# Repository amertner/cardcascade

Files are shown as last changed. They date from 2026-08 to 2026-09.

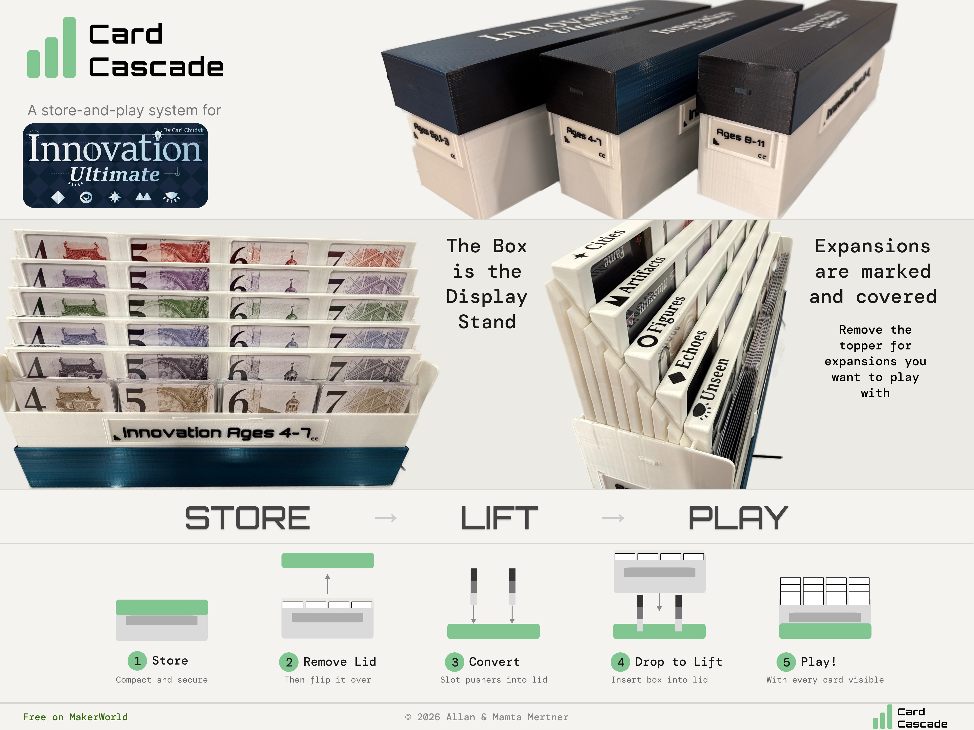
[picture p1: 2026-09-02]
cascades/Innovation/IU Poster Landscape.png

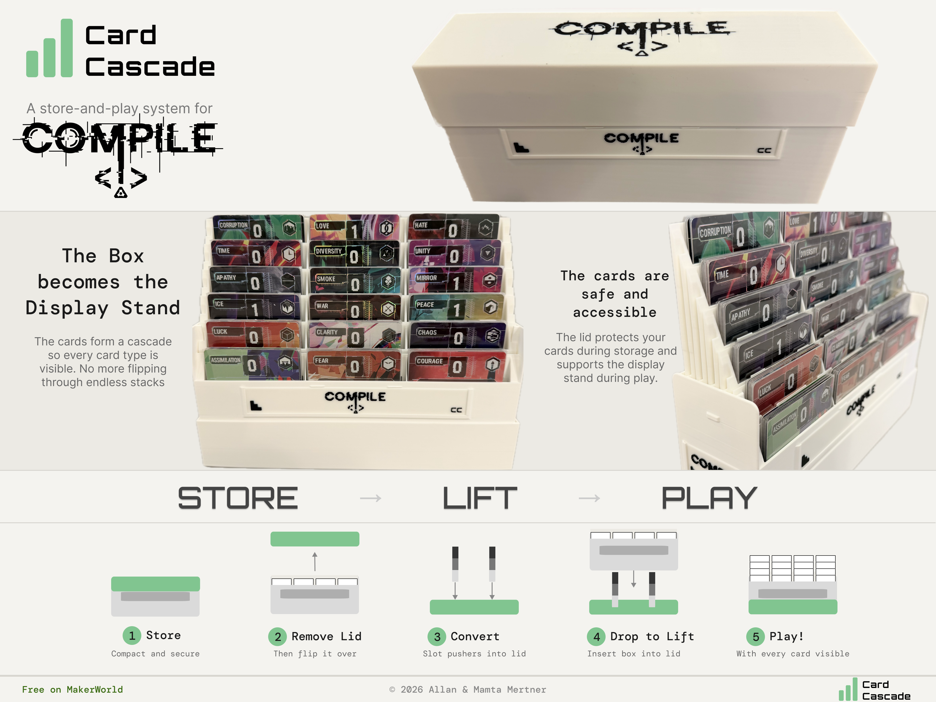
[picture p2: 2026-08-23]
cascades/Compile/Compile Poster.png

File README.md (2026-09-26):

# Card Cascade

3D-printed **store-and-play** boxes for card games: closed, a labelled box
on the shelf; open, the sliding holders rise in a staircase so every pile
shows its top card. Free Bambu Studio projects for Dominion, Innovation,
Compile and Food Chain Magnate on
[MakerWorld](https://makerworld.com/en/collections/33559137-card-cascades).

**Is there one for your game?** [`CATALOGUE.md`](CATALOGUE.md) lists every
cascade with the card size it is cut for, capacity, outside size and the
printer bed it needs; most card games use one of those card sizes. Questions,
prints and requests: [r/cardcascade](https://www.reddit.com/r/cardcascade/).

The rest of this file is about the **labels**; the boxes themselves are
generated from `cad/` (see `cad/README.md` and `CLAUDE.md`).

# Dominion Expansion Box Labels

Generates the expansion-name labels as **two-colour 3MF files** (white
chamfered base plate + black raised name/logo/"cc"), replicating the
original Onshape design. One command produces every name in every size.

## Setup (macOS)

```bash
cd cardcascade
python3 -m venv .venv
.venv/bin/pip install build123d
```

That's it — `Orbitron-Bold.ttf` is bundled (Google Fonts, OFL licence).

> Note: use this bundled *static* Bold TTF. The variable-weight
> `Orbitron[wght].ttf` that Google Fonts' "Download family" button gives
> you crashes the OpenCascade text engine that build123d uses.

## Usage

```bash
# individual label files for every cc.cfg entry of the default game (Dominion)
.venv/bin/python labelmaker.py

# multi-plate Bambu project 3MFs (whole sets + split-box labels)
.venv/bin/python labelmaker.py --plates

# one 3MF per set (default / split boxes / spares plates) — the DEFAULT mode
.venv/bin/python labelmaker.py

# another game (its own cc.cfg entries and width lists)
.venv/bin/python labelmaker.py --game FCM --plates

# specific sets / widths
.venv/bin/python labelmaker.py --names "Seaside,Renaissance" --widths 32,53

# also write STEP files (e.g. to re-import into Onshape)
.venv/bin/python labelmaker.py --step

# skip the blank label
.venv/bin/python labelmaker.py --no-blank

# vanilla 3MF without the Bambu Studio filament metadata
.venv/bin/python labelmaker.py --plain
```

Output lands in `labels_out/` as `<Name>_<width>mm.3mf`, or as
`<game>_plates.3mf` with `--plates`.

Each game in the `GAMES` dict at the top of the script defines the
label widths for a set (`widths`), for split-box `<name> 1/2` labels
(`split_widths`), and the standard text size per width (`caps`,
capital height in mm). Dominion: 156.4 (front), 62, 45, 32 at
6.5/5.0/4.5/3.5 mm caps; FCM: 156.4 (front), 45, 32, 20 at
6.5/4.5/3.5/2.8 mm; Innovation: 156.4 (front), 62, 45, 32, 20 at
6.5/5.0/4.5/3.5/2.8 mm — the 32 and 20 serve the Single Set box, whose
lids are 50.6 and 39.3 mm deep.

## The cc.cfg configuration file

When `--names` is not given, the script reads the configuration from a
`cc.cfg` file (looked up in the current directory, then next to the
script). One set per line as `<game>,<set name>[,<key>=V]...`, where
every value `V` is `<unsleeved>[/<sleeved>][@<box name>:<base model>]`
— side-label widths per sleeving (one value = both; 0 = no side label
for that sleeving) plus the optional recommended-box identity. Plate
titles show the full model composed from the base model and the
plate's width, e.g. `Base Set 560 Card-S (L6.40.12.62-Sl)` — `-U`/`-S`
marks the sleevedness and is omitted on plates covering both. Only
lines
matching `--game` are used:

| Field | Meaning |
|---|---|
| `box=V` | the whole set's box; presence means the set gets whole-box labels |
| `split=V` | both split half-boxes; presence means the set gets `<name> 1/2` labels |
| `split1=V`, `split2=V` | like `split=` but for half-boxes of different sizes (must appear together) |
| `side=<text>` | short text printed on side labels instead of the set name (fronts keep the full name), e.g. `side=FCM/O` |
| `plate=<title>:<w1>+<w2>+...` | an extra plate in the set's 3MF with exactly these label widths — free-form, not limited to the standard widths (used for the Blank set's legacy CC 5.1 sizes); repeatable |
| `parts=<w1>+...@<l1>\|<l2>\|...[#<tag>]` | the set spans several cascades, one per label: fronts read `<name> <label>`, sides just `<label>`. Repeatable, one grouping per way of splitting the set — every grouping becomes a 3MF of its own (see "Per-set project files"), named `<part count> Cascades`, or `<tag> Cascades` when a `#<tag>` is given. Tag a grouping when two would otherwise share a file name, or when the number worth showing is not the box count. A label may contain a comma; only a comma that begins another `key=` splits a field. ` / ` in a label breaks the line (`Innovation / Unseen, Echoes`, the first name over the other two); on a side-width plate a `, ` list is stacked one name a line as well. A stacked label, or one that already starts with the set name, prints as written on the front, without the set-name prefix |
| `names=<w1>+...@<n1>[:<short>]\|<n2>...` | the **transpose** of `parts=`: one plate per *name*, each holding every width, so a plate is exactly one box's labels. For a box design that ships once per expansion. The **narrowest** width takes the short form when one is given; every other width, front and side alike, takes the full name — a long name only shrinks past legibility at the bottom of the range ("Innovation" sets at 1.61 mm on a 20 mm label but 3.11 mm on a 32 mm one), so shortening every side label the way `side=` does for a whole set would waste the room the wider ones have. `(BLANK)` is the blank label |
| none | line is skipped |

Widths are validated against the game's standard width lists — a
non-standard width is an error. (Rule of thumb: the label must be at
least 14 mm narrower than the box lid's depth; pick the largest
standard width that fits.) The special name `(BLANK)` stands for the
blank label (logo + "cc", no text). Blank lines and lines starting
with `#` are ignored:

```
Dominion,Base Set,box=45/62@560 Card:L6.40.12,split=45/62@300 Card:S5.40.12
Dominion,Alchemy,box=32@168 Card:S4.16.10
FCM,Occupations,side=FCM/O,split1=32/45@264 Card:M4.18.12,split2=20@180 Card:L3.18.6
FCM,Milestones,side=FCM/M,box=20/32@144 Card:M5.6.6
```

If there is no `cc.cfg` either, the built-in `NAMES` list at the top
of `labelmaker.py` is used.

## Per-set project files (the default)

The default run writes one Bambu project per set into `cascades/<game>/labels/`, named
`<Set> Labels <version>.3mf` (`--version` overrides the default `6_0`),
using
the recommendations from `cc.cfg`. Labels are stacked one above
the other, centred on the plate. Each file has up to five plates:

1. **single cascade (unsleeved)** — box front (156.4 for Dominion)
   plus the unsleeved `box=` side label
2. **single cascade (sleeved)** — the same with the sleeved width
3. **split cascade (unsleeved)** — front + side for `<name> 1` and
   `<name> 2` (always two fronts and two sides)
4. **split cascade (sleeved)** — the same with the sleeved widths
5. **"... spares"** — every other label from the full width matrix

Sleeved/unsleeved plates that would be identical are collapsed into
one, so a set like Alchemy (`box=32`) has just two plates. Extra
`plate=` plates follow the split plates; labels always sit one per
row, and plates with more than 7 labels overflow onto continuation
plates.

A set with `parts=` groupings is a special case. The groupings are
*alternative* ways to build one set — Innovation goes into three
cascades or into four, never both — so each gets a **file** of its own,
`<Set> <n> Cascades Labels.3mf`, rather than more plates in a shared
one. Its plates (one per width, holding every part at that width) slot
in where the grouping sits in cc.cfg order, and the set's other plates
are repeated in each file so every one is a complete print on its own.
Two groupings that resolve to the same file name are rejected when
`cc.cfg` is read; give one a `#<tag>`, which names it
`<Set> <tag> Cascades Labels.3mf`. There is no plain `<Set> Labels.3mf`
for such a set.

**A tag also fixes a name that counts the wrong thing.** Innovation's
two builds put the same 12 columns into 3 boxes of 4 ages or 4 boxes of
3, so the part count and the ages per cascade are opposite halves of one
split and naming by parts put a "3" on the set whose labels all read four
ages wide. The tags are `#4-Age` and `#3-Age`. They are hyphenated on
purpose: `make_label_covers` lowercases the profile straight into prose,
so `4-Age Cascades` reads "for all 4-age cascades" beside captions saying
CASCADE 1, 2, 3, where `4 Ages Cascades` would put a bare "4" back next
to the word it must not modify. The number has to be stated rather than
derived — counting labels gives boxes, and an open range hides the
specials column, `Ages 9+` being four slots and `Ages 10+` three.

A grouping applies ONE width list to every part, so where the cascades
in a grouping are different box designs, list every width they need
between them and print each box's side off the plate that matches it.
Innovation does this: the first cascade is a 15-card box (45 mm
unsleeved / 62 sleeved) and the rest are 10-card ones (32 / 45), so all
four widths are listed and each plate carries every part at that width.
Because slot 1 always holds the specials and slot k age k-1 whatever
design fills it, the label text depends only on how WIDE a box is, so
those two groupings also cover an all-15-card build — which is why the
earlier specials-last groupings were retired rather than renamed.

**Label geometry is not reproducible run to run.** The same code and
config regenerated twice differ by a few dozen vertices out of tens of
thousands — tessellation noise, not a design change — so a label 3MF
always shows as modified once regenerated, and diffing the binaries
tells you nothing. Compare plate structure and label names instead.

## The multi-plate project files (`--plates`)

`--plates` writes the game's labels into two Bambu Studio projects
spread across 256x256 P1S plates: `<game>_sets_plates.3mf` with every
whole-set label, and `<game>_splits_plates.3mf` with the `<name> 1/2`
split-box labels. Every set gets an identical block of label rows
(widest row on top, e.g. front+80 over 53+32 for Dominion sets), with
a vertical gap between sets, flowing bottom-up through the plates in
cc.cfg order. Blocks avoid the P1's no-print corner and the top strip
of each plate is left free for the wipe tower. Plates are named after
the full list of sets they carry. The
files embed `bambu_project_settings.config` (printer/filament profile,
prime tower enabled, one wipe tower position per plate), so they open
ready to slice with black in slot 1 and white in slot 2. To refresh
that profile, save any project from your own Bambu Studio and copy its
`Metadata/project_settings.config` over `bambu_project_settings.config`.

## Slicing

Each 3MF contains one object with two parts: `base` (white) and
`raised` (black). The file embeds Bambu Studio / OrcaSlicer project
metadata assigning `raised` to filament 1 and `base` to filament 2, so
it opens two-coloured — just load black in slot 1 and white in slot 2.
(Bambu ignores standard 3MF colours; without this metadata everything
lands on filament 1, which is why the file used to open single-colour.)

For other slicers, `--plain` writes a vanilla 3MF instead: the two
parts import as one object and you assign a filament to each part by
hand. On a single-extruder printer, add a filament change at
z = 0.6 mm — all black geometry is above that height.

## Parameters (top of the script, all in mm)

| Parameter | Value | Meaning |
|---|---|---|
| `LABEL_HEIGHT` | 22.2 | overall label height |
| `WIDTHS` | 20, 32, 53, 80, 156.4 | the five label widths |
| `BASE_THICKNESS` | 0.6 | white plate thickness |
| `RAISE_TEXT` | 0.6 | height of the name text above the plate |
| `RAISE_LOGO` | 0.4 | height of the logo and "cc" above the plate |
| `TAPER` | 45° | chamfer around the base |
| `MARGIN` | 3.6 | logo / "cc" inset from the label edge |
| `LOGO_SIZE` | 4.5 | staircase bounding square (3 steps) |
| `TEXT_GAP_ABOVE_LOGO` | 2 | gap between the logo top and the text bottom |
| `TEXT_TOP_MARGIN` | 3 | min gap between the text top and the label top edge |
| `CC_XHEIGHT` | 2.5 | height of the "cc" mark |

Values were measured from the original Onshape STEP export (which is
22.1 mm tall; the script uses the specified 22.2).

The name text is set in Orbitron **Bold** (weight 700 matches the
original's stroke widths exactly) at the game's standard capital
height for the label's width (`caps`), so same-width labels look
uniform. Names too long for their box — flush with the logo's left
edge and the "cc"'s right edge, 2 mm above the logo, at least 3 mm
below the top edge — shrink to fit. Text is centred horizontally and
bottom-anchored.

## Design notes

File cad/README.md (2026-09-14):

# The parametric cascade model — THE design record

The cascade geometry as build123d source, so that a cascade is generated from
`parts.csv` with **zero API calls** and the design is in git.

**This is the authoritative pipeline as of 2026-09-06** (Allan). It began as a
rebuild of the Onshape model and is now the model: new work, changed geometry
and releases go through `cad.build` / `cad.cascade`, and this file and `spec/`
are where the design lives. `automation/PIPELINE.md` describes the Onshape
pipeline it replaced, which is LEGACY — kept runnable, not used. It built
every 7.0 project, now `spec/reference/shipped-7.0/` (it was `cascades/` until
the 7.1 release took that tree over), and `individual/` plus `spec/reference/`
are the corpus that keeps a 7.0 build honest. `cad.cascade` writes a project
without `make_cascade.py` or `refresh_cascades.py`; `verify.py`, `filaments.py`
and `towers.py` are not legacy, and check cad output as well.

**Every part is written: the Pusher, the Box, the Lid, the TokenHolder, the
Holder and the Topper** — the Lid including its logo pattern for all four
games, the TokenHolder in both its configurations, the Topper for all six
expansions. The first printed lids, Dominion's and Innovation's, settled a
question no render could (see "Assemblies" below). Since 2026-09-11 `cascades/` holds the
cad-built 7.1 release, copied from `build/cascades/` and tagged `v7.1`; what
the old pipeline shipped is `spec/reference/shipped-7.0/`, tagged `v7.0`.

The Lid's mark is the most visible place `cad/` deliberately differs from
Onshape (decision 6 lists the rest): it is FITTED to the lid — the biggest
mark that fits, sized to a proportion of the lid — where Onshape draws it at
one or two fixed sizes. `spec/LID.md`, "Sizing the mark", is the record, and
the three constants behind it — `LOGO_WIDTH_FRACTION`, `LOGO_DEPTH_FRACTION`
and `LOGO_CLEAR` — are in `cad/parts/lid.py`.

Fitting is why Innovation's plain mark is GENERATED rather than drawn
(`cad/marks.py`): scaling an outline scales its `0.600` strokes with it, and
Allan's sketch holds them absolute. It is built from Noto Serif and the
geometry hung off the letters — the annulus round the `I`, the five arms
through the `i`'s tittle — every number of it measured off the two drawings it
replaces, which stay in `logos/Innovation/` as its regression reference.

---

## Run it

```
.venv/bin/python -m cad.build                    # 34 pushers -> build/<Game>/
.venv/bin/python -m cad.build --list             # the catalogue, no writing

.venv/bin/python -m cad.build --part lid         # all 108: 52 own, 4 Ultimate, 52 Unmarked — 3 min pooled
.venv/bin/python -m cad.build --part box --model S2.40.12-30.45-Sl
.venv/bin/python -m cad.build --part box         # all 50 — 2 min pooled
.venv/bin/python -m cad.build --part tokenholder # 22, Dominion only, seconds
.venv/bin/python -m cad.build --part holder      # all 56 — 1 min pooled
.venv/bin/python -m cad.build --part all         # all 264 — 3 min; 0 s again
.venv/bin/python -m cad.build --part all --jobs 1 --force   # serial, everything

.venv/bin/python -m cad.assemble --model S4.16.10.32-Un --state all
.venv/bin/python -m cad.fit --model S4.16.10.32-Un --state play
.venv/bin/python -m cad.fit --model S4.16.10.32-Un --no-solids   # seconds
.venv/bin/python -m cad.render \
    "build/assemblies/Dominion/S4.16.10.32-Un play.3mf" --assembly
.venv/bin/python -m cad.assemble --game Innovation --state all      # then LOOK:
.venv/bin/python -m cad.render build/assemblies/Innovation/*play.3mf \
    --assembly --contact tmp/play.png --view hero --view bottom     # the lids' marks, as they print
.venv/bin/python -m cad.render "build/assemblies/Innovation/*closed-lid.3mf" \
    --assembly --contact tmp/closed.png                           # the closed product

.venv/bin/python -m cad.gltf "build/assemblies/<Game>/<model> play.3mf" \
    --filaments '#F4F4F2,#1B1B1B' --part 'Lid=#0E6BA8' -o tmp/cascade.glb
blender -b -P render/cascade.py -- tmp/cascade.glb --view hero --samples 256

.venv/bin/python -m cad.cascade --model S4.16.10.32-Un   # row -> build/cascades/<Game>/<title>.3mf
.venv/bin/python -m cad.cascade --game Dominion --sleeving un --slice   # ... and Studio slices each
.venv/bin/python -m cad.cascade --build                  # every cascade, parts built first if stale
.venv/bin/python -m cad.cascade --list                   # what would be made, and on which bed
.venv/bin/python -m cad.cascade --publish                # the set to UPLOAD: version in the file
                                                         # names, to build/dist/<version>/
.venv/bin/python -m cad.build --part all --version 7.0   # another release -> build/v7.0/,
                                                         # which cad.compare and test_parallel read

.venv/bin/python -m cad.promote --model S4.16.10.32-Un   # LEGACY route: build/ -> planner names ->
automation/refresh_cascades.py --game Dominion --name 168 --sleeving un \
    --components build/components --out build/cascades --auto   # make_cascade with a donor

.venv/bin/python tests/run_all.py                # every suite, concurrently; --quick, --only, --build, --jobs 1
.venv/bin/python tests/test_revisions.py         # any one suite runs alone; run_all.py's table lists them
.venv/bin/python -m cad.render build/*/*.3mf --contact tmp/contact.png
.venv/bin/python -m cad.render build/*/Box*.3mf --box --contact tmp/box.png
```

Builds run in a process pool, one part per job and every core by default
(`--jobs`), and every file gets a STAMP beside it — a digest of its Primary
and of every source file under `cad/`, `logos/` and `fonts/` — so a rerun
with nothing changed skips it in a fraction of a second and any edit
anywhere in `cad/` rebuilds everything that could depend on it. `--force`
ignores the stamps. `--model` matches on the filename and is how to build
one. `--box` on the renderer swaps the camera: its default is aimed at a
pusher lying flat and renders a 105 mm-tall box as a squashed ribbon.

`build/` is disposable and gitignored. Rebuilding unchanged source gives
byte-identical files — the pool included, proven by a pooled rebuild of the
serial catalogue changing nothing — so `cad.build` reports `changed` only
when something really moved. Six holders are two geometries under two names
each (the Mat twins); one is built and the other is its bytes.

## Layout

```
cad/
  params.py     Primary — the 10 inputs, frozen; loads a parts.csv row
  derive.py     Primary -> Derived. EVERY formula, once.
  tables.py     per-game lookups, transcribed from the variable studio
  lock.py       LOCK_STANDARD.md in code; shared by box, lid, pusher
  revisions.py  the release line and its named flags — the ONE place a release change lives
  text.py       fonts and the sizing rules
  marks.py      every lid mark, drawn or generated, behind one interface
  geom.py       slab, tray, text_solid — the three shapes every part drew itself
  art.py        imported 2D artwork: a DXF's loops -> filled regions
  mesh3mf.py    read/write a component 3MF in the shape Onshape's have
  build.py      the CLI: parts.csv -> build/<Game>/*.3mf
  render.py     shaded PNGs, for looking at a build without Studio
  assembly.py   WHERE each part goes — placements, and nothing else
  assemble.py   the CLI: parts.csv -> build/assemblies/<Game>/*.3mf
  fit.py        interference and margins — the reason the assemblies exist
  gltf.py       an assembly -> .glb, for a renderer that can light it
  lazy.py       a module imported on first use; keeps build123d out of --list
  refuse.py     Refused — the one exception every guard raises, caught once per CLI
  project.py    a Bambu Studio project written from parts and placements, no donor — spec/PROJECT.md
  layout.py     the plate scheme, bed, 45-degree packing and tower, lifted from make_cascade
  cascade.py    a parts.csv row -> its parts under build/ and its project title
  compare.py    the Onshape-shipped 7.0 projects vs their cad twins — a regression check
  promote.py    LEGACY: stages build/ under the planner's names for refresh_cascades
  parts/
    pusher.py   done
    box.py      done
    lid.py      done, logo pattern included — see spec/LID.md
    token_holder.py  done — FULL and HALF, Dominion only
    holder.py   done — see spec/HOLDER.md
    topper.py   done — the blank and all six expansions; see spec/TOPPER.md
render/
  cascade.py    Blender/Cycles. Runs in BLENDER's python, not the venv
spec/
  ASSEMBLY.md   where each part goes in a whole cascade, and what settled it
  RENDER.md     two renderers, and why they are two
  DERIVED.md    the Onshape variable studio, transcribed, and what it settled
  UNKNOWNS.md  every constant that holds but is not derived, and what would settle it
  PUSHER.md     the Pusher measured, and what the rebuild reproduces
  BOX.md        the same for the Box
  LID.md        the same for the Lid
  TOKENHOLDER.md the same for the TokenHolder, both configurations
  HOLDER.md     the same for the Holder, and where it diverges on purpose
  TOPPER.md     the same for the Topper, all six expansions
  PROJECT.md    the Bambu Studio project cad.cascade writes
  REVISIONS.md  the release line, and what changed at each release
  reference/    hand-exported STEPs — the ground truth, 0 API calls — and
                shipped-7.0/, the projects the Onshape pipeline shipped
tests/
  run_all.py    runs every suite; its table is the list of them
  reference.py  pins 7.0 for every test that compares against a reference
  probe.py      ray-casting a mesh: the corpus tests' instrument
  test_*.py     a suite per part (vs its STEPs), per corpus (vs individual/),
                and per rule (floors, meshes, releases, layout, project)
  holder_diff.py, box_diff.py   dev loops, band by band and lump by lump, not tests
```

## What this replaces, and what it does not

**Replaces** (~130 KB whose entire job is rationing and reconstructing API
calls): `plan_exports.py`, `export.py`, `onshape.py`, `onshape_config.py`,
`onshape_test.py`, `set_variables.py`, `provenance.py`, `mesh.py`,
`assembly_split.py`, `topper_split.py`.

**Leaves standing**: `individual/<Game>/`, as the regression corpus, and the
checks that read components — `verify.py`, `filaments.py`, `towers.py`. A
written component has the shape of a cached one, if not its bytes.

Two of the retired modules deserve a note, because they are good code solving a
problem that only exists upstream. `assembly_split.py` tells `Holder` from
`FirstHolder` **by height**, because an assembly export names both `Holder`.
`topper_split.py` identifies six same-named assembly instances by **glyph widths
as a fraction of word width**. Generated locally, both parts simply get named.

## Two typefaces, both identified rather than assumed

`fonts/Orbitron-Bold.ttf` — already used by `labelmaker.py` — sets the product
name and version. `fonts/OpenSans-Bold.ttf` sets the detail line, because
Orbitron is a wide geometric face and Open Sans fits more text in the same
space. Both are Google Fonts under the OFL.

The weight matters and was tested, not guessed: against the reference STEPs
Open Sans **Bold** lands within `0.0006 mm`, where SemiBold is out by `0.17`
and Regular by `0.34`. The thin `l` is what separates them.

## Text sizing is a rule, not a transcription, and it has a floor

Since 2026-09-04 every text placement is FLOORED (`cad/text.py`, "floors"):
text cut into a part is set no smaller than a `0.200` mm stroke and text that
stands proud — embossed, or a second-filament inlay — no smaller than `0.250`,
each face's thinnest stroke measured off a raster of the strings it sets. A
line under its floor is raised to it and gives up margin; one that would then
overrun the part raises `DoesNotFit` rather than write it. It raises
sixteen lines across the catalogue — four pusher version lines, one detail
line, nine box lines, and the 10-card unsleeved toppers' names, whose inlay
prints face down in a pocket and so takes the CUT floor (`spec/TOPPER.md`).
`tests/test_text_floors.py` asserts the set exactly.

Onshape can constrain sketch text in only one dimension, so a box that suits
one parameter set does not suit another — the same string comes out `3.85x`
bigger on one reference than the other. `cad/text.py` fits **both** dimensions
instead, and `tests/test_pusher.py` holds the result to its own bounds on all
34 pushers, not just the two references. `spec/PUSHER.md` has the numbers.

## Assemblies, and the one thing they found

`cad/assembly.py` places the parts into a whole cascade — **closed**, **closed
with the lid on**, and **cascaded** for play — and `cad/fit.py` measures the
result. This is the first thing in the repo that can check the MECHANISM rather
than a part: every clearance in the design is asserted one part at a time today,
against a reference that only ever shows that part.

It is a separate module for the reason `derive.py` is one: every formula once,
every placement once. `assembly.py` imports no build123d, so the mates are pure
arithmetic and testable on their own, and it introduces no constant of its own —
each placement is derived from `derive.py` and the part modules, and
`spec/ASSEMBLY.md` records what settled it.

On Dominion `S4.16.10.32-Un` every pair of source-built parts intersects in
**0.0000 mm3** in all three states, and every named margin lands on its nominal
to 0.001. Two findings came out of it:

* **A pusher's treads sit 0.150 forward of the box's slider ribs, on every
  cascade** — a constant, with every parameter cancelling — which leaves a
  holder on its tread with 0.350 at the front and 0.050 at the back. Nothing is
  broken by it, and nothing before now could see it.
* **Three of the four games' lid marks were 180 degrees from the fourth.** A
  closed lid can go on either way round — nothing geometric distinguishes the
  two, and both measure 0.0000 mm3 — so the only thing that can tell is the
  logo, and Dominion's disagreed with Compile's, FCM's and Innovation's. One
  game was upside down whichever way was chosen, on the shipped product as
  much as here: `cad/` rotates no artwork, and its inlays matched the cached
  Onshape lids to 0.001. Dominion's DXF was turned on 2026-09-04 from a
  photograph of the shipped Innovation boxes, and turned BACK on 2026-09-11
  when a printed Dominion lid came out upside down. A printed Innovation lid
  did too, and its generated mark now goes in turned
  (`tables.LID_LOGO_TURNED`); the photograph had been misread. Compile and
  FCM are predicted upside down as well and are open until printed
  (`spec/LID.md`).

`spec/ASSEMBLY.md` has both. The second is the case for treating renders as
part of the checking rather than its output: it is invisible to every number
`cad/fit.py` computes.

## Seven decisions

**1. Derived variables live in exactly one module, and a shared formula too.**
`derive.py` takes a `Primary` and returns a frozen `Derived`. Component modules
read from it and never recompute. The rule is narrower than "every formula":
the variable studio is transcribed in full, a sketch variable joins it when
more than one module reads it (`#BoxWidth`, `#calPusherSlots`), and a
part-studio formula two parts share is written once there (`cascade_slope`,
`back_slot_pitch`) — the Box's lip angle and the Holder's slant were the same
expression transcribed as reciprocals of each other until it was. A formula
one part uses stays in that part. This mirrors Onshape (variable studio → part
studios read the variables), makes the derived layer testable on its own, and is
the only way the same quantity — inner box width, say — stays identical across
Box, Lid and Holder. `Derived` is frozen so a part cannot write to it.

**2. `build()` returns B-rep, not mesh.**
Meshing is the last step, in `mesh3mf.py`. Tests assert on faces and edges at
exact coordinates. This is the upgrade over the Onshape pipeline, where a mesh is
all Onshape hands back: `verify.py` chains 2D section loops and probes a 900×300
grid to find a pusher tab, and `check_box`'s 1.2 mm depth tolerance is a
concession to that. From a B-rep you know where the tab is because you put it
there.

**3. Build to `build/`, never over `individual/`.**
`individual/` is 242 components and 68 raw assemblies — the only ground truth
there is, and unreproducible at any sane API cost. It is frozen and read-only
for good: every component type has passed regression against it, and it stays
the corpus a 7.0 build is held to.

**4. One lock: 7.0's.**
`lock.py` is the 7.0 catalogue and every release on the line keeps it
(`lock.SAME_LOCK`, 7.0 through 7.2f); `pusher.build` **refuses** a `Primary` at
any version outside it rather than stamp `CC 6.6` on 7.0 tabs. The Lid is the same
story on its own half of the lock: a 7.0 lid is told from a pre-7.0 one by a
`1.700` recess step against the pre-7.0 `1.800`, and `tests/test_lid_corpus.py`
asserts the first group and reports the second — all 48 cached lids are 7.0
since the September refreshes, as are all 48 boxes (`tests/test_box_corpus.py`). A pre-7.0 pusher put
its tabs at a fixed inset from the two depth edges instead (4.20 front, 4.00
back, notch always — measured identical on all 14 still-6.6 pushers in
`individual/`), and nothing here reproduces that. `build/` was the migration
TARGET, not a mirror — it reproduces the 18 pushers Onshape had re-cut and
moves the other 14 onto the catalogue — and the 7.1 release completed the
migration: every cascade in `cascades/` is cad-built. `derive.py` keeps the pre-7.0 variables because it is a
transcription of the studio and they are still in it — nothing reads them.

**5. The Pusher name carries the first-riser axis.**
A pusher's depth depends on `FirstSlidingSlotCards`, but `plan_exports` keys it
`(risers, cards, sleeved)` — so Dominion `324 Card` and `290 Card (Mat)` collide
on `Pusher 6x10-*.3mf` and differ by 1.20 mm sleeved. `build.py` writes
`Pusher 6x10-12-Sl.3mf` for the override, following parts.csv's own model-code
convention (`M6.21.10/12`, with `/` folded to `-`). Four files are consequently
named differently from `individual/` and two are new. `pusher_file(d,
legacy=True)` gives the old name, which is how `tests/test_pusher_regression.py`
finds a pusher's cached twin, and the legacy `cad.promote` refuses where two
built files would land on one planner name.

**6. Where the rebuild diverges from Onshape, it says so and tests both sides.**
The Box's hanging holes are cut through the rear storage dividers in Onshape —
on `Box Dominion 244S` all three, at full width, so each is severed at every
hole row. `cad/` stops them at the slot band and leaves the dividers solid
(Allan). The Box's version line is the second: Onshape's sketches still read
`Rev <version>` and Allan wants `calVersion`, as the Lid has, so the build
engraves `CC 7.0` where every reference engraves `Rev 7.0`. The third is the
XS box's front label holder, which in Onshape carries no fastener at all — the
build puts one in the middle, the only place a `10.000` ridge fits on a
`65.600` holder. The Holder's slot mouth is a fourth — flared 45 degrees for
its bottom 0.300 so an elephant's foot closes the chamfer and not the groove
(`spec/HOLDER.md`) — and the Lid's fitted mark a fifth. The rule these set
is the point: a divergence is recorded in `spec/`, and asserted from both ends
— the build has the new behaviour, the reference still has the old one — so
re-converging fails the tests rather than passing quietly. Anything else that
differs from a reference is a bug.

**7. A RELEASE change is not a divergence, and it lives in one place.**
A divergence is `cad/` against Onshape at the SAME version, forever. A release
change is `cad/` 7.0 against `cad/` 7.1 — the Lid's one socket per pusher is
the first — and it lives in `cad/revisions.py`, reaching a part as a NAMED
flag on the Derived (`d.rev.lid_socket_per_pusher`), never as a version
comparison. A build at the older release must keep reproducing `individual/`
exactly, which is why every test that compares against a reference pins its
release through `tests/reference.py` rather than taking the default: the
default is 7.2f and will move again. `spec/REVISIONS.md` is the record and
`tests/test_revisions.py` asserts every flag at both releases.
A flag does not have to reach a PART: `both_lid_editions` (7.1d) and
`unmarked_lid` (7.2b) are read by `build.lid_variants_built` and
`cascade.parts`, because what they change is how many lids a cascade has and
not what any one of them is — the unmarked lid is a `tables.LID_VARIANTS`
member the part builds at any release. The rule is the same
wherever it is read — a named question, never a version comparison.

## One record below `derive`

A `Primary` is the parts.csv row's inputs and nothing else — the studio's
nine, the `Version`, and the `cad/`-only ROW OPTIONS the studio has no
counterpart for (`LabelHolders`, `SleevedCardWidth`, `UnsleevedCardWidth`,
`DeepSlotAtBack`, and `BackPocket`, which is set per built variant rather
than read off a row); `derive`
turns it into a `Derived`, and the Derived carries them all by name
beside everything computed from them — `d.HorizontalSlots` next to
`d.calSlotwidth`, as every Onshape part studio reads them. So every
function below `derive` — a part's features and its `build`, a placement
in `assembly`, a margin in `fit`, a file name in `build` — takes `d` and
nothing else. That is also what lets a VARIANT of a part be built without a
variant build path: `build.plain_box_twin` and `build.back_pocket_twin`
rebuild the Primary off the Derived, replace one field and re-derive, and
`build_box` never learns there was a choice. A Primary is handled only where rows come in: `params`, the
catalogues, the stamps. Until 2026-09-06 every feature took `(p, d)`, a
carry-over from Onshape's split between the variable studio's inputs and
its outputs that has no counterpart in one Python record.

## What each part is checked against

The Pusher and the Box have hand-exported STEPs and nothing else; the Lid has
both — four structural STEPs **and** 48 cached meshes in `individual/`. Both
are used, because they answer different questions. A STEP is exact and gives
faces, so it settles a section; four of them cannot tell a rule from a
coincidence across a 50-lid catalogue, which is what the meshes are for.

Neither settles WHY, and on the Lid that mattered twice. Two placements
reproduced all 48 lids exactly and were still attached to the wrong datum — the
engraving hung off the pusher sockets where the sketch hangs it off the wall,
and the socket set read as centred with a mysterious `-0.300` where the sketch
anchors its first socket and lets the margin fall where it falls. Both are
recorded in `spec/LID.md` under "What the fit got wrong", because the lesson
generalises: a rule that reproduces the whole catalogue can still be the wrong
rule, and the tell is a term no derived variable produces.

## Order of work

The **Pusher** first, and it is done. It is the simplest part;
`LOCK_STANDARD.md` already specifies its post-7.0 geometry completely;
`verify.py --pushers` is an existing pass/fail oracle; there are 32 cached
pushers to regress against; and the C1–C5 re-cut it is owed costs a real slice
of the API budget the moment it is done in Onshape instead.

Then the **Box**, which went first in the end because Allan had its feature
tree and five STEPs to hand, and then the **Lid**: shell, sockets, closing
grooves, outer rounds, the floor's engraving and the logo pattern, the artwork
for all four games and the rule behind the logo's scale.

Then the **TokenHolder**, which is done: it is the simplest part in the
catalogue after the Pusher, it has a STEP for each of its two configurations,
and — alone so far — its 18 cached components are a REGRESSION target rather
than a shape reference, because it did not change in 7.0.

Then the **Holder**, which is done, including the two features no kernel will
compute for itself — `Fillet 1`, whose two rounds meet exactly, and the chamfer
on `Lip Rest` — both modelled into their cuts and both measured. It is also the
part that found the one meshing bug in the writer (`spec/HOLDER.md`, "The mesh").

Then the **Topper**, which is done: the blank and all six expansions, the five
marks derived from `calLogoSidelength` rather than traced (`spec/TOPPER.md`).

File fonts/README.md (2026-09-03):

# Bundled typefaces

All from [Google Fonts](https://fonts.google.com/), all under the SIL Open
Font License 1.1, which allows redistribution with the licence text. Kept in
the repository rather than fetched, so a build needs no network and cannot
silently pick up a different release of a face the geometry was fitted to.

| file | used by | for |
|---|---|---|
| `Orbitron-Bold.ttf` | `cad/text.py`, `labelmaker.py` | the product name and version engraved on the parts |
| `OpenSans-Bold.ttf` | `cad/text.py` | the detail line |
| `NotoSerif-Regular.ttf` | `cad/marks.py` | the Innovation wordmark |
| `NotoSerif-Bold.ttf` | `cad/parts/topper.py` | the Topper's expansion names |
| `NotoSerif-BoldItalic.ttf` | — | `Ultimate`, when that mark is rebuilt too |
| `Inter-Regular.ttf`, `DMMono-*.ttf` | `labelmaker.py` | the printed labels |

`NotoSerif-Regular.ttf` and `NotoSerif-BoldItalic.ttf` are static instances cut
from Google's variable fonts (`NotoSerif[wdth,wght]` at `wght 400 / wdth 100`,
and the Italic at `wght 700`) with `fontTools.varLib.instancer` — upstream
ships only the variable files, and build123d's `Text` wants a static face.
`OFL-NotoSerif.txt` is their licence; the others carry the same one.

**`NotoSerif-Bold.ttf` came a different way** and it is worth saying so: it was
served by the Google Fonts CSS API (`fonts.gstatic.com`) rather than cut here,
because the variable font lives on GitHub and this session's GitHub access is
scoped to one repository. It is the **same release, 2.015**, as the Regular
beside it, with the same `unitsPerEm` and `sCapHeight`, but it is SUBSET —
3178 glyphs against the Regular's 3830. That is ample for six English
expansion names and would not be for anything else. Re-cut it from the
variable font if this ever needs to set text outside basic Latin.

**Which face a mark is set in is a measurement, not a choice** — see
`cad/text.py` for Orbitron and Open Sans, and `spec/LID.md` for Noto Serif,
which was confirmed against Allan's own drawing to `0.019 mm` over 109 mm of
wordmark before anything was built with it.

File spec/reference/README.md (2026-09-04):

# Reference exports

Hand-exported from Onshape — the UI download, which costs **0 API calls**, not
the API translate path that `automation/onshape_api_log.csv` meters.

These are the ground truth `cad/` is checked against. `tests/test_pusher.py`
compares every X-normal face area, the whole mid-plate outline, the tab tops
and the volume against them, so they need to stay byte-stable: re-export only
to capture a deliberate CAD change, and say which change in the commit.

### Pusher

| file | cascade | primaries |
|---|---|---|
| `Pusher S4.7.7.32-Sl.step` | Compile 105 Card Sleeved | `H3 R4 fc7 cps7` no override, sleeved, 7.0 |
| `Pusher S2.40.12-30.45-Sl.step` | Dominion 246 Card Sleeved | `H3 R2 fc40 cps12` first riser 30, sleeved, 7.0 |

The pair is chosen to split the design: four equal risers against two with a
first-riser override, `C3` both times so the lock is held constant. The
Dominion one is what settles which step takes `calFirstSliderDistance` — see
`spec/PUSHER.md`.

Both are in **assembly position**: X `+3.000`, Y `0`, and Z at
`-calHeightIncrement` — `-18.000` on Compile (rise 18.000) and `-16.000` on
Dominion (rise 16.000). The rule is confirmed on all 32 component 3MFs in
`individual/`, and `pusher.assembly_offset` is it. Tests still align on the
bounding box, because that stays right if a future part places differently.

### Box

Five, because the Box has more independent axes than the Pusher did. What each
one splits, and what has been measured off them, is in `spec/BOX.md`.

| file | cascade |
|---|---|
| `Box Compile 105S.step` | Compile 105 Card Sl `S4.7.7.32-Sl` — S: 3 slots, 2 pusher slots, and the same cascade as the Pusher STEP above, so the box's rim cutouts can be checked against that pusher's tabs |
| `Box Dominion 244S.step` | Dominion 244 Card Sl `M4.21.10.45-Sl` — M: 4 slots, 3 pusher slots |
| `Box Dominion 202S Merged.step` | Dominion 202 Card (Mat) Sl — the SAME model code with `MatPocket = 1`, so the merge is isolated to `758.957 mm³` and 47 faces |
| `Box Dominion 650S.step` | Dominion 650 Card Sl `L8.50.10.62-Sl` — L: 5 slots, deepest box, the only C5 lock |
| `Box FCM 72S.step` | **not a parts.csv row** — scratch parameters (FCM Sl, `H3 R3 fc6 cps6`) Allan exported as an extra. Kept: it is the smallest box and the only C2 lock |
| `Box Dominion 246S.step` | Dominion 246 Card Sl `S2.40.12/30.45-Sl` — the only one with a first-riser override, so the only one that can tell `calFirstSliderDistance` from `calSliderDistance` |
| `Box Dominion 246S without final fillet.step` | the same box with `Smooth box edges` suppressed. The PAIR is the point: it makes the last feature measurable (`0.600`, `129.190 mm³`) instead of a query to be guessed at, and it is the solid `cad/parts/box.py` is built against |
| `Box Innovation S5.15.15.62-Sl without label holders.step` | Innovation `4 Later Ages` Sl `S5.15.15.62-Sl` exported with `isLabelHoldersOnBox = 0` (2026-09-04) — the branch no catalogue row reaches. `#BoxWidth + 2.000` by `#BoxDepth + 4.500`: a closing bump each end and the rear block, and nothing else |

### Lid

Eight. What each one splits, and what has been measured off them, is in
`spec/LID.md`.

| file | cascade |
|---|---|
| `Lid Dominion 246S.step` | Dominion 246 Card Sl `S2.40.12/30.45-Sl` — the only one with a first-riser override, and the cascade whose Box and Pusher are both referenced above, so the 7.0 lock can be followed across all three parts of one design. The only export taken **without** the logo meshes embedded |
| `Lid Dominion 246S with logo.step` | the same lid with them embedded. The PAIR is the point: it makes the pattern pocket measurable on its own (`0.810` deep, `975.420` of footprint) instead of a feature to be guessed at — the same trick as the Box's filleted/unfilleted pair |
| `Lid Dominion 244U.step` | Dominion 244 Card Un `M4.21.10.32-Un` — M: three sockets, unsleeved |
| `Lid Dominion 333S.step` | Dominion 333 Card Sl `S9.21.10.62-Sl` — `RisingSliders 9`, past the logo block's eight-riser branch, and the only C5 lock among them |
| `Lid Innovation 130U.step` | Innovation 130 Card Un `XS5.15.10.32-Un` — XS: the narrowest lid, two horizontal slots, 31 pattern inlays, and the only one whose logo carries no staircase |
| `Lid Compile 126S.step` | Compile 126 Card Sl `S5.7.7.45-Sl` — a **second game's card size**, which nothing else here reaches, and the only Lid reference whose lock is C4. It found two bugs in the test's own probes on the day it arrived |
| `Lid FCM 105S.step` | **not a parts.csv row** — `213.900 x 44.700`, which no FCM row produces. Its staircase and sockets pin it to `RisingSliders 4` and `calSlotwidth 65.000`, which still leaves four model codes that differ only in the text engraved on the floor. Kept for its artwork, not as a structural reference |
| `Lid Innovation 270S.step` | Innovation 270 Card Sl `S5.15.15.62-Sl` — the `#LogoScaleFactor 1` export. Its LETTERS are sound and pinned Noto Serif Bold Italic for `Ultimate`; its **flourishes are corrupted** (two pattern instances missing, the rest displaced), so its artwork is not used. `spec/LID.md` has the comparison |
| `Lid Innovation M5.15.15.45-Un with logo.step` | Innovation `4 Later Ages` Un `M5.15.15.45-Un` — the **corrected** `#LogoScaleFactor 1` Ultimate export (2026-09-04), the U's underline boxes placed as the sketch has them. `logos/Innovation/lid_logo_big.brep` is lifted from its 31 inlays as faces — exact, where a DXF re-fits the spline holes |

Each Lid file holds the lid body **plus** the logo pattern's inlays as separate
solids. The body is the biggest by volume, which is how the tests take it — and
the inlays are where `logos/<Game>/*.dxf` came from, lifted by
`make_lid_logo_dxf.py`. Four of the five marks now come from a STEP; only
Innovation's big one is still lifted from a cached mesh, for want of an export
whose flourishes are intact.

### TokenHolder

Two, and they are the SAME cascade — Dominion `324 Card` Sl,
`M6.21.10.62-Sl` — exported in both configurations. What has been measured off
them is in `spec/TOKENHOLDER.md`.

| file | configuration |
|---|---|
| `TokenHolder M6.21.10.62-Sl.step` | FULL — the tray takes the whole front pocket, `calFrontPocketDepth` deep |
| `HalfTokenHolder M6.21.10.62-Sl.step` | HALF — `2.600 + calFrontPocketDepth/2`. The PAIR is the point: one configuration exported twice, so the diff isolates what `half` changes, which turns out to be one number. Same 231 faces and 644 edges on both |
| `HalfTokenHolder M6.21.10.45-Un.step` | the same row UNSLEEVED, as the HALF (2026-09-04): `5.790` deep, and its string ends in `n` where the sleeved one ends in `l` — the export that showed `TRAIL` belongs to the text box and not to the last glyph |
| `HalfTokenHolder M4.21.10.45-M-Sl.step` | Dominion `202 Card (Mat)` Sl, the merged HALF (2026-09-04): `8.100` deep, `128.100` wide, and one of the three trays whose Onshape text is CLIPPED — the exact record of the text divergence `spec/TOKENHOLDER.md` describes |

Neither is unsleeved and neither is merged, so the unsleeved widths, the doubled
merged width and the single centred divider at 128 mm all rest on the 18 cached
meshes in `individual/Dominion/` instead — which, unusually, ARE a regression
target here: the token holder did not change in 7.0 (Allan), so only the
engraved version string differs. `tests/test_token_holder_corpus.py`.

### Holder

Ten — the most of any part, because the Holder has the most axes to split and
because its width constant had to be told from a near miss: `individual/` holds
holders `0.200` wider that are otherwise identical to the micron, and every one
of these ten says `+9.800`. What has been measured off them is in
`spec/HOLDER.md`; `tests/test_holder.py` asserts against all ten.

| file | cascade |
|---|---|
| `Holder S2.40.12-30.45-Sl.step` | Dominion `246 Card` Sl — the row with a first-riser override, and the cascade whose Box, Lid and Pusher are all referenced above |
| `FirstHolder S2.40.12-30.45-Sl.step` | the same configuration exported as its FIRST riser. The PAIR is the point, and this one is load-bearing: `calSliderDistance 9.600` against `calFirstSliderDistance 20.400`, so everything keyed to a slider distance — the depth, the slant, the lip's reach — is asserted against a case that fails outright if the wrong one is used. Everywhere else in the catalogue the two are equal |
| `Holder S9.21.10.62-Sl.step` | Dominion `333 Card` Sl — nine risers, the catalogue's shallowest rise, and the only reference whose back wall still reaches up behind the finger scallop. That is what caught a scallop cut through it, and what places `Lip Rest`'s oblique sweep |
| `Holder S9.21.10.62-Sl after Lip Rest.step` | `333` ROLLED BACK to after `Lip Rest` (2026-09-04): one lip and one unchamfered rest, the other five lips not yet patterned. Settled the rest's section — `LIP_LEN` wide, exactly |
| `Holder S9.21.10.62-Sl after Chamfer lip rest.step` | " to after `Chamfer lip rest`. The PAIR isolates the chamfer: `1.143 mm3` per rest, a `13.000 / 10.444` trapezoid mouth, reproduced to `0.000` |
| `Holder S9.21.10.62-Sl before Fillet 1.step` | " to before `Fillet 1` — early enough that the slant, the floor drop, the scallops, the end blocks, the side slots and the lips are all still to come. Filed; not yet asserted against |
| `Holder M5.10.10.45-Sl.step` | Innovation `4 Later Ages` Sl — a SPANNING game, four compartments, `calSlotwidth 69.000`. Everything measured on the Dominion three was `65.000` and three compartments until this arrived |
| `Holder M5.10.10.32-Un.step` | the same row unsleeved, `67.000` |
| `Holder XS5.15.10.45-Sl.step` | Innovation `Single Mini` Sl — TWO compartments, the narrowest holder, and one of the two whose Onshape text collides with itself |
| `Holder S4.7.7.32-Sl.step` | Compile `105 Card` Sl — `calSlotwidth 70.000`, and the export that killed a `COMPILE_DEPTH_CARDS` override by satisfying the plain rule exactly |
| `Holder S4.18.12.32-Un.step` | FCM `198 Card` Un — `63.000`, the narrowest slot, and the game's only reference |
| `Holder L5.7.7.45-Sl.step` | Compile `210 Card` Sl — five compartments, the widest holder in the catalogue. **Re-exported 2026-09-03**: the first export of this row was 12 cards deep where the row says 7, and was the one thing in the catalogue that did not satisfy the depth rule. Allan confirmed the row holds 7, and the re-export measures `7.600` — the plain rule, exactly. The old file is in git history |
| `Holder L5.7.7.20-Un.step` | the same row unsleeved — **re-exported 2026-09-03** alongside its twin, and the other half of the same mis-configuration: 12 cards again, under `calCardThickness 0.400` this time, which is what made it a card COUNT rather than an offset. The re-export measures `4.800`, the rule under that thickness. The only reference at `calSlotwidth 68.000` |

A reference that fails a rule every other reference satisfies is a question
about that reference first. Holding these two out — rather than fitting the rule
to them — is what made the re-exports worth asking for; both landed on the rule
to the thousandth. `tests/test_holder.py` keeps its `HELD_OUT` list, now empty,
for the next time.

### Topper

Eleven, and between them they made the Topper solvable without a single API
call. Innovation only — no other game's studio has one.

| file | what it isolates |
|---|---|
| `Topper Blank M5.10.10.32-Un without top and front edges.step` | the last feature SUPPRESSED, so every dimension can be read without a blend in the way. One solid, 133 faces |
| `Topper M5.15.15.62-Sl to Remove Inner Hole.step` | the feature tree ROLLED BACK to that feature |
| `Topper M5.15.15.62-Sl after More Dividers.step` | " |
| `Topper M5.15.15.62-Sl after Linear pattern 1.step` | " — the last before `Upside Down`. The three bracket every group of the blank, so each is a subtraction rather than an inference |
| `Topper Unseen M5.10.10.32-Un.step` | 10 cards unsleeved |
| `Topper Unseen M5.15.15.45-Un.step` | 15 cards unsleeved — the PAIR with the one above, so only the card count differs |
| `Topper Artifacts / Cities / Echoes / Figures / Unseen M5.15.15.62-Sl.step` | all five expansions at one parameter set, which is what solved the five marks |
| `Topper Artifacts / Cities / Figures S5.15.15.62-Sl.step` | three of the five at SIZE S (2026-09-04) — three horizontal slots, a different `calLogoSidelength` — which confirmed `Artifacts`' and `Cities`' vertex placement at a second size |
| `Topper Blank S5.15.15.45-Un.step` | the first FILLETED blank reference, and the third parameter set for `BAND_HALF` and `LIP_ROOM_RISE` (2026-09-04) |

A named export carries the topper body **plus** every engraved piece as its own
solid — 13 for `Unseen`. The body is the biggest by volume and **is the BLANK
topper**: the blank is not a different part, it is this one without its name
and logo, so no separate blank export is needed. Differencing the source's
blank against a named body gives the engraving exactly, which is how the marks
were derived rather than traced.

`spec/TOPPER.md` has the measurements. Two things worth knowing here: the
sleeved `Unseen` files in `individual/` are STALE and these STEPs are not, and
`Solid.volume` is not a safe metric on a named body — OCCT over-reports it by
about 1 mm3, on these exports as much as on the source.

At 2.1 MB gzipped for the Boxes and 3.4 MB for the Lids they cost the repo
almost nothing, and a re-export costs an hour of somebody's afternoon rather
than any API budget.

### Text

| file | what it is |
|---|---|
| `Text right-aligned sample.step` | a `145 x 75 x 3` plate with three lines of text standing `1.000` proud (2026-09-04): `Sample Open Sans` (Open Sans Regular, not on file here), `Open Sans Bold` and `Orbitron`, each in a text box `10.000` tall, the three boxes sharing one right edge `17.220` from the plate's edge — `x 110.135`. The Open Sans Bold line ends its ink `0.0646` em short of that edge: the holder's `CAP_TRAIL`, confirmed. The Orbitron line's run is 1.4 % short of Orbitron Bold's, so it is most likely the Regular weight and is not used. `Text right-aligned sample.dxf` is the same sketch as outlines (391 splines, 148 lines; the boxes are construction geometry and not exported) |
| `Text right-aligned sample 2.step` | the same plate with a fourth line, `Orbitron Bold`, right-aligned to the same edge (2026-09-04). Its ink ends `0.0761 ±0.0004` em short of the edge — the tray's `TRAIL` mechanism, on the parts' own weight — and with the Open Sans line's `0.0646` it is what settled both constants as a quarter of the font's space advance |

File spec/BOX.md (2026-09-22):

# The Box, measured

Allan supplied the part studio's feature tree and the two sketch variables on
2026-09-01, plus five hand-exported STEPs in `spec/reference/` (0 API calls). This
file records the transcription and what it has been checked against; it is the
Box's counterpart to `spec/PUSHER.md`, and is incomplete until `cad/parts/box.py`
exists.

---

## The envelope, exact on all 48 boxes

```
#BoxWidth = #WallThickness*2 + 11.1mm + #calSlotwidth*#HorizontalSlots
#BoxDepth = (6mm + (#RisingSliders-1)*#calSliderDistance
             + #calFirstSliderDistance) + #calFrontPocketDepth
```

Height is `BoxHeight`, `105.00` throughout.

The sketch box is **centred on the origin**: on `Box Compile 105S` the outer
walls are planar faces at `x = ±112.150`, which is `#BoxWidth / 2` for
`224.300`, and the inner walls at `±110.550` — `WallThickness 1.600`, confirmed
rather than assumed.

Both formulas reproduce every one of the 48 boxes in `individual/` exactly, once
two constants are added for the features that stand proud of the sketch box:

| | | over 48 boxes |
|---|---|---|
| measured width | `#BoxWidth + 2.600` | constant |
| measured depth | `#BoxDepth + 6.100` | constant |

Neither offset is symmetric. On `Box Compile 105S` the width runs
`-113.750 .. +113.150` about a box of `±112.150` — `1.600` proud on one side and
`1.000` on the other — and the depth `-23.400 .. +26.300` about `±21.800`, so
`1.600` and `4.500`. Those are the label holders, the closing bumps and the rear
storage; which feature owns which number is still to be measured.

**`#BoxDepth` and `calLidDepth` are the same expression.** `calLidDepth` adds
`8.5` where this adds `6.0`, and then `WallThickness + PusherThickness + 1.0`:

```
calLidDepth - #BoxDepth = 8.5 + 1.6 + 3.0 + 1.0 - 6.0 = 8.100   (exactly, all 48)
```

So the `2.00 mm` in CLAUDE.md's "the box is lid − 2.00 mm on both axes" is the
*measured envelope* — `8.100 - 6.100` — not the sketch, and the two are not
independent formulas that happen to agree.

## Shorter cards — a HEIGHT CLASS, and three things a height follows

`105.00` is the studio's box for a `CardHeight 92` card (an 88–89 mm card in
its envelope), with a 40 lid and a 22.2 label. cad/ adds games of SHORTER cards
(2026-09-21: `MiniCards`, 41 x 63 mm, placeholder name and thicknesses) as a
GAME property, not a release, and gives them a **height class**: one box for
every game in it, so a class is one look, as 105 is today.

- **The card is the game's** (`tables.CARD_HEIGHT`): its height plus `3.000`
  of envelope, as 92 is for an 88–89 card. `MiniCards` is `66`. Everything
  the studio derives from `CardHeight` follows unaided — holders, pocket,
  `calPocketHeight` — and the holder's `OUTLINE_TOP_TERM` 76.500 is
  `CardHeight - 15.500` (`holder.OUTLINE_TOP_TRIM`).
- **The box and label are the class's** (`tables.HEIGHT_CLASS`,
  `CLASS_BOX_HEIGHT`, `CLASS_LABEL_HEIGHT`). `"mini"` is **86 / 12**, for
  63–68 mm cards (mini American to mini Euro, sleeved): 13.000 over the
  tallest's CardHeight (73), as 105 is over 92. A shorter card in it is just
  more air under the closed lid (`cad.fit`: "socket underside over the card
  top" 11.200 for a 63 card, against the studio's 4.200).
- **A class box leads its codes with its height** (Allan, 2026-09-22):
  `86-L6.10.10.32.Un`, holder `86-L.10.Un`, and the files follow
  (`Box 86-L6.10.10.32-Un.3mf`). The size letter still says how many ACROSS;
  the prefix says how TALL, and a studio box's codes are unchanged. Chosen
  over a lower-case width letter, which Orbitron engraves as a shorter
  capital (`s`/`S`, `x`/`X`) and which a case-insensitive file system cannot
  tell from the studio's. Pushers keep `Pusher 6x10-Un`: a game is in one
  class, so the name cannot collide in its folder.
- **The rise is the box's, not the label's**: `(BoxHeight - 18) / risers`.
  86 gives 11.333 on 6 risers (79 gave 10.167).

### The label sits between two lid rims

The 105 box's own margins, held on every box:

| | 105 box | holds because |
|---|---|---|
| play: holder bottom over the rim of the lid the box STANDS IN | `2.100` | `LABEL_Z0 = LidHeight + 0.5` |
| closed: lid rim over the holder's fasteners | `1.100` | `LABEL_Z1 + 1.0 = BoxHeight − LidHeight + 0.5` |
| closed: lowered front over the lid rim | `2.000` | `FRONT_TOP = BoxHeight − LidHeight + 3.6` |

A holder is its label plus `2.800` (22.2 → 24.0 of pad and 1.0 of fastener),
so **`LidHeight = (BoxHeight − label − 2.8) / 2`** and **`FRONT_TOP =
(BoxHeight + label + 2.8) / 2 + 3.6`**: 105 / 22.2 gives 40 and 68.600
exactly. A shorter label buys a taller lid and a lower front, half a mm per mm,
and NO rise. The mini class: lid **35.6**, front **54.000**, holders
`36.100..49.900`.

Tried and found wrong on the way (2026-09-21): taking the whole box drop off
the labels put the holders 750 mm³ into the lid in play (`cad.fit --state
play` found it); keeping the front wall with the rim opened an 11 mm slot
under the closed lid (a render found it).

### Three drops, 0.000 for every studio game (`derive`)

The Box's MEASURED Z datums stay the 105 box's constants, so the tests that
read them are unchanged, and each follows one thing:

- `rim_drop` = `BoxHeight − 105`, the RIM: the bump (and the lid's
  `BUMP_TOP`, so the groove stays `16.600` up the lid), `RIM_CUTOUT_Z`,
  `REAR_TOP` and the back's lattice (`hole_rows`).
- `card_drop` = `CardHeight − 92`, the CARDS: `POCKET_CUT_TOP` and the front
  thumb, the pre-7.2f `LIP_Z`, and the front panel's slits
  (`hole_rows(d, card_drop)`), which on a class box would otherwise run into
  the thumb.
- `lid_drop` / `closed_rim_drop`, the two LID RIMS: the label band
  (`box.label_band`) and `box.front_top`.

`PUSHER_REST_CAP` and `HOLE_ROW_BOTTOM` are measured off the FLOOR and stay
put. Every new height is written as the studio's constant plus a difference, so
floating point cannot move a studio byte.

### The front pocket's floor comes up

A short card in a class box stands low behind a front wall the LID sets:
86 / 12 puts the wall at 54.000, over a 63 card standing on the floor at
2.000. So the pocket's floor comes up (`box.pocket_floor`) until
`POCKET_SHOW` (0.25) of the card clears the wall. That's about what an 88–91
card shows over the studio's 68.600 (21–24). **A class box only**: at 7.0's
1.600 floor the rule raised a studio unsleeved box 0.250, and the 7.0
rebuild caught it. `MiniCards`: floor 6.750 unsleeved, 4.500 sleeved. `cad.fit`: "front
pocket: card over the front wall", 25%. The pocket's floor is solid
(`bottom_slot` starts behind the panel), so the raise is a slab on it.

- Nothing here reaches an existing part: `cad.build --part all --force` and
  `--version 7.0 --force` reported every studio game's part byte-identical.

## The reference STEPs

Hand-exported from the Onshape UI, 0 API calls, in `spec/reference/`.

| file | cascade | envelope | faces | what it splits |
|---|---|---|---|---|
| `Box Compile 105S.step` | Compile 105 Card Sl `S4.7.7.32-Sl` | `226.900 × 49.700` | 1672 | S: 3 slots, 2 pusher slots. Same cascade as the Pusher STEP, so the rim cutouts can be checked against that pusher's tabs |
| `Box Dominion 244S.step` | Dominion 244 Card Sl `M4.21.10.45-Sl` | `276.900 × 58.300` | 1832 | M: 4 slots, 3 pusher slots |
| `Box Dominion 202S Merged.step` | Dominion 202 Card (Mat) Sl, same model code | `276.900 × 58.300` | 1879 | the SAME box with `MatPocket = 1`. Volume `147581.786` against `148340.743` — the merge removes `758.957 mm³` and adds 47 faces |
| `Box Dominion 650S.step` | Dominion 650 Card Sl `L8.50.10.62-Sl` | `341.900 × 109.300` | 2146 | L: 5 slots, deepest box in the catalogue |
| `Box FCM 72S.step` | **not in parts.csv** — see below | `211.900 × 33.700` | 1586 | the smallest box |
| `Box Dominion 246S.step` | Dominion 246 Card Sl `S2.40.12/30.45-Sl` | `211.900 × 66.100` | 1818 | the ONLY reference with a first-riser override — `calFirstSliderDistance 20.400` against `calSliderDistance 9.600` |
| `Box Dominion 246S without final fillet.step` | the same box, `Smooth box edges` suppressed | identical | 1774 | **the build target** — see below |
| `Box Dominion 244U.step` | Dominion 244 Card Un `M4.21.10.32-Un` | `268.900 × 44.880` | 1828 | UNSLEEVED, and 244S's pair-mate, so the diff between them isolates sleeving alone. Every earlier reference was sleeved and half the catalogue had nothing behind it |
| `Box Dominion 244U without final fillet.step` | the same box, fillet suppressed | identical | 1763 | one of the two twins that settled `Lower the front` — see below |
| `Box Innovation 130U.step` | Innovation 130 Card Un `XS5.15.10.32-Un` | `150.900 × 50.100` | 1625 | Innovation, XS and unsleeved at once: the only game with no reference, the only size, and the exception that takes 2 pusher slots where its size would otherwise take 3. It caught the front label holder |
| `Box Innovation 130U without final fillet.step` | the same box, fillet suppressed | identical | 1555 | the second twin |
| `Box Dominion 333S.step` | Dominion 333 Card Sl `S9.21.10.62-Sl` | `211.900 × 100.300` | 1944 | nine risers: the `RisingSliders > 8` logo margin, the lowest rise in the catalogue, and the pusher rest at its floor |

**`Box FCM 72S` is a row parts.csv does not have.** Its envelope solves uniquely
to FCM, sleeved, `HorizontalSlots 3, RisingSliders 3, FrontPocketCardCapacity 6,
CardsPerSlidingSlot 6` — `calModelName` `S3.6.6.20.Sl`, `calCapacityLabel`
`72 Cards/S`, which is where the filename's "72S" comes from. The formulas hit
`211.900 × 33.700` on the nose. Treated as a reference, not as a catalogue row,
until parts.csv says otherwise.

~~No unsleeved and no Innovation box among the five, and neither is needed:
sleeving moves `calCardwidth` and `calCardThickness` only, which reach the box
through `calSlotwidth` and `calSliderDistance` and add no topology; and
Innovation's `isOnlyTwoPusherSlots` M box is topologically the Compile/FCM S
case, which two of the five cover.~~ **Half right, and the wrong half was
expensive.** Unsleeved really does add no topology — `Box Dominion 244U` and
`Box Dominion 333S` both passed every check unchanged the moment they landed.
But the reasoning did not cover XS, and `Box Innovation 130U` found a real
defect on its first run: a box `150.900` wide carrying a `160.000` front label
holder. See "The label holders" below.

## The feature tree, transcribed

In studio order. Sketches are italic in Onshape's tree and marked *(sk)* here;
`(n)` is the feature count Onshape shows for a folder.

```
Create box shape (6)
    #BoxWidth, #BoxDepth
    Top of box (sk) / Extrude solid box / Hollow out box
    Center of box                       (mate connector)
Model name (2)
    Model name (sk) / Model Name        (extrude — text)
Hole in bottom of box (2)
    Bottom slots for pushers (sk) / Remove material for bottom slots
Pusher holder & Rear Storage (19)
    #dBackSlotWidth, #calPusherSlots
    Add depth to back
    Top hole for pusher storage (sk) / Remove material, don't let pushers dr...
    Cut out top of back (sk) / Top of back
    Cover slot (sk) / Divider / Repeat Divider
    Hanging holes (sk) / Extrude 3 / Repeat Hanging Holes
    Make rightmost pocket deeper
    #calFingerHoleOffset
    Thumb Cutout in back (sk) / Remove thumb hole in back / Fillet rear thumb hole
    Pusher Storage                      (mate connector)
Lower the front (2)
    Sketch 1 / Extrude 2
Round top box corners
Sliders (10)
    Slider (sk) / Slider tilt (sk) / Extrude slider / Round top of. slider
    Mirror slider / Replicate sliders
    First Slider (sk) / First Slider / Fillet 1 / Mirror First Slider
Front pocket (13)
    Front divider (sk) / Extrude front divider
    Divider for front pocket (sk) / Divider for front pocket / Additional dividers
    Pad outermost slots (2): Padding on the side of outer slots (sk) / Outermost padding
    #HoleAreaHeight
    Slits in front pocket (sk) / Make holes / Holes in remaining slots
    Angled cutout of front holder (2)
Thumb and Lip (8)
    Import Holder patterns              (derived)
    Thumb (sk) / Remove thumb hole / Fillet thumb hole
    Lip (sk) / Lip (extrude) / Lip (fillet) / Repeat thumb and lips
TokenHolder (0)                         (empty folder)
Logo (5)
    Logo (sk) / #LogoHeight / Capacity (sk) / Rev (sk) / Logo text (extrude)
Closing mechanism (4)
    Side bump (sk) / Extrude 1 / Chamfer 1 / Mirror 1
Tittles (4)                             SUPPRESSED
Front Label Holder (10)
    Name tag left (sk) / Fastener (sk) / Tag holder left / Chamfer 2
    Fastener / Round Fastener / Mirror 2 / Cutout (sk) / Sweep 1
    CentreBottom of Label               (mate connector)
Side Label Holder (6)
    Side Label Holder (sk) / Extrude 7 / Chamfer 3 / Mirror 3
    Side Cutout (sk) / Sweep 2
#SharpEdges                             (query)
Smooth box edges                        (fillet)
```

Every feature in `Front Label Holder` and `Side Label Holder` carries Onshape's
`fx` marker, which the other groups do not — almost certainly conditional
suppression on `isLabelHoldersOnBox`. **Untestable from the catalogue**: that
variable is `0` only for Colours or `HorizontalSlots <= 1`, and no parts.csv row
is either, so every box on disk has both holders. Built always-on unless Allan
says otherwise.

## Variables the tree names that the studio transcription does not

| variable | seen as | reading |
|---|---|---|
| `#dBackSlotWidth` | `37.6 mm` on `M4.21.10.45-Sl` | **`= calPusherTotalDepth + 4.000`, confirmed** — the stored pusher's own depth plus 2.00 of clearance a side. It is the PITCH between rear storage slots; see below |
| `#calPusherSlots` | `3` on the same box | Onshape's rule is 2 for S and for all Innovation, 3 for M and L — counted independently off all 48 boxes' rim cutouts (`2 × slots + 1` section loops) and it agrees everywhere. **From 7.1 it is 2 at every size**; see "Two pusher slots, at every size" below |
| `#calFingerHoleOffset` | `162.5 mm` on the same box | **`= (calPusherSlots - 1 + (HorizontalSlots - calPusherSlots)/2) * calSlotwidth`** (Allan). Step right one slot width per pusher slot after the first, then centre the remainder. `cad/parts/box.py` |
| `#HoleAreaHeight` | `68.5 mm` | front-pocket slit height |
| `#LogoHeight` | `2.74 mm` | the Logo text's cap height, as `#LogoTextHeight` is the Pusher's |
| `#SharpEdges` | query | the edge set `Smooth box edges` fillets |

## Two pusher slots, at every size — a 7.1 RELEASE CHANGE

**Every cascade takes TWO pushers from 7.1** (Allan, 2026-09-06), where
Onshape's rule gave 3 to every M and L box that is not Innovation. It is a
release change and not a divergence: a 7.0 build still cuts three and still
reproduces all 48 cached boxes (`cad/revisions.py`, flag `two_pushers`;
`spec/REVISIONS.md`).

It restates **24 of the 50** boxes — 16 Dominion, 6 FCM, 2 Compile; Innovation
and every S box were on two already — and on each of them:

* one fewer rear storage slot, its `Divider`, and its pair of rim cutouts;
* the empty run right of the last divider grows by one pitch, which the
  geometry already handles: `rear_storage` cuts that run empty from the floor
  up, so nothing is left standing as a slab;
* the `Thumb Cutout in back` MOVES, because `#calFingerHoleOffset` is written
  in terms of `#calPusherSlots`. At two slots the expression centres the
  remainder, and where it lands is worth stating exactly, because it is not
  obvious from the formula: **`4.750` left of the pocket's own centre, on all
  50 boxes at both releases**. That falls out of an invariant of the
  catalogue — `#BoxWidth = #HorizontalSlots * #calSlotwidth + 14.300` on every
  row — and it is what 7.1b's spread replaces;
* the project ships one Pusher fewer, and the Lid one socket fewer — the Lid
  follows on its own, since `lid.socket_count` is `box.pusher_slot_count`
  from 7.1 (`spec/LID.md`).

### The thumb still lands where it should, and that had to be checked

`#calFingerHoleOffset` shrinks by half a slot width when the count drops to 2,
so the thumb moves left on all 24. Three things had to stay true and all three
do, at BOTH releases and on all 50 boxes:

* it is clear of every `Divider` — the wall a pusher hangs on, and the only
  thing the cut can damage, since it runs from the slot band BACKWARDS through
  the outer wall and an empty slot cavity is void already;
* it is inside the empty run right of the last divider, which is what
  `rear_storage` cuts away from the floor up;
* it is inside the end walls.

`tests/test_revisions.py` asserts all three at 7.0 and 7.1, through the part's
own `rear_thumb_x` and `storage_dividers`.

**Read `rear_thumb_x`, do not re-derive it.** The offset is measured from the
left edge of the SECOND storage cavity — `+ #dBackSlotWidth + 1.600` — not
from the left inner wall, and a hand-derivation that misses that puts the
thumb a whole pitch to the left and invents collisions that are not there.
That is exactly what happened while this change was being planned, twice.

## `components.pushers_for` disagreed with the CAD on Innovation XS — fixed

Counting rim cutouts on all 48 boxes matched `components.pushers_for` everywhere
except `XS5.15.10-Un/Sl`: Innovation's map was `{"S": 2, "M": 2, "L": 3}`, `XS`
was not a key, so it fell through to the default `3` — but the box has **2**
slots, and both built Single Mini projects carry 2 pushers.

**It was latent, not live.** `ctx["pushers"]` reaches only a planner total and
`count` in `manifest.json`, which `make_cascade --count` consumes on a FIRST
build. `refresh_cascades` never sees it: `build_swap` pairs template objects to
files by NAME, and `assemble_one` emits `--part` args only, under
`--keep-layout`. On a first build from an Innovation donor (2 pushers) it would
have failed loudly — `make_cascade` refuses `--count` above the instances it
has; from a 3-pusher donor it would have quietly printed a spare.

Fixed by giving Innovation a flat `"pushers": 2`, which is the shape
`isOnlyTwoPusherSlots` actually has — closing the `XS` hole and the unreachable
`L` entry together. `plan_exports` also learned that `XS` is a two-letter size
(`size = base[0]` made it `"X"`); that renames nothing today, because Innovation's
holders span and `Single Mini` carries no toppers, but `"X"` was a trap for any
future XS file.

**`verify.py --boxes` is the guard.** It counts each box's rim cutouts and
compares with the table — 48 boxes checked, 0 disagree now, and exactly the two
XS boxes flagged when the old map is restored. The table and the CAD are two
copies of one fact; this is what keeps them together.

## The rear pusher storage, and the lock it carries

Read off the rim cutouts of all five STEPs, which span 2 and 3 slots and the
C2, C3 and C5 lock classes. `tests/test_box.py` holds the rule to them.

```
#dBackSlotWidth = calPusherTotalDepth + 4.000          the pitch
slot k centreline = -#BoxWidth/2 + WallThickness + (k + 0.5) * #dBackSlotWidth
```

The slots pack from the **left inner wall**, each centred in its own cell, so
the first sits half a pitch in. Every one of the 14 slot centrelines across the
five references lands on it exactly.

Each slot's two rim cutouts sit at that centreline `± s`, `4.500` wide — the
7.0 catalogue, already in `cad/lock.py` as `BOX_CUTOUT_W`. Measured `4.500` on
all 28 cutouts, and the pairs `2s` apart to `0.00`: `17.00` on the two C3 boxes,
`48.00` on the C5, `10.20` on the C2.

**Probe the back wall, not a plain section.** The end walls and the label
holders run the full depth, so at the cutouts' height a plain `z` section reads
their edges as rim pieces: that is what made the leftmost FCM cutout measure
`4.15` instead of `4.500`. `tests/test_box.py` intersects a thin bar through the
back wall instead.

## The back, in section

Constant on all five references, as offsets from `#BoxDepth/2`:

| from | to | | |
|---|---|---|---|
| `-1.600` | `-0.300` | `1.300` | the back wall — a `1.600` wall with `0.300` eaten by the slot |
| `-0.300` | `+2.900` | **`3.200`** | the pusher slot — `LOCK_STANDARD.md`'s box slot depth, exactly |
| `+2.900` | `+4.500` | `1.600` | the outer back wall |

So **`Add depth to back` adds exactly `4.500` behind the sketch box**, and that
is one half of the `6.100` depth offset. The other `1.600` is at the front, and
the `Front Label Holder` sweep is what stands there — on `Box Compile 105S` it
is a face at `y = -23.400`, `160.000` wide, `z 40.500..64.500`.

The back wall is a **lattice**, not a panel: openings `10.000` wide at a
`13.600` pitch horizontally and `20.833` tall at a `22.833` pitch vertically,
with `2.000` bands between the rows and `3.600` piers between the columns. Three
rows on `Box Compile 105S` (`z 3.000..23.833`, `25.833..46.667`,
`48.667..69.500`), then solid from `69.500` to the rim. The front pocket's back
wall carries the same pattern in a `1.000` panel at `y = -14.600..-13.600`.

## The text is engraved in the FLOOR

Not on a wall. `Model Name` and the `Logo` group cut `0.400` deep into the top
of the floor — the same `ENGRAVE` depth the Pusher uses — and they sit at the
two ends, outboard of the card slots. The glyph faces are `ENGRAVE` below the
floor's top face wherever that is: `z = 1.200` against `1.600` at 7.0,
`1.600` against `2.000` from 7.1. The whole block is carried up by the change
below, not re-fitted to it — same lines, same sizes, same ink.

## The floor is 2.000, and it grows UPWARD — a 7.1 RELEASE CHANGE

**The floor is `2.000` from 7.1** (Allan, 2026-09-08), where every wall stays
`WallThickness`'s `1.600`. It is a release change and not a divergence: a 7.0
build still lays a `1.600` floor and still reproduces all 48 cached boxes and
its nine reference STEPs (`cad/revisions.py`, flag `thick_floor`;
`spec/REVISIONS.md`).

**What actually thickens is the two side floors.** `Hole in bottom of box` cuts
the card area clean through, so the box has no floor across most of its
footprint; what it has is the pair of strips the holders rest on when the
cascade is shut, plus the front pocket's floor and the rear storage's. Those
strips are also what carries the engraving. That is the reason for the change,
and it is why the number to state is the floor's and not the wall's.

**UPWARD is the whole of why it is cheap.** `box.shell` fuses the extra
`0.400` on top of the hollowed tray, so the box's outside is untouched — same
bounding box to the last decimal, same rim at `BoxHeight`, same rim cutouts at
`z 100.000..105.000`, same `Top of back` at `85.000`, same hanging holes from
`3.000`, same `pusher_rest`. Every one of those is measured from the BED, and
none of them moves. The `0.400` comes out of the CAVITY instead, and the cavity
can afford it: the closed lid's inner face lands flat on the rim, so the budget
is the holder's headroom, and that is `12.900 mm` on all 50 rows before the
change and `12.500` after.

Three things follow the floor, and each is a place where reading `WALL` instead
of `box.floor_top` would be a bug:

* **`bottom_slot`** is a THROUGH cut. Stopping it at `1.600` would leave a
  `0.400` membrane across the card area — which no test of volume alone would
  notice, so `tests/test_revisions.py` probes the card area for it directly.
* **`rear_storage`**'s empty run right of the last divider is cut "from the
  floor up", and its floor is the box's.
* **the engraving**, above.

And two things stand ON it, so they rise by exactly `0.400`: every holder
(`assembly.holder_closed`) and the token holder (`assembly.token_holder`). Both
take their Z from `box.floor_top` and not from `WallThickness` — the two are
the same number until 7.1 and different after it, and the `WallThickness` still
in `assembly.lid_closed` and `assembly.lid_under` is the LID's own floor, which
stays `1.600`.

The Lid keeps its `1.600` floor. It is the other part built on `geom.tray`, and
`shell` adds the box's extra slab rather than passing a floor down to the
helper precisely so that the Lid is not touched by this.

## A thumb cutout every 70 mm of back pocket — a 7.1 RELEASE CHANGE

**From 7.1b the back pocket gets as many `Thumb Cutout in back`s as it takes to
put one every `70.000` along it** (Allan, 2026-09-08), where every release
before it gets exactly one however wide the pocket is. A release change and not
a divergence: a 7.0 build still cuts the single Onshape cutout at the Onshape
position and still rebuilds all 50 boxes to the byte (`cad/revisions.py`, flag
`rear_thumbs_spread`; `spec/REVISIONS.md`).

### Why

The pocket is the empty run right of the divider that closes the pusher slots,
cut away from the floor up. It is **45.3 to 290.5 mm wide** across the
catalogue, 45 of the 50 over 100 mm and four over 280 — and 7.1's
`two_pushers` widened 24 of them by a whole `#dBackSlotWidth`. One cutout in
the middle of 290 mm is not reachable from either end of what it serves.

### The rule

```
pocket            box.rear_pocket(d)      the empty run, divider face to end wall
usable            [x0 + r + CLEAR, x1 - r - CLEAR]     r = ThumbCutoutRadius
n gaps            ceil(usable / REAR_THUMB_PITCH)      PITCH = 70.000
cutouts           n + 1, evenly spread over `usable`   CLEAR = 10.000
```

`ceil` is what makes `REAR_THUMB_PITCH` a **ceiling and not a target**: the gap
actually cut is the largest one no wider than `70.000`, which puts it in
`(35, 70]` by construction and, on the catalogue, at `34.90 .. 69.15`. Counts
come out `{1: 3, 2: 3, 3: 24, 4: 16, 5: 4}`.

A **second cutout has to earn its place**: below `2 * r + CLEAR` of usable span
the two would leave less wall between them than either leaves at its own end,
so such a pocket keeps one, centred. Three cascades are in that case, and the
narrowest of them (`S9.21.10.62-Sl`, `45.30`) is narrower than one cutout plus
its clearances — it eats its margin rather than going without the cutout the
box has always had.

**`#calFingerHoleOffset` stops being consulted** from 7.1b: the pocket places
the row, so it is centred on the pocket rather than `4.750` left of its centre.
`box.rear_thumb_x` stays exactly as it is — it is what 7.0 and 7.1a cut, and
the reference STEPs are held to it.

Nothing else on the back is in the way, which is why the change is cheap. The
cutout is `r = 12.000` centred on `REAR_TOP`, so it opens the band
`z 73.000..85.000` of the **outer back wall only**; the hanging-hole lattice
tops out at `69.500`, the rim cutouts are in the `1.300` INNER wall above
`100.000`, the engraving is in the floor and the closing bumps are on the end
walls at the front. `tests/test_revisions.py` asserts that every cutout at
every release is clear of the dividers, inside the pocket and inside the end
walls, and prices the flag on the widest box: `4` more cutouts, `1456.7 mm³`
net, `4.025` half-cylinders of `1.600` wall.

### It cost the outer ledge its fillet listing, and no geometry

`sharp_edges` listed the `z = 85.000` ledge on BOTH faces of the outer back
wall. Several cutouts break the OUTER face's ledge into three segments or more,
one of them bounded by a cutout at each end, and **OCCT refuses that chain** —
each segment alone is accepted, any two ACROSS a cutout are not, and the box
dies in `smooth_edges` rather than losing a round. The INNER face's ledge takes
five segments without complaint.

Listing the outer face was always redundant: given the inner one, OCCT rounds
the outer edge too. So it is listed only while the pocket has ONE cutout, and
the ledge still comes out rounded `0.600` into both faces — probed between two
cutouts in `tests/test_revisions.py`, identical to the 7.0 wall to the micron.

**Why the switch is on the cutout count and not simply dropped.** On all 50
boxes at 7.0 the two edge sets fillet to volumes within `3e-5 mm³` of each
other, 44 of them within `1e-10`. That is noise in a volume — a hundred-
thousandth of the fillet it would be missing — but on six boxes it moves enough
bytes in the written mesh to break the byte-for-byte 7.0 rebuild, and a
release that has shipped must keep rebuilding to the byte.

## A stouter lattice — a 7.1 RELEASE CHANGE

**From 7.1c a lattice window is `9.000` wide and there are FOUR rows of them**
(Allan, 2026-09-09), where every release before it has `10.000` and three. A
release change and not a divergence: a 7.0 build still cuts Onshape's five
`10.000` windows in three rows and still rebuilds all 50 boxes to the byte
(`cad/revisions.py`, flag `stout_lattice`; `spec/REVISIONS.md`). The Holder
takes the same change at the same release — `spec/HOLDER.md`, "A stouter
lattice" — and so do the front pocket's slits, which are the same openings.

### What moves, and what deliberately does not

The PITCH does not move and neither does the row band. So:

    window   10.000 -> 9.000        only a window's +X edge moves
    pier     pitch - 10.000         -> pitch - 9.000, a flat +1.000 everywhere
    rows     3 -> 4, dividing HOLE_ROW_BOTTOM..HOLE_ROW_TOP as before
    pier run 20.833 -> 15.125       between one bridge and the next

`(calSlotwidth - 2.000)/5` is untouched, `HOLE_INSET` is untouched, and
`HOLE_ROW_BOTTOM`, `HOLE_ROW_TOP` and `HOLE_ROW_GAP` are untouched. Read
`box.hole_w(d)` and `box.hole_rows(d)` rather than the constants: both are
release-dependent from 7.1c and neither takes its old value for granted.

| `calSlotwidth` | pier at 7.1b | pier at 7.1c |
|---|---|---|
| 63.0 (FCM) | `2.200` | `3.200` |
| 65.0 (Dominion) | `2.600` | `3.600` |
| 67.0 (Innovation Un) | `3.000` | `4.000` |
| 68.0 (Compile Un) | `3.200` | `4.200` |
| 69.0 (Innovation Sl) | `3.400` | `4.400` |
| 70.0 (Compile Sl) | `3.600` | `4.600` |

### Why

The piers break, in print and in the hand. The box's are `1.300` thick — the
back wall is `WallThickness` less `SLOT_BITE`, not `1.600` — and `2.200` wide
at the narrowest slot width, standing `20.833` between bridges. In the back
pocket, where `rear_storage` empties the whole slot band, the pier is not even
one column: it is a `1.300` and a `1.600` with `3.200` of air between them.

The change is a width and a row count and **not a shape**, and that is the
whole of the design constraint. Filleting the window corners is the obvious
move and it was tried first, on test prints: it is WORSE. A fillet at a
window's TOP corner turns a clean short bridge into a progressively worsening
overhang, and the window's sides stop running vertical, so every layer steps.
Coupons with pointed BOTTOMS — the self-supporting direction — printed clean;
every rounded or pointed TOP printed rough. **Sides vertical, top horizontal**
is the rule that survived, and a narrower window with more rows obeys it.

Narrowing also shortens every bridge by 10%, which is a small bonus rather
than a risk; adding a row adds a third more bridges, which is the counterweight
and is much the smaller term, a pier's stiffness going as the cube of its free
run.

### What has to be re-run

`hole_openings` nudges a hole edge by `HOLE_CLEAR` wherever it lands EXACTLY on
a storage divider's face, which is what clears the line contact on the three
sleeved Innovation boxes. This change moves every window's `+X` edge, so which
edges coincide is not the same question it was: `tests/test_build_meshes.py` is
the check and it has to pass at 7.1c as well as at 7.0.

## `Smooth box edges` is a `0.600` fillet, and there is a ground truth for it

Allan exported `Box Dominion 246S` twice, once with the final fillet suppressed.
Diffing the pair settles the one step that could not be reverse-engineered from
a finished solid, because an Onshape edge QUERY has no counterpart in build123d:

| | |
|---|---|
| volume removed | `129.190 mm³` — **0.094 %** of the box |
| faces added | 44 (1774 → 1818) |
| radius | **`0.600`**, from three independent offsets: `105.000-104.400`, `33.500-32.900`, `103.650-103.050` |
| where | 13 sliver chains: the top rim, the `z = 85.000` ledge, and vertical edges on the end walls |

So the build target is the **unfilleted** STEP, and the filleted one validates the
last step on its own. That removes what was the plan's biggest fidelity risk: the
diff against the target is no longer polluted by a fillet, and the fillet is
checked as a `0.600` radius over a named edge set rather than chased as a query.

## `MatPocket` is confined to the front pocket

Allan: it changes the front pocket and the TokenHolder entity, and nothing else.
Consistent with the measurement — `Box Dominion 202S Merged` differs from
`Box Dominion 244S` by `758.957 mm³` and 47 faces, all inside the front pocket.
So the Box's Mat branch is one feature group deep, and `plan_exports`' note that
the merge "resizes the box" is about the pocket, not the envelope: the two share
an envelope to `0.000`.

## `Hole in bottom of box` — one rectangle, and two SIDE FLOORS

Despite the plural in the feature name, the floor carries a single rectangular
through-cut. Measured by subtracting each STEP from the floor slab: on all six
references the removed lump's volume equals its own bounding box **to the last
decimal**, so there is no chamfer, draft or second pocket inside it.

**State it by what is LEFT, not by what goes.** A strip of floor
`calSlotwidth / 2` wide survives at each end — the **side floor** — and it is
there for a reason: the holders rest on it when the box is not in use (Allan).
The cut is everything between the two.

```
side floor = calSlotwidth / 2                             at each end
width      = #BoxWidth - 2*WallThickness - 2*side_floor
           = 11.1 + calSlotwidth * (HorizontalSlots - 1)   centred on X = 0
depth      = from -#BoxDepth/2 + WallThickness + calFrontPocketDepth + 1.000
             to   +#BoxDepth/2 - WallThickness
```

In depth it runs from the back of the front pocket's divider to the inner face
of the back wall, i.e. exactly the sliding card area. It is NOT aligned with the
rear pusher slots, which sit at their own pitch.

| box | width | depth | volume |
|---|---|---|---|
| Compile 105 Sl | `151.100` | `33.800` | `8171.488` |
| Dominion 244 / 202 Sl | `206.100` | `35.400` | `11673.504` |
| Dominion 650 Sl | `271.100` | `69.000` | `29929.440` |
| Dominion 246 Sl | `141.100` | `31.800` | `7179.168` |
| FCM 72 Sl | `141.100` | `19.800` | `4470.048` |

The `1.000` is the front pocket's back wall, measured as a panel at
`y = -#BoxDepth/2 + WallThickness + calFrontPocketDepth` and `1.000` thick. It
lives in `box.FRONT_DIVIDER` until the Front pocket group is written and can own
it.

## `Pusher holder & Rear Storage`, measured

Constant on every reference unless stated. Offsets from `#BoxDepth/2`:

| feature | value | |
|---|---|---|
| `Add depth to back` | `+4.500` | one half of the 6.100 depth offset |
| back wall | `-1.600 .. -0.300`, so `1.300` | a `1.600` wall with `0.300` eaten by the slot |
| pusher slot | `-0.300 .. +2.900`, so **`3.200`** | `LOCK_STANDARD.md`'s box slot depth exactly |
| outer back wall | `+2.900 .. +4.500`, `1.600` | |
| `Top of back` | the storage is capped at `z = 85.000` | only the END WALLS carry on to `BoxHeight` |
| `Remove material, don't let pushers drop through` | the cavity floor — see below | a stored pusher rests there, not on the box floor |
| `Divider` / `Repeat Divider` | `1.600` wide, `z` up to `85.000` | **`n` dividers for `n` slots** — at every boundary except the left inner wall, the last one CLOSING the run on the right |

### The hanging holes do NOT cut the dividers — a deliberate divergence

**And a second, smaller one that follows from it (Allan, 2026-09-04): a hole
whose edge lands EXACTLY on a divider's face stops `HOLE_CLEAR = 0.200`
short of it.** With the holes cut through the dividers, as Onshape does, the
coincidence is invisible; with the dividers left solid, wall material below
the slot band and divider material above it touched along that one line,
corner to corner — six edges with four triangles each in the written mesh,
on the three boxes where the pitch lands there: `M5.10.10.45-Sl`,
`S5.10.10.45-Sl`, `XS5.15.10.45-Sl`, all sleeved Innovation. They sliced
regardless, but it was the last non-manifold thing in the catalogue.
`box.hanging_holes` remains the sketch; `box.hole_openings` is what is cut,
and `tests/test_box.py` asserts that the two differ on exactly those three
boxes and on no reference.

Onshape cuts each hanging hole as one prism from the card side through to the
outer wall, so it takes the storage dividers with it. Measured, that is not a
near miss:

| | dividers pierced | width lost |
|---|---|---|
| `Box Dominion 244S` | 3 of 3, all **full width** | `4.800` |
| `Box Compile 105S` | 2 of 2 | `2.300` |
| `Box Dominion 246S` | 2 of 2 | `2.300` |
| `Box FCM 72S` | 1 of 2 | `1.600` |
| `Box Dominion 650S` | 1 of 3 | `1.600` |

A fully-pierced divider is severed at every hole row — three cuts through the
`1.600` wall that holds a stored pusher. The holes themselves are wanted; that
is not.

**So `cad/` stops them at the slot band.** The back wall keeps the complete
lattice, and so does the fill below the pusher rest; the dividers stay solid
from the floor to `Top of back`. `box.storage_dividers` names the ranges and
`box._interval_minus` takes them out of each hole. On `Box Dominion 244S` it adds
`960 mm³` — `0.6 %`.

This is the **first place `cad/` is knowingly not the reference**, so it is
asserted in both directions: `tests/test_box.py` checks every divider is whole
on the build AND that the STEP pierces at least one, which is what would catch
a future change quietly re-converging on Onshape. `tests/box_diff.py` will show
it as EXTRA, and it is expected there.

### The pusher rest is a formula, and it is NOT `3.000`

```
rest = min(25.000, BoxHeight - calPusherTotalHeight - 0.500)
```

A pusher is stored **on edge and upright**. `#dBackSlotWidth` is its own
`calPusherTotalDepth` plus clearance measured along the box's WIDTH — that is
what makes the slot pitch what it is — so the pusher's *staircase height* stands
vertically. The rest is then placed to bring the top of that staircase to
`0.500` below the rim, where its tabs meet the box rim cutouts, until the
`25.000` cap takes over for a short pusher.

Read off **all 48 cached Boxes in `individual/`** by ray-probing the meshes
(0 API calls, `verify._meshes` does the loading). Three distinct values, two of
them below the cap, so the formula is pinned and not just fitted:

| `calPusherTotalHeight` | rest | boxes |
|---|---|---|
| `60.000 .. 72.000` | `25.000` | every `R <= 4` box, and `L3.18.6` |
| `80.000` | `24.500` | `S5.40.12`, `M4.18.12`, `S4.18.12` |
| `87.000` | `17.500` | every box where `calHeightIncrement` is clamped |

`87.000` is the ceiling `calHeightIncrement = min(desired, (BoxHeight-18)/R)`
imposes, so `17.500` is the lowest rest any cascade can have.

**This file recorded `3.000` for two stages, and it was a misread.** The probe
went down a hanging hole and found solid from `0.000` to `3.000` — which is real,
but it is the material below the first hole ROW, not the rest. Below the rest
the slot band is a **lattice, not a plug**: the hanging holes cut through it
exactly as they cut the back wall, which is why a hole reads `3.000` and a pier
reads the rest. Probe the strip before the first hole (`HOLE_INSET/2` from the
left inner wall) — always inside the first cavity and never pierced. The
"shelf at `z 23.833..25.000`" this file listed as an open residual was the top
of that lattice all along.

### `Hanging holes` — the lattice through the back

Five per horizontal slot, `10.000` wide, at a pitch of `(calSlotwidth - 2.000)/5`
within a slot; the groups repeat at `calSlotwidth`, so the pier between two slots
is `2.000` wider than the piers inside one. The first hole is `8.300` from the
left inner wall — a constant. They cut through the back wall AND the dividers,
reaching from the card side to the outer wall.

Three rows, also constant (**not** a function of riser count): `z 3.000..23.833`,
`25.833..46.667`, `48.667..69.500` — `20.833` tall with `2.000` between, and the
back solid from `69.500` to the rim.

From 7.1c the window is `9.000` and there are FOUR rows in the same band —
"A stouter lattice", below. Everything else in this section holds at every
release: the pitch, the inset, the groups' repeat and the band's ends.

`tests/test_box.py` reproduces every hole position exactly on all six
references — 15 holes at `HorizontalSlots 3`, 20 at 4, 25 at 5.

**Probe the lattice through a HOLE, not the slot centreline.** On an M box the
pusher slot's centreline lands on a pier, where material runs past the rest and
a vertical profile says nothing about it. That cost a false failure.

### `Thumb Cutout in back` — and what `#calFingerHoleOffset` is measured from

Everything here is the ONE cutout every release up to 7.1a cuts. From 7.1b the
pocket places a row of them instead and `#calFingerHoleOffset` is not consulted
— "A thumb cutout every 70 mm of back pocket", above — but the hole itself, its
radius, its fillet and its over-run are unchanged, so this is still what is cut,
several times over.

A `ThumbCutoutRadius = 12.000` hole through the **outer back wall only**,
centred on `REAR_TOP` so `Top of back` takes its upper half away, filleted
`0.600` into both faces — not the front thumb's `0.400`, and the wall it cuts
is `1.600` rather than `1.000`.

```
centre X = -#BoxWidth/2 + WallThickness + #calFingerHoleOffset
           + #dBackSlotWidth + 1.600
centre Z = 85.000
```

So **`calFingerHoleOffset` is not measured from the left inner wall** but from
the left edge of the SECOND storage cavity — one slot pitch and one divider in.
Exact on all five references, whose pitches run `22.000` to `71.200`, which is
what separates that reading from a plain offset: a constant would not track the
pitch.

It lands in the empty run to the right of the last divider on every reference,
so it never meets a pusher slot, and it does not touch the `1.300` inner back
wall — that reads as one unbroken piece at this height on all five, in the STEP
and in the build.

**Watch the cutting tool's over-run.** `box.round_hole` runs past each face at
the flared radius so the cut is not coincident with it. The default `5.000`
reached back through the empty slot band and bored a `12.600` hole in the inner
back wall — about `630 mm³` the STEP does not remove. The rear thumb passes
`over=2.000`, which clears the `1.600` wall and stops inside the `3.200` band.

## `Closing mechanism` — a chamfered pad, at a CONSTANT position

```
proud    ClosingBumpDepth = 1.000
Y        -1.750 .. 6.250      8.000 long
Z        87.000 .. 90.000     3.000 tall
chamfer  0.500 on the OUTER face's four edges
```

One on each end wall (`Mirror 1`), identical on every reference.

**Its position is a constant in the box frame**, not measured from either face:
the same `Y` and `Z` on references whose `#BoxDepth` runs `27.600` to
`103.200`.

The chamfer is on the outer face only, so the pad's sides rise square for the
first `0.500` and are cut back over the last `0.500`. That is what makes the
volume `21.4167 mm³` rather than the `24.000` of a plain pad — and the diff had
already measured `21.417` before the feature was written, which is how the
chamfer was identified without a section.

`Make rightmost pocket deeper` needs nothing further: it is the cut this file
already records as "right of the pusher slots the slot band is empty from the
floor up", found empirically at stage 2 before the feature had a name.

## `Lower the front`, and the rim cutouts

The front wall stops at **`z = 68.600`** instead of `BoxHeight`, over the whole
inner width — above it only the two end walls remain, `WallThickness` each.
Measured at exactly `68.600` on all six references.

It is treated as a **constant**, and cannot be shown to be anything else: every
catalogue box has `calPocketHeight 88.5` and `calPocketDrop 8.0`
(`calMaxPocketHeight` is `CardHeight - 3.5 = 88.5` for every game but Colours),
so nothing in the derived set varies here and a formula could not be
distinguished from a number.

**The rim cutouts are `5.000` tall, not the `5.25` `LOCK_STANDARD.md` records.**
That file says "box rim cutout `4.50` wide, `5.25` deep (`z 99.75 -> 105.00`)".
On the unfilleted reference they run `z 100.000..105.000`, and a cutout's volume
is exactly `4.500 x 1.300 x 5.000 = 29.250` — the `1.300` being the back wall,
which is all they cut. The width `4.50` is right; the depth is `5.00`. Worth
reconciling with the standard.

They also close the loop on the lock: `tests/test_box.py` now measures the rim
cutouts on the BUILD as well as on the STEP, and they agree exactly on all six —
position, `4.500` width, and the back wall stopping at `100.000` inside a cutout
while reaching the rim beside it.

**Probe the cutout's z-profile at its TOP only.** Whether the profile below is
one interval or several depends on whether that cutout's centre happens to land
on a hanging hole or on a pier, which varies by box. That cost a second false
failure, after the same trap in the rear storage.

## build123d cannot subtract two boxes that share an outer envelope

Worth knowing before the next part. Once the rear storage landed, `cad`'s box and
the STEP shared their **entire** outer envelope — same walls, same `105.000`
height, same `4.500` of added depth — and OCCT's boolean then returns an EMPTY
intersection for two solids that plainly overlap:

* both shapes pass `BRepCheck_Analyzer`;
* each intersects a large box correctly;
* a fuzzy tolerance from `1e-7` to `1e-3` changes nothing;
* `ref - mine` comes back as `ref`, and `ref & mine` as zero volume.

`tests/box_diff.py` slices both shapes into slabs along X and diffs slab by slab,
which works and reconciles with the plain volume difference. A feature straddling
a slab boundary is then reported as two lumps — the cost of the workaround.

**Lump sizes there are indicative; positions are what the tool is for.** A slab
whose boolean half-fails reports the same lump in BOTH directions, inflating both
totals while leaving their difference nearly right, and the totals move by over a
thousand mm³ between `--slabs 8` and `--slabs 11`. The tool now checks
`missing - extra` against the plain volume gap, which needs no boolean at all,
and says so when they disagree. Anything that matters is confirmed by a direct
probe in `tests/test_box.py`, not by a lump size.

A related trap inside `box.py` itself: composing the negative first (empty the
slot band, then subtract the rest and the dividers back out of it) produces a
tool that cannot be subtracted with. Every cut here is a plain rectangular box,
and they are disjoint because the cavities are already separated by their
dividers.

## `Round top box corners` — a `4.600` round, front and back

Above `Lower the front` only the two **end walls** reach the rim: the front is
down at `68.600` and the rear storage is capped at `85.000`. So the "top box
corners" are the four corners of those two walls seen from the side, and each
carries a big round.

| | |
|---|---|
| radius | **`4.600`**, identical front and back on all six references |
| starts at | `z = 105.000 - 4.600 = 100.400` |
| the edges | the top-front edge at `y = -#BoxDepth/2` and the top-back edge at `y = #BoxDepth/2 + 4.500` — the outer face of the added depth, not the sketch box |

Fitted from the end wall's `y` extent at three heights, which pins the radius
three times over: an arc of radius `r` has eaten `r - sqrt(2ru - u²)` at depth
`u`, and `u = 3.01 / 2.01 / 1.01` give `4.602 / 4.599 / 4.600`.

`cad/parts/box.py` cuts it with a tool (a block minus a cylinder) rather than
`fillet()` on picked edges. Both edges are trivially described but awkward to
select stably, and a cut also keeps the tree order honest: whatever the later
groups ADD near the rim is untouched by a round that has already happened.

## `Sliders` — one rib per riser, and where they sit

**From 2026-09-12 a row may put the deep slot at the BACK** (parts.csv `Deep
slot` = `back`, `derive.isDeepSlotAtBack`, cad/ only): the first rib then sits
on the back slot's centre and the plain ones follow at `calSliderDistance`,
the pusher's `calFirstSliderDistance` drop is its LAST, and the lip's angle is
the plain holder's, since that is what it meets. `assembly.holder_rib` puts
the FirstHolder on rib 0, and there it differs from the front-mounted one
(`holder.deep_at_back`, Allan 2026-09-13 off the first print): no rear lips,
and the plain holders' slant anchored at its front edge, so its rear rises
by about 5 (`spec/HOLDER.md`, "The deep holder at the back"). `Three
Expansions` is the row: its deep slot holds an expansion's achievements and
aids, wanted once at setup, so the least stable riser is the one used least.

Vertical ribs on both end walls, which the holders ride on. The section is
constant on every reference: **`1.500` wide in Y, standing `4.000` proud of the
inner end wall**, running the full height from the floor to the rim.

**A rib's BACK FACE sits on the centre of its card slot**, and the slots are
measured from the inner back wall — `calSliderDistance` each, except the last
(frontmost), which is `calFirstSliderDistance`:

```
rib j back face = #BoxDepth/2 - WallThickness - (j*calSliderDistance
                                                + calSliderDistance/2)
first slider    = #BoxDepth/2 - WallThickness - ((R-1)*calSliderDistance
                                                 + calFirstSliderDistance/2)
```

which is the feature tree's own split: `Replicate sliders` lays down the `R-1`
plain ones at a `calSliderDistance` pitch, and `First Slider` places the odd one
out. Exact on all six references — 25 ribs in all, from FCM 72's three to
Dominion 650's eight.

**`Box Dominion 246S` is what settles it.** Everywhere else
`calFirstSliderDistance == calSliderDistance`, so the frontmost rib is where a
plain pitch would put it anyway and the two readings cannot be told apart. On
`246S` they are `20.400` against `9.600`, and the measured rib pitch is
`15.000` — neither distance, but exactly their average, which is what
"back face on the slot centre" predicts and a constant pitch does not.

### `Round top of slider` rounds ACROSS the rib, not along it

**Radius `0.700`** on the two top edges parallel to X, leaving a `0.100` flat
between the two arcs. The rib's front face stays square to the rim — the third
top edge is NOT rounded, which is what says this is a two-edge fillet rather
than a domed end.

Same fit as the corners, at four depths: `u = 0.11 / 0.21 / 0.31 / 0.51` all
give `0.700` to four decimals.

### Watch which reference you fit a rim radius on

`Box Compile 105S` narrows by `0.254` at `0.11` below the rim where
`Box Dominion 246S without final fillet` does not narrow at all. That is not a
difference between the boxes: it is `Smooth box edges`, present in one export
and suppressed in the other, and `0.6 - sqrt(2·0.6·0.11 - 0.11²) = 0.254`
exactly. A useful independent confirmation of the `0.600` final fillet — and a
trap for anything else measured near `z = 105`.

## `Front pocket` — five features, and one plane over the top of them

Everything here is exact on all six references.

```
divider panel   y = -#BoxDepth/2 + WallThickness + calFrontPocketDepth,
                1.000 thick, the full inner width
dividers        right edge at -#BoxWidth/2 + WallThickness
                              + #calFirstLeftFrontDividerDist + k*calSlotwidth
                0.800 wide, k = 0 .. HorizontalSlots-2
padding         FrontPocketSidePaddingWidth = 5.800 against each end wall,
                filling the pocket front to back
slits           the SAME openings as the back's hanging holes — same X, same
                three rows
angled cutout   the plane through (y = front wall inner face, z = 68.600) and
                (y = panel BACK face, z = 87.500)
```

`#calFirstLeftFrontDividerDist` is the studio's own
`calSlotwidth + calFrontDividerLeftSpacing`, so the leftmost compartment is one
slot wide plus the side spacing and the rest are a slot each.

**The angled cutout is one plane and it shapes the whole group.** The padding's
top, each divider's top and the panel's top are not three separate numbers —
they are wherever that plane crosses each solid, which is why they all differ
per box and per X. Both endpoints hold to `0.001` on all six references while
the slope ranges from `0.349` to `1.323`, purely because `calFrontPocketDepth`
does. It starts exactly at the top of the lowered front wall, so `Lower the
front` and this are one continuous surface.

**`MatPocket` drops the RIGHTMOST divider**, merging the last two compartments
into the wide slot the mat needs — which is what
`calFrontSlotsForCards = HorizontalSlots - 2` counts.
`Box Dominion 244S` and `Box Dominion 202S Merged` are the same box with the
same envelope, and across a mid-pocket section the only difference is that one
divider: `3` against `2`.

### Shape the group before fusing it

Every piece reaches `WallThickness/2` into the wall it stands on, to keep the
fuse off a coincident face. The angled cut therefore has to reach those
overlaps too — clipped to the inner width it leaves a sliver of padding
standing to the rim inside each end wall, `1.816 mm³` a side. So the pocket is
built as one composite, cut, and only then fused, which also lets the cut run
the full width without touching the end walls (the STEP leaves those square to
the rim).

The corner-round probe is what caught it: `4.600` measured `4.800` of eaten
material on the build and `4.795` on the STEP, because the probe column sits in
the end wall and the sliver was in it.

## `Thumb and Lip`

### `Thumb`

A finger hole through the divider panel, **one per horizontal slot**:

```
centre X = -#BoxWidth/2 + WallThickness + calSliderSpaceLeftRight - 0.800
           + calSlotwidth/2 + k*calSlotwidth
centre Z = 87.500          the same height the angled cutout reaches
radius   = ThumbCutoutRadius = 12.000
fillet   = 0.400 into BOTH panel faces (`Fillet thumb hole`)
```

Exact on all six references, at `HorizontalSlots` 3, 4 and 5, and `MatPocket`
does not move them even though it drops a divider. The radius never reaches a
pad (`5.800` in) or a divider, so the thumb only ever meets the panel.

The fillet was read off the hole's profile through the panel — the radius at
eight depths, fitting `r - sqrt(2rt - t²)` to four decimals at every one. Note
the trap: a thin probe slab reports the section at the depth where the hole is
NARROWEST, which is the far side of the slab, so the whole profile reads one
slab-thickness shallow. Correct for that and `0.400` falls out; do not, and it
looks like a `0.275` fillet that fits nothing.

`box.thumb_tool` revolves the profile rather than cutting a cylinder and
calling `fillet()`, because the angled cutout takes the top off the hole — its
edge is an arc, not a circle. Use `ThreePointArc`, not `RadiusArc`: two points
and a radius admit four arcs and the one chosen left the hole a plain `12.400`
cylinder, which the STEP's own profile caught immediately.
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

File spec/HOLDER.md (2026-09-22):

# The Holder, measured

The card tray that rides the box's slider ribs. One per riser; a cascade's
holders form a staircase, and their sloped tops make one continuous diagonal
when the cascade is open. `automation/plan_exports.holder` is the design record
for WHY it is keyed the way it is; this file is the geometry.

## The ten references

Hand-exported from the Onshape UI, so 0 API calls, in `spec/reference/`, and
all ten are asserted against. Nothing is held out any more — see "`210 Card`
disagreed with its own sibling" below for the one that was.

| file | row | n | risers | sleeved | `calSlotwidth` | `calSliderDistance` | `calHeightIncrement` |
|---|---|---|---|---|---|---|---|
| `Holder S2.40.12-30.45-Sl.step` | Dominion `246 Card` | 3 | 2 | yes | 65.000 | 9.600 | 16.000 |
| `FirstHolder S2.40.12-30.45-Sl.step` | the same row's first riser | 3 | 2 | yes | 65.000 | **20.400** | 16.000 |
| `Holder S9.21.10.62-Sl.step` | Dominion `333 Card` | 3 | 9 | yes | 65.000 | 8.400 | 9.667 |
| `Holder M5.10.10.45-Sl.step` | Innovation `4 Later Ages` | 4 | 5 | yes | 69.000 | 8.900 | 17.400 |
| `Holder M5.10.10.32-Un.step` | the same row, unsleeved | 4 | 5 | no | 67.000 | 6.400 | 17.400 |
| `Holder XS5.15.10.45-Sl.step` | Innovation `Single Mini` | **2** | 5 | yes | 69.000 | 8.900 | 17.400 |
| `Holder S4.7.7.32-Sl.step` | Compile `105 Card` | 3 | 4 | yes | 70.000 | 8.000 | 18.000 |
| `Holder S4.18.12.32-Un.step` | FCM `198 Card` | 3 | 4 | no | 63.000 | 6.960 | 20.000 |
| `Holder L5.7.7.45-Sl.step` | Compile `210 Card` — RE-EXPORTED | **5** | 5 | yes | 70.000 | 8.000 | 17.400 |
| `Holder L5.7.7.20-Un.step` | the same row, unsleeved — RE-EXPORTED | **5** | 5 | no | 68.000 | 5.200 | 17.400 |

The 246 pair is the useful one for `first`: it is ONE configuration exported
twice, so the two differ only in what `first` changes, and its
`calSliderDistance` and `calFirstSliderDistance` differ by more than a factor of
two. The 333 holder is the same cascade whose Box and Pusher are already
references, and its rise is the catalogue's shallowest.

The **Innovation pair is what makes the rest general**. Everything measured on
the Dominion three was confirmed at `calSlotwidth 65.000` and three compartments
only; these are a SPANNING game at `69.000` and `67.000` with FOUR, and the
whole suite reproduces them with no change to any rule. So the width formula,
the slant, the pocket, the lattice at two more slot widths, the scallop with its
modelled fillet, and the side slot are all confirmed across two games, four slot
widths and both compartment counts. Whatever distinguishes a spanning game, it
is not any of these.

The **last five close the parameter space**. Between them they add every
remaining slot width (`63`, `68`, `70`), both remaining compartment counts (`2`
and `5`), and the two games that had no reference at all — and the one thing
that looked like a broken rule turned out to be a pair of mis-configured
exports. Every rule in this file is now checked at 2, 3, 4 AND 5 compartments,
at all five slot widths, in all four games, both sleevings, and against both
slider distances.

## The frame

    X   0 at the centre of the FIRST compartment, +k * calSlotwidth for the rest
    Y   0 at the REAR face, NEGATIVE going forward
    Z   0 is a datum inside the card pocket; the base sits at -45.250 on every
        reference, whatever the parameters

The sense of `Y` is fixed by `Rear lip`, below: Onshape calls that group the
REAR lip and its tabs stand at `Y > 0`, so `Y = 0` is the rear face and the
slant descends toward the front. (An earlier revision of this file had it the
other way round in this block and the right way round everywhere else.)

## What is settled
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

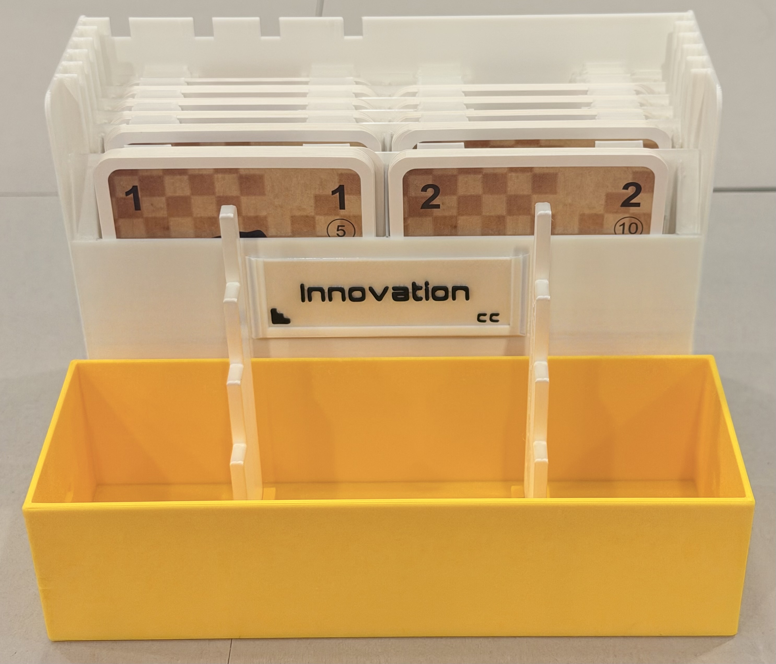
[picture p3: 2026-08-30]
cascades/Innovation/Photos/Single/Front lid in front.jpeg

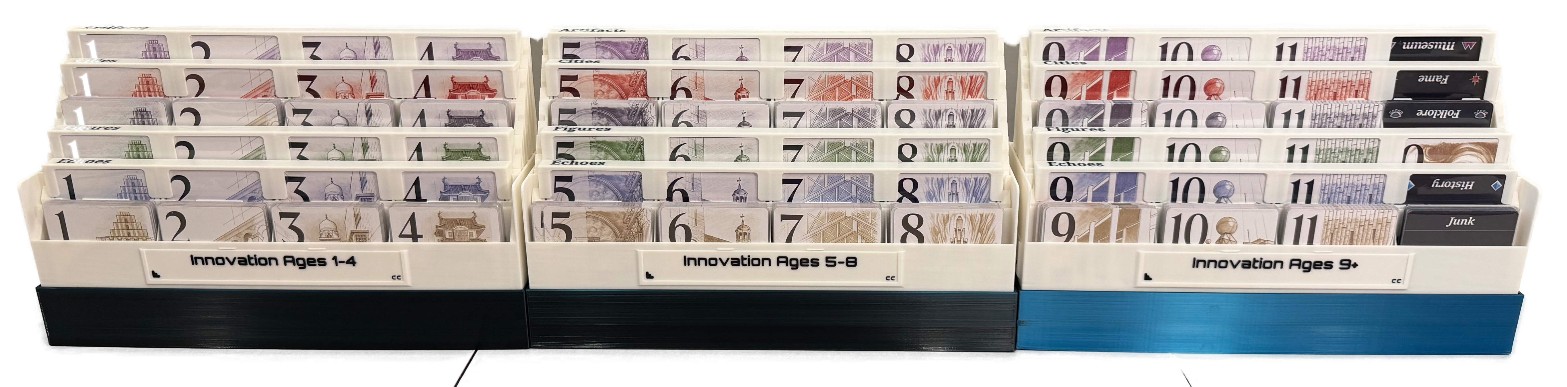
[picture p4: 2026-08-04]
cascades/Innovation/Photos/IU All Boxes Cascaded.png

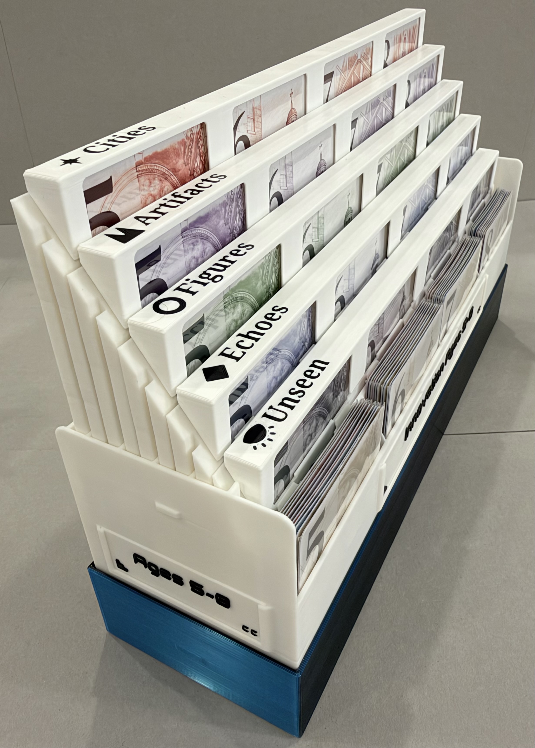
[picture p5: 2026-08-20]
cascades/Innovation/Photos/Inno 5-8 from a side angle.jpeg

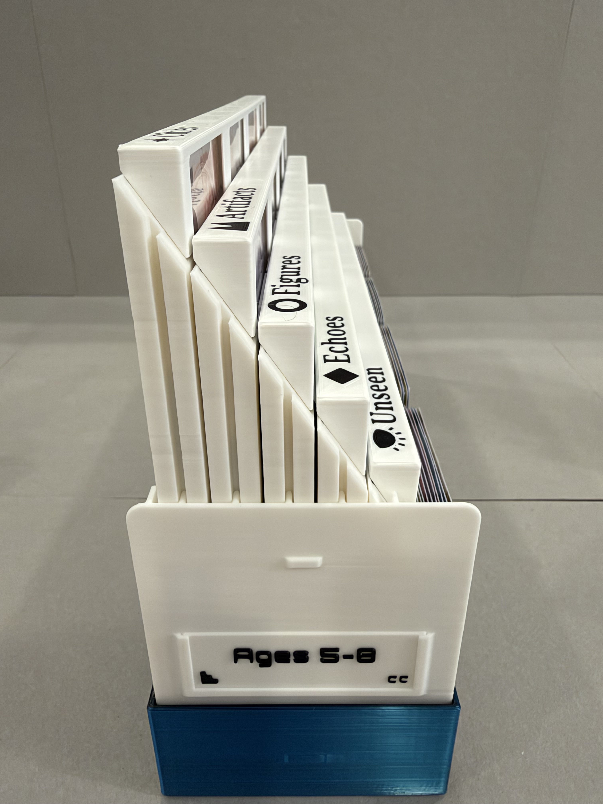
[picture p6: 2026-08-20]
cascades/Innovation/Photos/Inno 5-8 from the side cascaded.jpeg

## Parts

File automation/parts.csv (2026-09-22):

Short name | Base model | Unsl Model | Sleeved model | Game | Set/Extension | Status | Build | Horizontal | Risers | Cards/Riser slot | Cards/First Riser | Front capacity | Box Height / mm | Merged-slot | TokenHolder | 3D printer | Notes | Unsleeved W/mm | Unsleeved D/mm | Sleeved W/mm | Sleeved D/mm | Label holders | Project label | Toppers | Sleeved card width | Deep slot | Plain box | Unsleeved card width | Back pocket
105 Card | S4.7.7 | S4.7.7.20-Un | S4.7.7.32-Sl | Compile | Main and 1 extension | Pub 6.5 |  | 3 | 4 | 7 |  | 7 | 105 | FALSE |  | Standard |  | 222.9 | 36.3 | 228.9 | 50.3 |  |  |  |  |  | TRUE
126 Card | S5.7.7 | S5.7.7.20-Un | S5.7.7.45-Sl | Compile | Main 2, Aux 1 and 2 | Pub 6.5 |  | 3 | 5 | 7 |  | 7 | 105 | FALSE |  | Standard |  | 222.9 | 41.5 | 228.9 | 58.3 |  |  |  |  |  | TRUE
210 Card | L5.7.7 | L5.7.7.20-Un | L5.7.7.45-Sl | Compile | 10 sets, all sets | Pub 6.5 |  | 5 | 5 | 7 |  | 7 | 105 | FALSE |  | Large |  | 359 | 41.5 | 369 | 58.3 |  |  |  |  |  | TRUE
168 Card | S4.16.10 | S4.16.10.32-Un | S4.16.10.32-Sl | Dominion | Alchemy, Cornucopia, Guilds | Published |  | 3 | 4 | 10 |  | 16 | 105 | FALSE | full | Standard |  | 208 | 43.6 | 214 | 55.9
202 Card (Mat) | M4.21.10 | M4.21.10.32-Un | M4.21.10.45-Sl | Dominion | For split 400-decks with mats | Published |  | 4 | 4 | 10 |  | 21 | 105 | TRUE | full | Standard |  | 271 | 45.5 | 279 | 58.9
244 Card | M4.21.10 | M4.21.10.32-Un | M4.21.10.45-Sl | Dominion | Split Adventures, Nocturne, Plunder | Published |  | 4 | 4 | 10 |  | 21 | 105 | FALSE | full | Standard |  | 271 | 45.5 | 279 | 58.9
246 Card | S2.40.12/30 | S2.40.12/30.32-Un | S2.40.12/30.45-Sl | Dominion | Bulky Base Cards | Published |  | 3 | 2 | 12 | 30 | 40 | 105 | FALSE | none | Standard |  | 208 | 48.6 | 214 | 66.7
290 Card (Mat) | M6.21.10/12 | M6.21.10/12.0-Un | M6.21.10/12.0-Sl | Dominion | Speculation | Published | 6.6 | 4 | 6 | 10 | 12 | 21 |  | TRUE | full
300 Card | S5.40.12 | S5.40.12.45-Un | S5.40.12.62-Sl | Dominion | Base, split in 2 | Published |  | 3 | 5 | 12 |  | 40 | 105 | FALSE | full | Standard |  | 208 | 62.7 | 214 | 84.7
324 Card | M6.21.10 | M6.21.10.45-Un | M6.21.10.62-Sl | Dominion | Intrigue, Seaside, Prosperity, Hinterlands, Empires, Rising Sun | Published |  | 4 | 6 | 10 |  | 21 | 105 | FALSE | full | Standard | Standard size | 271 | 57.9 | 279 | 75.7
333 Card | S9.21.10 | S9.21.10.62-Un | S9.21.10.62-Sl | Dominion | Who knows? Small printers | Published |  | 3 | 9 | 10 |  | 21 | 105 | FALSE | full | Standard |  | 208 | 76.5 | 214 | 100.9
400 Card (Mat) | M8.40.10 | M8.40.10.62-Un | M8.40.10.62-Sl | Dominion | Adventures, Renaissance, Menagerie, Allies | Published |  | 4 | 8 | 10 |  | 40 | 105 | TRUE | full | Mixed | Unsleeved fits small printers | 271 | 77.5 | 279 | 103.9
472 Card | M2.60.18/40 | M2.60.18/40.45-Un | M2.60.18/40.62-Sl | Dominion | 6-player Base Cards Box | Published |  | 4 | 2 | 18 | 40 | 60 | 105 | FALSE | full | Mixed |  | 271 | 62.3 | 279 | 88.3
560 Card | L6.40.12 | L6.40.12.45-Un | L6.40.12.62-Sl | Dominion | Base game | Published |  | 5 | 6 | 12 |  | 40 | 105 | FALSE | full | Large |  | 334 | 69.6 | 344 | 94.3
650 Card | L8.50.10 | L8.50.10.62-Un | L8.50.10.62-Sl | Dominion | Dark Ages, Nocturne, Plunder | Published |  | 5 | 8 | 10 |  | 50 | 105 | FALSE | full | Large |  | 334 | 81.3 | 344 | 109.9
144 Card | M5.6.6 | M5.6.6.20-Un | M5.6.6.32-Sl | Food Chain Magnate | Milestones | Pub 7.0 |  | 4 | 5 | 6 |  | 6 | 105 | FALSE |  | Standard | Base/Ketchup | 271 | 38.4 | 279 | 46.3 |  | Milestones 1
180 Card | L3.18.6 | L3.18.6.20-Un | L3.18.6.20-Sl | Food Chain Magnate | Occupations 2/2 | Pub 7.0 |  | 5 | 3 | 6 |  | 18 | 105 | FALSE |  | Large | Base game | 334 | 33.6 | 344 | 41.5 |  | Occ 2
264 Card | M4.18.12 | M4.18.12.32-Un | M4.18.12.45-Sl | Food Chain Magnate | Occupations 1/2 | Pub 7.0 |  | 4 | 4 | 12 |  | 18 | 105 | FALSE |  | Standard | Base game | 271 | 47.4 | 279 | 61.9 |  | Occ 1
198 Card | S4.18.12 | S4.18.12.32-Un | S4.18.12.45-Sl | Food Chain Magnate | Occupations 3 | Pub 7.0 |  | 3 | 4 | 12 |  | 18 | 105 | FALSE |  | Standard | Occupations re-split; unsleeved W/D confirmed against the built lid | 208 | 47.4 | 214 | 61.9 |  | Alt
3 Ages 5 Expansions | S5.15.15 | S5.15.15.45-Un | S5.15.15.62-Sl | Innovation | Ultimate, 1/4 | Drafting |  | 3 | 5 | 15 |  | 15 | 105 | FALSE |  | Standard | 4 boxes | 220 | 60.7 | 226 | 83.2
4 Ages 5 Expansions | M5.15.15 | M5.15.15.45-Un | M5.15.15.62-Sl | Innovation | Ultimate, 1/3rd | Drafting |  | 4 | 5 | 15 |  | 15 | 105 | FALSE |  | Mixed | 3 boxes | 287 | 60.7 | 295 | 83.2
Single Set | S3.15.10 | S3.15.10.20-Un | S3.15.10.32-Sl | Innovation | Base set or one expansion | Drafting |  | 3 | 3 | 10 |  | 15 | 105 | FALSE |  | Standard | 10-card sliding slots (every other Innovation box is 15); W/D measured off the lid | 220 | 37.9 | 226 | 49.2
Single Mini | XS5.15.10 | XS5.15.10.32-Un | XS5.15.10.45-Sl | Innovation | Base set or one expansion | Drafting |  | 2 | 5 | 10 |  | 15 | 105 | FALSE |  | Mini | XS: 2 cards wide, where every other box is 3 or 4. Front label is the 62 (the 150.9 mm box front cannot take the 156.4); W/D measured off the lid. Used in PAIRS, and from 7.2g the pair divides the work (Allan, 2026-09-14): `Back pocket` ships TWO boxes and no ordinary one — `open` has no dividers or notches at all, so its back pocket is the full 149.1 inner width and takes the 128 mm player aids, and `notches` hangs the pair's pushers, 4 unsleeved and 3 sleeved (four sleeved pushers need 178 of bare width and fit no XS box; the 4th travels elsewhere). `Unsleeved card width` 66 is the SLEEVED width, which makes the unsleeved twin as wide as the sleeved one: that is what gets the 4th unsleeved pusher in (145.6 of 149.1, against 145.1 before) and it makes the pair's two lids interchangeable. Width only — the depth, the capacity and the rise do not move, and the model code still reads .32-Un. | 156.9 | 50.7 | 156.9 | 66.9 |  |  |  |  |  |  | 66 | open+notches
3 Later Ages 5 Expansions | S5.10.10 | S5.10.10.32-Un | S5.10.10.45-Sl | Innovation | Ultimate, 1/4 | Drafting |  | 3 | 5 | 10 |  | 10 | 105 | FALSE |  | Standard | 10 cards in EVERY sliding slot — no room for the bulkier Age 1 cards, hence 'Later Ages'. W/D CONFIRMED against the built lid: measured 219.90/225.90 (S) and 286.90/294.90 (M) wide by 50.10/65.10 deep, i.e. the depth model was exact and the width carries this column's usual +0.1 rounding. Sleeved M is 254.6 mm on the P1 diagonal (0.7 mm/edge) and its short edge passes 1.04 mm from the P1's excluded corner at +45°, which make_cascade shifts the plate in x to clear. Sliced clean. Needs --bed p1 (auto picks H2C); 5 plates, the holders and toppers fitting one plate each via the two-arm strip packing. | 220 | 48.7 | 226 | 63.7
4 Later Ages 5 Expansions | M5.10.10 | M5.10.10.32-Un | M5.10.10.45-Sl | Innovation | Ultimate, 1/3rd | Drafting |  | 4 | 5 | 10 |  | 10 | 105 | FALSE |  | Standard | 10 cards in EVERY sliding slot — no room for the bulkier Age 1 cards, hence 'Later Ages'. W/D CONFIRMED against the built lid: measured 219.90/225.90 (S) and 286.90/294.90 (M) wide by 50.10/65.10 deep, i.e. the depth model was exact and the width carries this column's usual +0.1 rounding. Sleeved M is 254.6 mm on the P1 diagonal (0.7 mm/edge) and its short edge passes 1.04 mm from the P1's excluded corner at +45°, which make_cascade shifts the plate in x to clear. Sliced clean. Needs --bed p1 (auto picks H2C); 5 plates, the holders and toppers fitting one plate each via the two-arm strip packing. | 287 | 48.7 | 295 | 63.7
Three Expansions | M8.16.10-16 | M8.16.10-16.45-Un | M8.16.10-16.62-Sl | Innovation | Ultimate, 1/2 | Drafting |  | 4 | 8 | 10 | 16 | 16 | 105 | FALSE |  | Mixed | Three expansions per cascade, and TWO of them lying on their backs hold all six in the Innovation box (288 x 263 x 76 inside) with no lid lift: 286.9 wide along the 288, two closed heights (213.2) along the 263, 74.1 deep as the height. Sized to the sets rather than to a capacity: an expansion is 12 groups, two of 16 and ten of 10, so the 16-card front pocket and first riser take the 16s and the 10-card risers the rest -- 36 slots for 36 groups, 408 capacity for 396 cards. Sleeved: `Sleeved card width` 64 (Allan, 2026-09-12: his sleeved cards fit 65 x 90) makes the slot 67 and the lid 286.9 like the unsleeved, so the pair still lies flat in the game box; at 99.6 deep it lifts the lid 23.6, which he prefers to any cut deeper than that. The deep riser is at the BACK (`Deep slot` = back, Allan 2026-09-12): it holds the expansion's achievements and player aids, wanted once at setup, so the least stable riser is the one used least. Rise 10.875 (Dominion's 8-riser rise); no cached toppers, so cad.assemble --no-toppers. W/D are the derived lid sizes, not measured. | 286.9 | 72.7 | 286.9 | 98.2 |  |  | none | 64 | back
350 Card | 86-L6.10.10 | 86-L6.10.10.32-Un | 86-L6.10.10.45-Sl | Mini Cards | 41 x 63 mm cards | Drafting |  | 5 | 6 | 10 |  | 10 | 86 | FALSE |  | Standard | GENERIC: for any game with 41 x 63 mm cards, to show what the 86 mm mini height class can do (spec/BOX.md, "Shorter cards"). Blank lid only, (C) Mertner where a game name would be; blank 12 mm labels (cc.cfg MiniCards). Card thicknesses 0.35 unsleeved / 0.60 sleeved are typical, not measured. | 238.9 | 51.6 | 248.9 | 69.1
288 Card | 86-M5.12.12 | 86-M5.12.12.32-Un | 86-M5.12.12.45-Sl | Mini Cards | 41 x 63 mm cards | Drafting |  | 4 | 5 | 12 |  | 12 | 86 | FALSE |  | Standard | GENERIC: for any game with 41 x 63 mm cards, to show what the 86 mm mini height class can do (spec/BOX.md, "Shorter cards"). Blank lid only, (C) Mertner where a game name would be; blank 12 mm labels (cc.cfg MiniCards). Card thicknesses 0.35 unsleeved / 0.60 sleeved are typical, not measured. | 194.9 | 49.9 | 202.9 | 67.9
216 Card | 86-S5.12.12 | 86-S5.12.12.32-Un | 86-S5.12.12.45-Sl | Mini Cards | 41 x 63 mm cards | Drafting |  | 3 | 5 | 12 |  | 12 | 86 | FALSE |  | Standard | GENERIC: for any game with 41 x 63 mm cards, to show what the 86 mm mini height class can do (spec/BOX.md, "Shorter cards"). Blank lid only, (C) Mertner where a game name would be; blank 12 mm labels (cc.cfg MiniCards). Card thicknesses 0.35 unsleeved / 0.60 sleeved are typical, not measured. | 150.9 | 49.9 | 156.9 | 67.9
120 Card | 86-XS5.10.10 | 86-XS5.10.10.32-Un | 86-XS5.10.10.45-Sl | Mini Cards | 41 x 63 mm cards | Drafting |  | 2 | 5 | 10 |  | 10 | 86 | FALSE |  | Standard | GENERIC: for any game with 41 x 63 mm cards, to show what the 86 mm mini height class can do (spec/BOX.md, "Shorter cards"). Blank lid only, (C) Mertner where a game name would be; blank 12 mm labels (cc.cfg MiniCards). Card thicknesses 0.35 unsleeved / 0.60 sleeved are typical, not measured. Five risers, not six: two SLEEVED six-riser pushers need 110.4 of back storage and the XS box has 103.1 (Allan, 2026-09-22). | 106.9 | 45.7 | 110.9 | 60.7

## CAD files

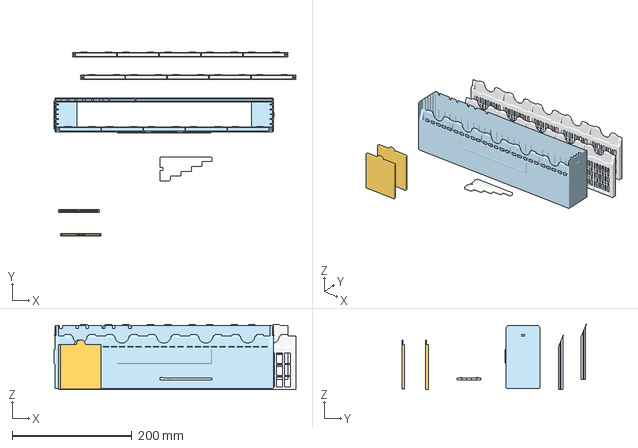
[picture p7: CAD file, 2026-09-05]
individual/Compile/_raw/Assembly L5.7.7.45-Sl.3mf
403.8 x 307.4 x 108.6 mm

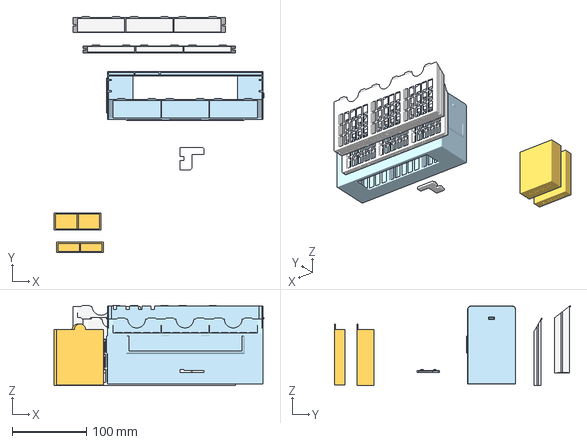
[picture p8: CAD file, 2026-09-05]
individual/Dominion/_raw/Assembly S2.40.12-30.45-Sl.3mf
281.9 x 317.5 x 107.9 mm

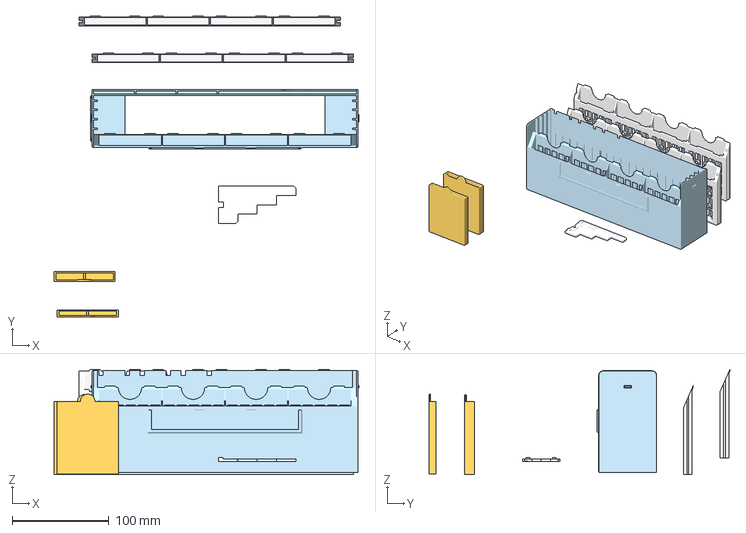
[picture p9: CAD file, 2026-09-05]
individual/FCM/_raw/Assembly M4.18.12.45-Sl.3mf
314.4 x 310.0 x 108.6 mm

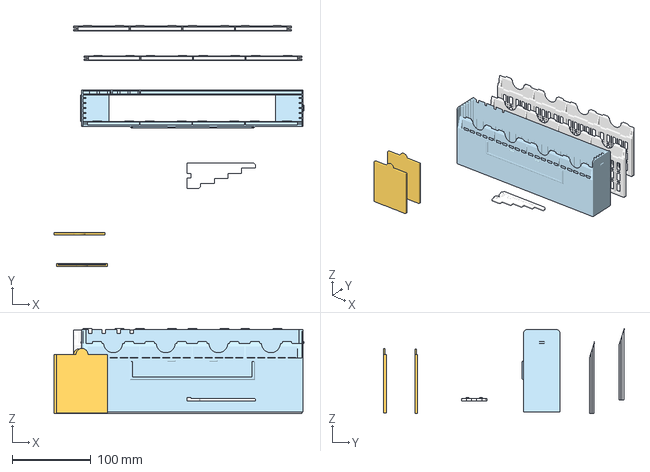
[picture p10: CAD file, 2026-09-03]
individual/Innovation/_raw/Assembly M5.10.10.32-Un.3mf
318.4 x 306.4 x 108.6 mm

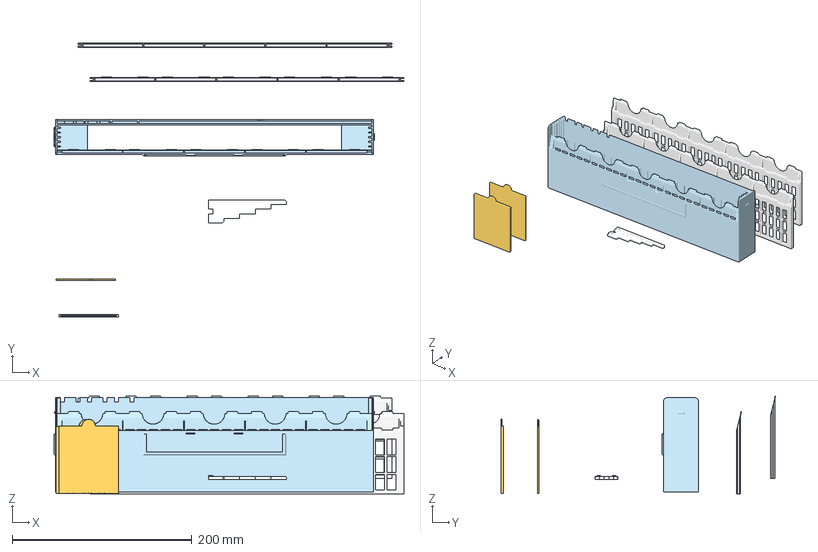
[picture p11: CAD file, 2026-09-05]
individual/Compile/_raw/Assembly L5.7.7.20-Un.3mf
389.8 x 305.7 x 108.7 mm

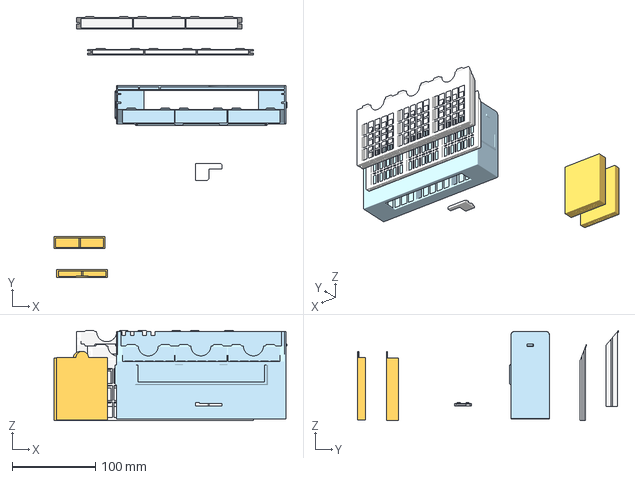
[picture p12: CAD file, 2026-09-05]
individual/Dominion/_raw/Assembly S2.40.12-30.32-Un.3mf
278.9 x 312.7 x 108.2 mm

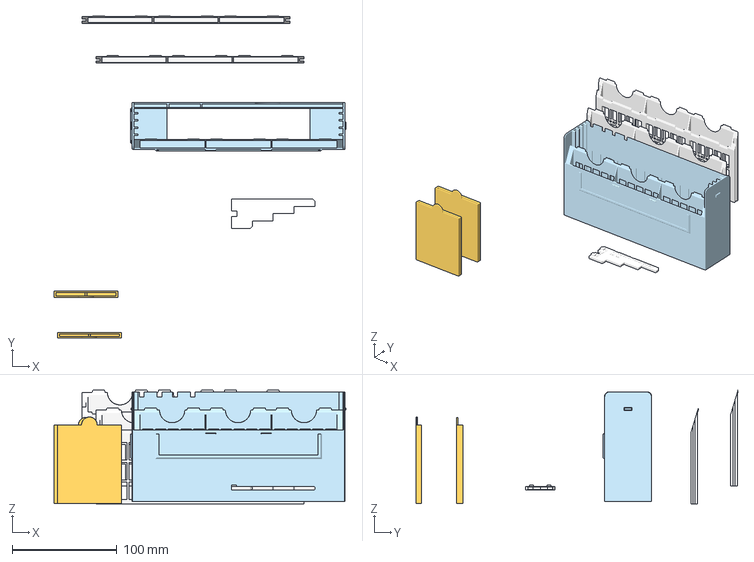
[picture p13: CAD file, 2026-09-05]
individual/FCM/_raw/Assembly S4.18.12.32-Un.3mf
278.9 x 307.8 x 108.6 mm

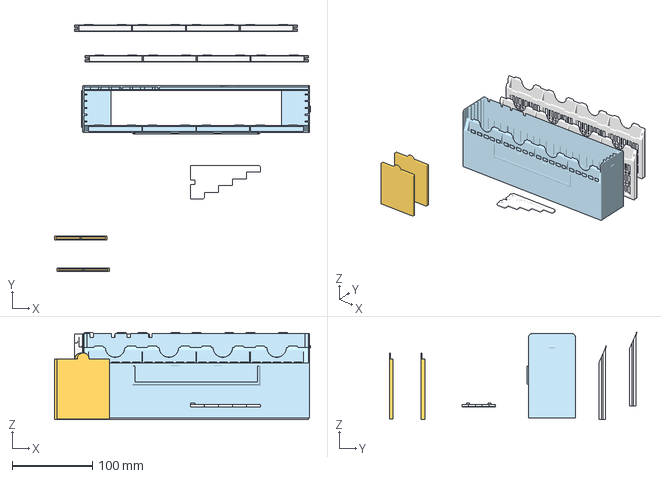
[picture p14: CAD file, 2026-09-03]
individual/Innovation/_raw/Assembly M5.15.15.45-Un.3mf
318.4 x 307.6 x 108.6 mm

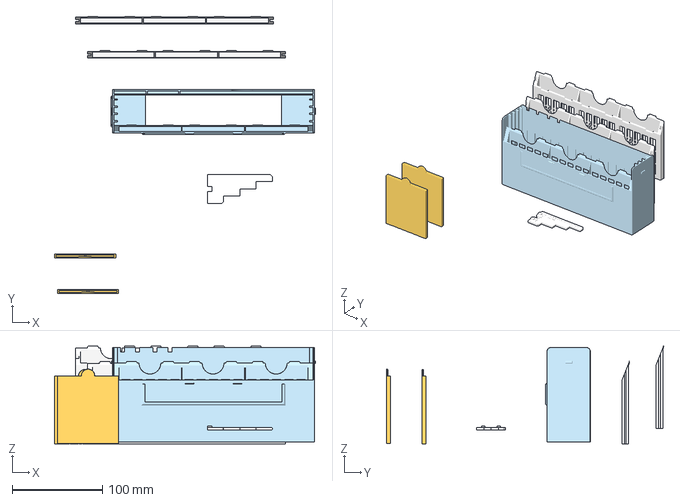
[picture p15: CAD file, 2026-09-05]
individual/Compile/_raw/Assembly S4.7.7.32-Sl.3mf
289.4 x 307.4 x 108.6 mm

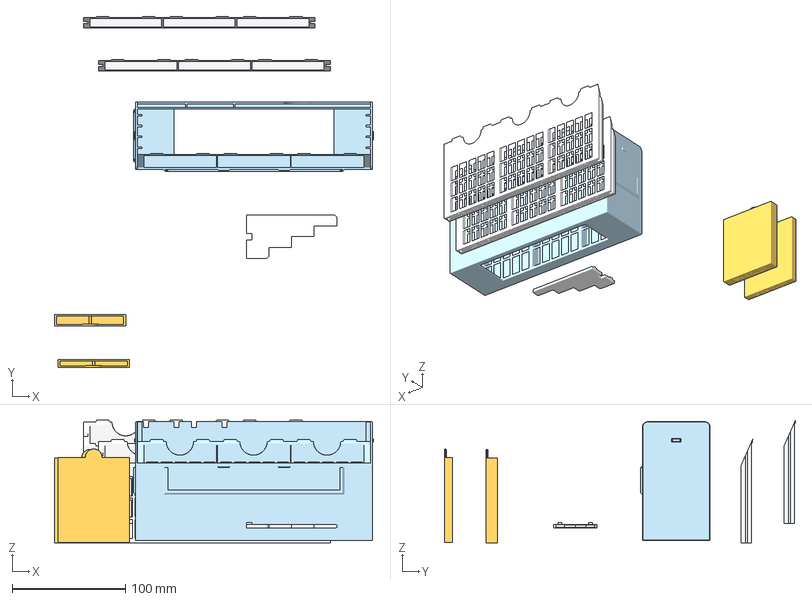
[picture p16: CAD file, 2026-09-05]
individual/FCM/_raw/Assembly S4.18.12.45-Sl.3mf
281.9 x 310.0 x 108.6 mm

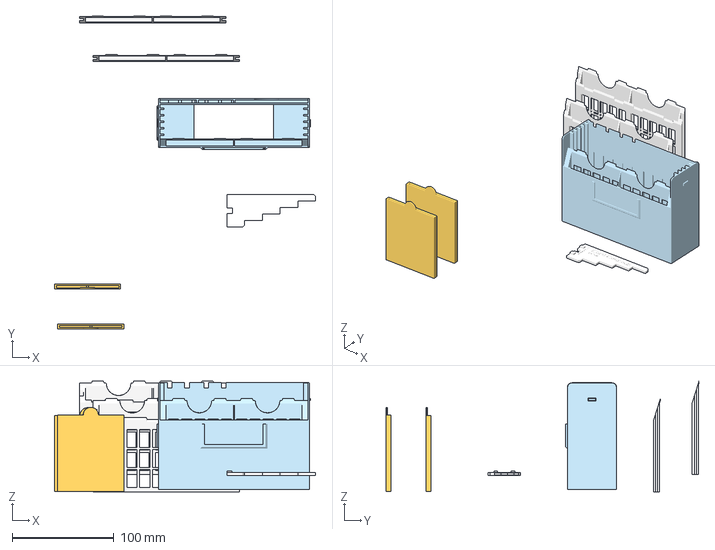
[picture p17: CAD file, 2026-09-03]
individual/Innovation/_raw/Assembly XS5.15.10.32-Un.3mf
256.5 x 307.4 x 108.6 mm

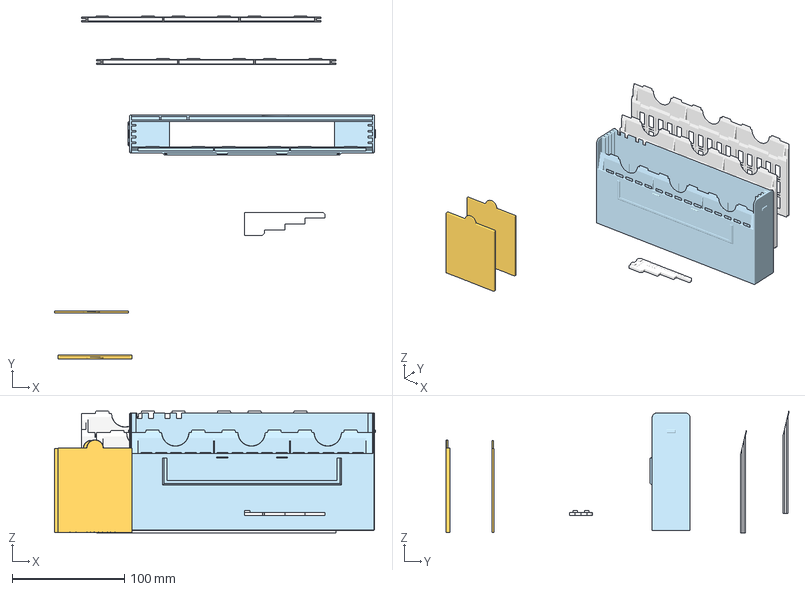
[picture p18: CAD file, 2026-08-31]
individual/Compile/_raw/Assembly S4.7.7.20-Un.3mf
286.4 x 305.7 x 108.7 mm

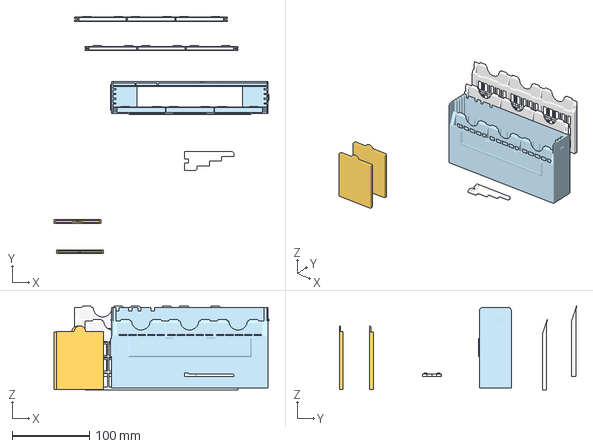
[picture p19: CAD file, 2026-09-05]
individual/Dominion/_raw/Assembly S4.16.10.32-Un.3mf
278.9 x 307.5 x 108.6 mm

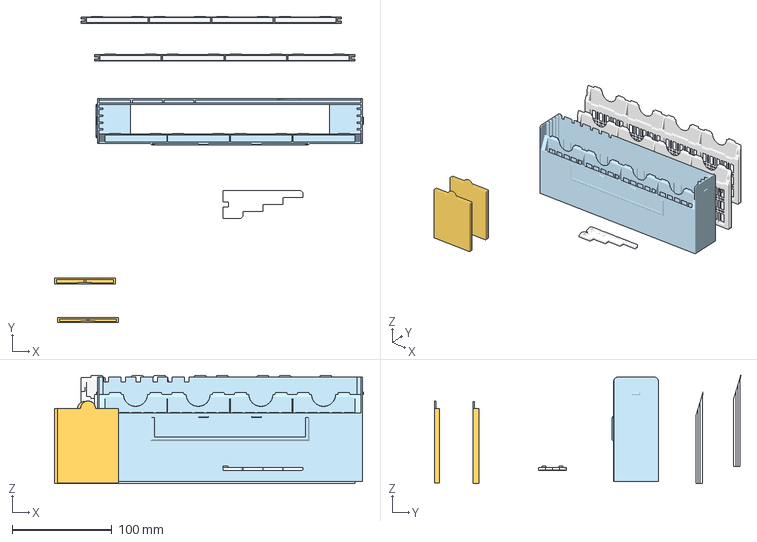
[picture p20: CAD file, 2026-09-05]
individual/FCM/_raw/Assembly M4.18.12.32-Un.3mf
310.4 x 307.8 x 108.6 mm

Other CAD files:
individual/Dominion/_raw/Assembly M4.21.10.32-Un merged.3mf
individual/Innovation/_raw/Assembly S5.10.10.32-Un.3mf
individual/Dominion/_raw/Assembly M6.21.10.62-Sl.3mf
individual/FCM/_raw/Assembly M5.6.6.32-Sl.3mf
_templates/innovation_h2c.3mf
cascades/Colours/Mamta Box 1.3mf
cascades/Compile/Compile 105 Card Sleeved (S4.7.7.32-Sl).3mf
cascades/Compile/Compile 105 Card Unsleeved (S4.7.7.20-Un).3mf
cascades/Compile/Compile 126 Card Sleeved (S5.7.7.45-Sl).3mf
cascades/Compile/Compile 126 Card Unsleeved (S5.7.7.20-Un).3mf
cascades/Compile/Compile 210 Card Sleeved (L5.7.7.45-Sl).3mf
cascades/Compile/Compile 210 Card Unsleeved (L5.7.7.20-Un).3mf
cascades/Compile/labels/Compile Labels.3mf
cascades/Compile/labels/Compile Logo Labels.3mf
cascades/Dominion/Dominion 168 Card Sleeved (S4.16.10.32-Sl).3mf
cascades/Dominion/Dominion 168 Card Unsleeved (S4.16.10.32-Un).3mf
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

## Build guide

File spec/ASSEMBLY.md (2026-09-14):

# Assemblies

Placing the `cad/` parts into a whole cascade, in the two states a cascade has:
**closed** (on the shelf) and **cascaded** (open, ready to play). Two purposes,
and they pull in the same direction:

1. **A fit test.** Every clearance in the design is currently asserted one part
   at a time, against a reference that only ever shows that part. An assembly
   is the first thing that can measure the mechanism: does the tab sit in the
   cutout, does the plate sit in the channel, does the holder clear the rib.
2. **Renders.** Front, back, left, right, top, bottom and one perspective, per
   state, for listings and for looking at a build without Studio.

They pull in the same direction more literally than expected: the closed lid's
logo came out upside down under a placement that measured `0.0000 mm3` against
every part, because the two candidates differed by a proper rotation and no
number could see it. A render is part of the checking, not its output.

Nothing here is a new geometry input. Every placement below is derived from
`derive.py` and the part modules, and where a placement had to be *chosen*
rather than derived, this file says so and says what settled it.

`cad/assembly.py` is this file in code — placements and nothing else, importing
no build123d, the same split `derive.py` has. `cad/assemble.py` writes the
3MFs, `cad/fit.py` measures them.

---

## The cascade frame

The **Box's part frame is the assembly frame**: X width with 0 at the centre,
Y depth with 0 at the centre and +Y toward the back, Z with 0 at the bed. The
Box is therefore placed by the identity, which is also what `cad/build.py`
already does ("Boxes are NOT placed in an assembly offset — the part studio's
origin is the assembly's").

Every other part carries a transform into that frame. The corpus cannot supply
one: `individual/<Game>/_raw/Assembly *.3mf` looks like it should, but its
`<components>` transforms are the **print layout** — six parts translated side
by side on a bed — and `assembly_split.py` discards them and writes each object
at its own part-studio coordinates. So the components on disk are each in their
own frame and no shared frame exists anywhere in the repo. Building one is the
work.

## The three assemblies

| state | contents |
|---|---|
| `closed` | Box, holders on the floor over the sliders, pushers stored in the rear, TokenHolder(s) in the front pocket, a topper on each holder (Innovation) |
| `closed-lid` | the same, plus the Lid inverted over the Box |
| `play` | Lid opening-up underneath, Box sitting in it, pushers standing in the Lid's sockets and rising through the Box's floor slot, holders on the pushers' treads and riding the sliders |

Counts come from `plan_exports.compose`: one Box, one Lid, `pushers` (2, or 3
on M/L for every game but Innovation), `RisingSliders` holders — one of them
the `FirstHolder` where `Cards/First Riser` is set — and, where parts.csv's
`TokenHolder` column says so, a TokenHolder plus a HalfTokenHolder on a merged
row. `--half` swaps the HALF in on a merged row; the two are alternatives for
one slot, so only one is ever placed.

## The placements

### Lid, closed — a 180° turn about Y, and it is a choice

    box = (-lid_x,  lid_y + 2.250,  (WallThickness + BoxHeight) - lid_z)

The Z half is written down in `parts/lid.py`: "a box height `h` arrives at
`WALL + BoxHeight - h` in the lid's frame", in `closing_grooves`. The check is
the closing mechanism — the Box's bump tops out at box `z 90.000` and the
groove's bottom edge sits at lid `z 16.600`, and `106.600 - 16.600 = 90.000`
exactly. The Lid's rim lands at box `z 66.600`, so the two overlap by 38.400.

**Which axis the turn is about, nothing geometric can decide — the lid goes on
either way round.** The two candidates differ by a half turn about Z, a proper
rotation, so:

* the closing groove fits either way. The Box's bump sits at box `y
  -1.750..6.250`, symmetric about the `2.250` both turns pivot on, so it
  arrives at lid `y -4.000..4.000` under both;
* interference is `0.0000 mm3` under both. The sockets hang from box `z
  105.000` to `100.000`; the rear storage caps at `REAR_TOP` 85.000, the front
  pocket at 87.500, and a holder tops out at ~93.05 on every cascade
  (`CardHeight` is 92.000 for every game), so nothing of the box or its
  contents reaches them at either end. (A 92 card standing in the holder
  reaches 95.800, which is what the sockets actually clear — by 4.200 — and
  is what bounds a box's height. `cad.fit` reports it as "socket underside
  over the card top", and the tallest holder beside it.)
* the sockets are EMPTY when a cascade is closed — the pushers are in the rear
  storage — so nothing functional depends on where they land.

The only thing that can tell is the logo, and it does not agree with itself.

## The logo finding: three games disagree with the fourth

The lid's logo pattern is in the floor's OUTER face, which points up once the
lid is on, so it is the one mark a closed cascade shows. Rendered in plan:

| game | reads upright under |
|---|---|
| Dominion | a turn about **X** |
| Compile | a turn about **Y** |
| FCM | a turn about **Y** |
| Innovation | a turn about **Y** |

**One game's mark WAS upside down on a closed lid whichever turn was chosen
— until 2026-09-04.** Nothing in `cad/` rotates the artwork — there is no
per-game transform in `parts/lid.py` or `art.py` — so the four
`logos/<Game>/lid_logo.dxf` disagreed with each other. And the build's inlays
matched the cached Onshape lid's to 0.001 in every X span, so Onshape
imported the same files and **this was on the shipped product**, not on the
rebuild.

`Y` is used, because three of the four read correctly under it, and the
photograph of three closed Innovation boxes reading upright from the
labelled front says the three are right. Allan had Dominion's DXF turned on
2026-09-04 — and turned BACK on 2026-09-11, when a printed Dominion lid came
out upside down (`spec/LID.md`, "Dominion's mark — turned 2026-09-04, turned
BACK 2026-09-11"). A printed Innovation lid read upside down the same day,
and its mark now goes into the lid turned (`cad/tables.LID_LOGO_TURNED`), so
the table above is the state of the DRAWINGS and Innovation's built mark now
reads with Dominion's. The photograph was misread. Compile and FCM still
read under `Y`, and the prints predict they are upside down too; that is
open until a printed lid of each is looked at. `tests/test_lid.py` holds
Dominion's regions to the reference as drawn and Innovation's to it turned.

The route to this is worth recording, because it is a lesson about method
twice over. The placement was first written as `Y`, then changed to `X` on the
strength of a single Dominion render that came out upside down, then changed
back when four games were rendered instead of one. Inferring a placement from
one instance of imported artwork is exactly the mistake `spec/LID.md` records
under "What the fit got wrong". And it took a PICTURE to see any of it: an
upside-down logo is invisible to every number `cad/fit.py` computes, because
the two candidates differ by a proper rotation.

### Lid, open — the Box drops into it

    box = (lid_x,  lid_y + 2.250,  lid_z - WallThickness)

The Lid inner is `BoxWidth + 1.400` wide and `box_depth + 4.900` deep, against
a Box footprint of `BoxWidth` by `box_depth + 4.500` (the sketch box plus
`REAR_DEPTH`): **0.700 a side** in width and **0.400 total** in depth. The Box's
floor sits on the Lid's floor.

### Pusher, stored — hung in the rear storage

The part is turned on edge and upright: its **rise runs up the box's Z**, its
**depth across the box's X**, and its **thickness into the 3.200 slot band** in
Y. That is `pusher_rest`'s own reading — `#dBackSlotWidth` is
`calPusherTotalDepth + 4.000` measured along the width.

* **X** — the tabs sit at part `y = -D/2 ± s` and the Box's rim cutouts at
  `slot_centre ± s`, so part `y = -D/2` maps to `slot_centre`. Slot centres are
  `box.pusher_slots`.
* **Z** — part `x = 0` (the leading edge, where the tabs are) maps to box
  `z = BoxHeight`, i.e. **the pusher hangs by its tabs, top flush with the rim**.
  The evidence is `pusher_rest = min(25.000, BoxHeight - H - 0.500)`: it is a
  *catch* 0.500 below a top-flush pusher, not a shelf. Innovation's 87.000 mm
  pusher is the case where the `min` bites — rest 17.500, top 105.000, bottom
  18.000 — and the arithmetic only closes on the flush reading. The tab's
  5.000 then fills the rim cutout's `z 100.000..105.000` exactly.
* **Y** — the plate in the slot band (`box.slot_band`, 3.200 on a 3.000 plate),
  tabs pointing back into the cutouts cut through the 1.300 inner back wall.

Which way round the depth axis runs (`+y → +x` or `+y → -x`) is symmetric in
the tabs and is **not** derivable from the lock; only one lets the staircase
sit in the cavity. The fit test picks it.

### Pusher, in play — in the Lid socket

Vertical, plate in the socket's `LID_CHANNEL_W` (3.300 on a 3.000 plate — the
tightest running clearance in the mechanism), tabs in the two recesses cut into
the channel's −X wall at `centre ± s`, notch over the key rib (C3–C5). The
socket stands at lid `z 1.600..6.600`, so the leading edge goes down into it and
the rise runs up through the Box's `bottom_slot`. Confirmed reachable: on
Dominion `S4.16.10`, socket centres are ±63.0 against a floor slot 137.100 wide.

Innovation was the one asymmetry, and **at 7.1 it is gone from the part**
rather than worked around here. A 7.0 lid takes 3 sockets from M up (Onshape's
size rule) while the cascade ships **2** pushers (`isOnlyTwoPusherSlots`), so
the open state used the OUTER PAIR and the middle socket stood empty in every
render. From 7.1 `lid.socket_count` is `box.pusher_slot_count` and the middle
one is cut (`spec/LID.md`, "The middle socket is gone"; `spec/REVISIONS.md`),
so `play_sockets` is the identity: every socket holds a pusher, at BOTH
releases. It can be the identity at 7.0 too because the count is the lid's own
— a 7.0 Innovation M lid still has three sockets and the assembly still fills
two of them, the outer pair, exactly as before.

`cad.assemble` and `cad.fit` therefore take `--version`: the mechanism has to
be checkable at each release, and an empty middle socket in a 7.0 render is the
honest picture of what is on the shelf.

### Holder

* **X** — `box_x = holder_x - (HorizontalSlots - 1) * calSlotwidth / 2`. The
  holder is `calSlotwidth * H + 9.800` wide in a `calSlotwidth * H + 11.100`
  inner box, so it centres with **0.650 a side**, and its 1.900 end slots take
  the Box's 1.500 slider ribs.
* **Y** — one holder per rib, its side slot on that rib: `box.slider_ribs`
  gives the rib backs, and the slot is centred on the holder's depth.
* **Z, closed** — the base on the floor: `box_z = holder_z + box.floor_top +
  (CardHeight - 1.5)/2`. The two `side_floor` strips are what it rests on, which
  is what they are for. The datum is `box.floor_top` and NOT `WallThickness`:
  they are the same `1.600` through 7.0 and part company at 7.1, where the
  floor is `2.000` and the wall is not (`spec/BOX.md`, "The floor is 2.000, and
  it grows UPWARD"). Every holder in the catalogue rises `0.400` with it, into
  headroom of `12.900`.
* **Z, open** — the base on the pusher's step `k`, whose tread is at part
  `x = k * calHeightIncrement`, so the whole set rises `calHeightIncrement` a
  riser and the slant tops make one diagonal.

From 7.2e two numbers the LIPS need come from these placements
(`spec/HOLDER.md`, "Lips that seat"), stated here and read by the parts:
`front_holder_gap` — the divider panel's back face to the front holder's
front face, `1.250` on every row, which the Box's lip crosses before it
enters that holder's rest; and `box_lip_seat` — how far below the front
holder's slant surface, at the panel, the box lip's underside sits in play,
which is how deep every holder's rest is cut (`holder.rest_depth`);
`box_lip_diagonal`, the Z where that slant surface crosses the panel; and
`box_lip_top`, the same surface at the holder's own front face, which from
7.2f is where the flat box lip's top sits (`box.lip_z`). From 7.2f the ribs
are `box.rib_shift` (0.850) forward of the studio's position and the gap is
0.400 (`spec/BOX.md`, "The ribs move forward"), the box and lid are
`calRearTrim` 1.400 shallower, and the lid's sockets follow the ribs
(`lid.socket_back`), so the 0.150 below is 0.000: a holder sits centred on
its tread, 0.200 each way.

The `FirstHolder` is the deeper one and takes the first (frontmost) rib, which
is the one `slider_ribs` places at `calFirstSliderDistance`.
With `Deep slot` = back the deep holder takes rib 0 instead (`holder_rib`).
And from 7.2a riser 0's holder is the **`RearHolder`**, the same holder without
its rear lips (`assembly.rear_of`, `holder_kinds`; `spec/HOLDER.md`, "The
RearHolder"): where the deep slot is at the back the RearHolder is the deep
one and there is no FirstHolder.

### TokenHolder — a half turn about Z, and the FULL only

Its frame's origin is already **the slot's corner** — X at the slot's left edge,
Y at its front edge, Z at the base — so the placement is just where that slot is
in the box: `box.front_dividers` in X, `box.pocket_span` in Y,
`z = box.floor_top` — the box's floor, `1.600` through 7.0 and `2.000` from
7.1, and not the wall's thickness that happened to equal it.

**Its Y runs the opposite way to the box's**, so with X alone flipped the
placement would be a MIRROR, which no physical part is. A half turn about Z is
the only proper rotation that fits, and it also says what "left edge of the
slot" means: left as seen from behind, which is the box's **+X** end.

Two independent expressions give that end and agree exactly — the last front
divider's right edge plus `calTokenHolderSlotWidth`, and the right inner wall
less `FrontPocketSidePaddingWidth`, both 94.250 on `S4.16.10`. The **divider**
is used as the datum, though they give the same number, because it is the
sketch's own. The rival placement at the inner wall itself collides with the
Box by 1457.2448 mm3, so this is a test that distinguishes rather than one that
merely permits.

**FULL and HALF are alternatives, not both at once.** They are the same width,
and `spec/TOKENHOLDER.md` says a half holder is not half of a full one and that
they are not meant to stack in depth. A merged cascade ships one of each and
the slot takes whichever suits; the assembly places the FULL, which every
token-holder row gets.

### Topper — its slant IS the holder's slant

`spec/TOPPER.md` and `cad/parts/topper.py` are the authority, and they make
this placement **exact rather than fitted**. Two of the part's own features say
what it mates to:

* **`TriangleMatch`** extrudes the HOLDER's own `Top slant angle` face, so the
  topper's slant *is* the holder's — `topper.slant_slope` is
  `holder.slant_slope`, to six decimals on every parameter set;
* **`Room for Lips`** notches the topper's REAR wall for the holder's rear
  lips, binding to `holder.lip_plan` with no clearance at all.

So the topper sits with its slant flush on the holder's and its rear over the
holder's lips. That is a face-to-face mate and it fixes the placement
completely. Allan's description — *"fits snugly on top of the card holder, with
the protrusions on the side ensuring it doesn't slide down the diagonal"* — is
that mate exactly: the diagonal is the slant, and the protrusions are the two
tabs.

**Why there is a turn at all**, in Allan's words: *"Upside down is necessary
for it to print properly, so the flat side with the names is face-down. It is
used face-up when in use. This is a common pattern."* So the modelled
orientation is the PRINT one, and `Upside Down` in the feature tree is what
puts it there. The assembly turns it back.

The placement is that half turn about **X**, about the plane `z =
topper.Z_BASE`, and `-2 * depth` in Y:

* **X** unchanged. `topper.width` is `calSlotwidth * HorizontalSlots` — the
  holder less its two end blocks — and the part's X origin is the first slot's
  centre, "exactly as the Holder's is".
* **Y** the drawn part runs `-2*depth .. -depth`; the turn maps that onto the
  holder's own `-depth .. 0`, putting the rear wall over the rear lips.
* **Z** `2 * topper.Z_BASE`, so the turn is about the base plane itself.

And the slant lands: the topper's slant meets the holder's at **0.000000** on
all four Innovation parameter sets, at BOTH ends of it — rear and front,
across slopes from 1.4977 to 3.1538.

### Three wrong answers before that one

Worth recording, because they are all the same mistake:

1. the topper read as sitting where it was drawn, one holder depth forward;
2. then FITTED, by resting its label face on the card tops — 0.100 out;
3. then fitted again, by resting the plate's underside on them — 1.300 out.

The part does not rest on the cards at all. Each attempt inferred a placement
from measurements when a CONSTRUCTION already determined it, which is the
lesson `spec/LID.md` records under "What the fit got wrong", made three more
times. The tell was available throughout: `topper.slant_slope` delegates to
`holder.slant_slope` rather than transcribing it, and a part that borrows
another's slope is a part that mates to its face.

It is also the case for reading a neighbouring module before deriving anything:
`cad/parts/topper.py` and `spec/TOPPER.md` landed on `main` while this branch
was fitting the same placement by hand, and they state the answer in a
sentence.

## The finding: the treads sit 0.150 forward of the ribs

Three things have to agree in Y, and two of them are a sliding fit:

* the Box's slider **ribs**, `SLIDER_W` 1.500;
* the Holder's **side slot**, `SLOT_W` 1.900, so the rib has 0.400 of play in
  it and the holder 0.200 either way from centred;
* the Pusher's **tread**, `calSliderDistance` long against a holder
  `calSliderDistance - 0.400` deep, so another 0.400 of play.

They do not agree. With the pusher centred in its lid socket, a tread's centre
lands **0.150 forward** of its rib's, and

    rib centre   = BD/2 - WallThickness - SLIDER_W/2 - sd/2
    tread centre = BD/2 - 2.500 - sd/2

so the difference is `2.500 - (1.600 + 0.750)` — a **constant**, with every
parameter cancelling. It is the same 0.150 on every cascade in the catalogue.

Nothing is broken by it: the holder is still fully supported. But it eats
0.150 of the 0.400 the tread has, so a holder centred on its rib sits with
**0.350 at the front of its tread and 0.050 at the back**, and 0.050 is the
tightest number anywhere in a cascade.

The holder is left centred on its **rib** in both states rather than split
between the two datums, because the rib is the datum that exists in both, and
the design's own claim is that the holders ride the same ribs whether the
cascade is open or shut. Re-datuming the pusher to close the 0.150 is a change
to the Lid's socket placement — `SOCKET_BACK` — and that is a geometry change
with its own cost, not a placement decision.

## Where the parts come from

| part | source |
|---|---|
| Box, Lid, Pusher, TokenHolder, Holder | `cad.build`'s, from `build/` — built on the spot where missing; `cad.fit` also builds the lock parts as B-reps |
| Topper | cached `individual/Innovation/Topper *.3mf` — `cad/parts/topper.py` builds all six, but the assembly has not been moved onto them |

The Holder came from `individual/` until 2026-09-11, when Allan retired the
cached Onshape holders from the assembly. Taking `cad.build`'s puts the holder
the released cascades print under the fit test — at 7.1, the stouter lattice —
and it assembles the two `M6.21.10-12` cascades, whose first-riser holder
Onshape never exported and which used to be skipped.

## What the fit test measures

Per pair of placed parts:

* **Interference** — exact B-rep common volume where both sides are source,
  which covers Box/Lid/Pusher/TokenHolder, i.e. every surface of the lock.
  The Holder is not intersected; its mates are the margins below, measured off
  its built mesh. Any non-zero volume is a failure.
* **Margin** — minimum distance on each *named* mate, reported against what the
  standard says it should be:

  | mate | expected |
  |---|---|
  | plate in lid channel | 0.300 |
  | tab in box rim cutout | ±0.350 |
  | tab in lid recess | ±0.100 |
  | plate in box slot band | 0.200 |
  | holder in box, each side | 0.650 |
  | box in lid, each side | 0.700 (width), 0.400 total (depth) |
  | holder gap, front to back | `CardHolderGap` 0.400 |
  | pusher catch below a hung pusher | 0.500 |

  A margin outside its band is a warning with its number, not a pass.

`tests/test_assembly.py` asserts the table over the whole catalogue, the way
`test_lid_corpus.py` asserts the Lid's rules over all 48 cached lids. A margin
that holds on one cascade and not on 50 is the finding worth having.

## Output

* `build/assemblies/<Game>/<model> <state>.3mf` — gitignored and disposable,
  like the rest of `build/`. Written in the shape Onshape's `_raw` assemblies
  have: one `<object>` per distinct component and one carrying `<components>`
  with the transforms, so eight holders cost one mesh and Studio reads it.
  `mesh3mf` grows a `write_assembly`/`read_assembly` pair for it.
* `tmp/render/…` — the PNGs, also disposable.

## Renders

`cad/render.py` grows what an assembly needs and keeps what it has:

* an RGB buffer and a colour per part, instead of one grey Lambert;
* a scene of several meshes sharing one z-buffer;
* named cameras — `front`, `back`, `left`, `top`, `bottom`, plus one
  perspective hero shot, which needs a real perspective divide (the renderer is
  orthographic today);
* `--assembly` as the shorthand, beside the existing `--box`.

## Order of work

1. `mesh3mf` assembly writer/reader, and `cad/assembly.py` with the **closed,
   no lid** state for Dominion `S4.16.10`. Look at it.
2. The Lid, both states — bump into groove, box into lid.
3. The open/cascaded state.
4. `cad/fit.py` and `tests/test_assembly.py`.
5. The renderer: colour, the six views, the perspective.
6. Generalise to the four representatives — a Dominion Mat row (TokenHolder and
   Half), Innovation, Compile (spanning holders), FCM — with `--game`/`--model`
   for any other and `--all` in the background.

## Cards, for looking at

`assembly.card_fill` / `card_stack` place a stack of cards in every slot,
front pockets included, for `cad.assemble --cards` — render-only, written to
their own `<model> <state> cards.3mf`, never a part. `spec/RENDER.md`, "Cards
in the slots", has the fill rule and the colours. Their one geometric claim is
where a stack stands: on the holder's pocket floor (`pocket_z` less
`FLOOR_DROP`, 1.800 above the base) against the pocket's back wall, and on the
box floor against the front wall in the front pocket — card top 95.800 on a
sleeved cascade, the number the lid's sockets clear by 4.200.

## Open, and what settles each

* ~~Which way the pusher's depth axis runs in storage.~~ Not open: two axes are
  forced by features and the third by right-handedness.
* **Which lid mark is the reference, and which three turn.** REOPENED
  2026-09-11. Settled 2026-09-04 as "the three were the reference, Dominion's
  DXF turned", on the Innovation photo of three closed boxes; unsettled when
  a printed Dominion lid with the turned DXF came out upside down and the
  turn was undone. The rest of this entry is kept as it was written. Parked (Allan,
  2026-09-03 — away from the printed boxes). Nothing geometric in the lid
  distinguishes the two ways it closes, so the physical product is the only
  authority: look at a closed box, and whichever game reads upright is the
  reference. The placement stays on the **Y** turn meanwhile, which leaves
  Dominion upside down and Compile, FCM and Innovation upright.

  When it is settled the fix is a 180° rotation of one DXF or of three, and it
  is **geometry-neutral**: the mark is sized and placed from its bounding box
  (`logo_scale`, `logo_offset`), and a half turn preserves that exactly — same
  size, same position, same fit. Cost is a wash either way: Dominion is 24 of
  the 50 lids, the other three games 26 between them.

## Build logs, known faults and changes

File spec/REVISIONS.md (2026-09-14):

# Revisions — the release line, and what changed at each one

`cad/revisions.py` is the code; this is the record. It answers one question:
**what does a cascade built at 7.0 have that one built at 7.1 does not, and
why?**

## A REVISION CHANGE is not a DIVERGENCE

The distinction is the whole point of the mechanism, and getting it wrong is
what the mechanism prevents.

| | DIVERGENCE | REVISION CHANGE |
|---|---|---|
| what it is | `cad/` against **Onshape**, at the same version | `cad/` 7.0 against `cad/` 7.1 |
| how long | permanent | from its release on |
| lives in | the part, recorded in `spec/` | `cad/revisions.py`, recorded here |
| asserted by | the part's own test, both ends (`cad/README.md`, decision 6) | `tests/test_revisions.py`, both releases |

The four standing DIVERGENCES are the Box's hanging holes stopping at the slot
band, its `CC` where the sketch says `Rev`, the XS box's single fastener, and
the Lid's fitted logo. They apply at 7.0 and 7.1 alike and they are NOT in the
revisions table — putting them there would make the table read as a mixed bag
of switches instead of a release history. That was asked and settled (Allan,
2026-09-06).

## A version is a STRING

Short, usually numeric-looking — `7.0`, `7.1` — but it may be `7.1a`, `7.1.1`
or anything else that fits on a part, so nothing parses it (Allan,
2026-09-06). The iteration letter below is the first version on the line that
is not a number at all, and nothing had to change to admit it: it is a member
of `RELEASES` like any other string. A release's ORDER is its position in `RELEASES`, which is the only
place the line's order is stated, and `HISTORICAL` names the older versions
still asked about by name (`6.6`, which `tests/test_holder_corpus.py` prices
its engraving at). Anything else is refused: with opaque strings there is no
arithmetic that tells a real old release from a typo, so the answer is a list.

One consequence to know before choosing a version: the engraved-stamp reader
can only read a `digit . digit` word (`verify._dotted`), so a version of any
other shape — `7.1.1`, `7.1B` — is checkable by its METADATA alone. That is a
limit on the reader, not on the version, and it is why the metadata witness
exists at all.

## The two rules that keep it generalisable

**A part asks a NAMED question and never compares versions.** `d.rev.<flag>`,
never `d.Version >= "7.1"`. The flag name is what this file records and what a
reader greps for; a version comparison is invisible to both. Adding the next
change is one field in `revisions.Rev`, one `if` in the part, and one case in
`tests/test_revisions.py`.

**The line is monotonic.** A change introduced at 7.1 is in every release after
it — that is what a release line means. Undoing one later is a NEW flag with
its own `since`, not a hole in the table.

## How a release reaches a part

`Primary.Version` -> `derive` -> `d.rev`, a frozen record of one boolean per
change, riding on the `Derived`. That keeps the rule the rebuild already has:
every feature below `derive` takes the `Derived` alone. `rev` is deliberately
NOT one of the studio's variables — Onshape has no counterpart for it — so it
is a slot on `Derived` beside `_v` rather than a key inside it.

## The releases

### 7.0 — the Onshape generation

What every reference STEP in `spec/reference/` and every cached mesh in
`individual/` was exported at, and what every shipped cascade under
`cascades/` is. A 7.0 build must reproduce them exactly, forever; that is what
the corpus tests assert, and `tests/reference.py` is why they keep asserting it
when the default moves.

### 7.1 — the cad-built release, LOCKED 2026-09-10

On the line as plain **`7.1`**, at the END of it, and `CURRENT`. That is what
the lock means here: the line is ordered and a flag is on from its `since`
onward, so the last release carries every change the letters introduced — `7.1`
is `7.1d`'s geometry under a `CC 7.1` stamp, and its six flags are all six
below.

`7.1a` .. `7.1d` STAY on the line, unrenamed, each still only the flags at or
before its own letter. They are what the release was built as while it was
being worked on, and a version that has been built has to remain describable
and buildable. Not one flag's `since` moved at the lock either: they still name
the letter each change shipped in, which is what the letters are for and what
`tests/test_revisions.py` isolates them by.

**The first letter after the lock is `7.2a`** (2026-09-11), not `7.1e`: `7.1`
is on the line, so a change after it is a change after the release. `7.2a` is
below, with `rear_holder`, `7.2b` after it with `unmarked_lid`, `7.2c` after
that with `larger_lid_text`, and `7.2d` after that — open, with
`plain_box_plate`.

The same 7.0 **lock** (`lock.SAME_LOCK`, and `pusher.build` refuses a release
that has not declared one) under a `CC 7.1` stamp, so a cad-built cascade can
be told from an Onshape-exported one on the shelf — and, since the version goes
into the project name and title, in the file too.

Its geometry changes, in the order they were made:

* **`lid_socket_per_pusher`** — the Lid cuts one pusher socket per pusher the
  cascade ships (`box.pusher_slot_count`) instead of Onshape's plain size rule,
  so the four Innovation M lids lose their unused MIDDLE socket. Four lids and
  no others; the outer pair does not move, so no pusher and no margin changes.
  `spec/LID.md`, "The middle socket is gone".
* **`two_pushers`** — every cascade takes TWO pushers, whatever its size, where
  Onshape gave 3 to every M and L box that is not Innovation. It restates 24 of
  the 50 boxes — one fewer rear storage slot, divider and pair of rim cutouts —
  moves their thumb cutout, and ships one Pusher fewer in each of their
  projects. The Lid follows through the flag above, so nothing has three
  sockets at 7.1. `spec/BOX.md`, "Two pusher slots, at every size".
* **`thick_floor`** — the Box's floor is `2.000` where every wall stays
  `WallThickness`'s `1.600` (Allan). It is the two SIDE FLOORS that matter: the
  card area is cut clean through (`bottom_slot`), so what the floor actually is
  is the pair of strips the holders rest on, plus the front pocket's and the
  rear storage's. It grows **upward**, into the cavity, so nothing about the
  box's outside changes — same bounding box, same rim, same rim cutouts, same
  `Top of back`, same hanging holes, all of them measured from the bed — and
  the `0.400` comes out of the interior, which has `12.900` of headroom over
  the tallest holder on all 50 rows. Everything standing on the floor rises
  with it by exactly `0.400`: every holder and the token holder. The Lid keeps
  its `1.600` floor. `spec/BOX.md`, "The floor is 2.000, and it grows UPWARD".

The first three are `7.1a`. `7.1b` adds one:

* **`rear_thumbs_spread`** (`7.1b`) — the back pocket gets as many
  `Thumb Cutout in back`s as it takes to put one every `70.000` along it,
  spread evenly and centred on the pocket (Allan). Before it there is exactly
  one however wide the pocket is, and the pocket is `45.3` to `290.5` mm wide
  — `two_pushers` having just widened 24 of them by a whole slot pitch. The
  pitch is a CEILING and not a target: the gap cut is the largest one no wider
  than `70.000`, `34.90 .. 69.15` across the catalogue, and the outer pair
  keep `10.000` of wall at each end. `#calFingerHoleOffset` stops placing the
  cutout — the pocket does — so `box.rear_thumb_x` is now 7.0's and 7.1a's
  answer alone. It costs the outer back ledge its place in `sharp_edges`,
  which is a kernel limit and no geometry. `spec/BOX.md`, "A thumb cutout
  every 70 mm of back pocket".

And `7.1c` adds a fifth, the only one that reaches TWO parts at once:

* **`stout_lattice`** (`7.1c`) — the lattice window is `9.000` wide rather
  than `10.000` and there are FOUR rows of them where there were three, in the
  Box's `Hanging holes` and the Holder's `Vertical slits in holder` alike (and
  in the front pocket's slits, which are the same openings). The PITCH does
  not move and neither does the row band, so every `1.000` the window gives up
  is `1.000` the pillar between two windows gains, and four rows divide
  `HOLE_ROW_BOTTOM..HOLE_ROW_TOP` where three did. Both halves are for the
  PILLARS, which break: the Holder's is `1.800 x 0.800` at `calSlotwidth 63`
  and stands `18.167` free, and in every layer inside a window row it is an
  ISLAND — four per compartment per wall, each a free cantilever the nozzle
  brushes and the bridge above pulls on as it cools. It snaps at its base
  mid-print and is then captured by that bridge, which is why a broken one is
  found hanging from it (Allan, 2026-09-09, with the print to show it). `9.000`
  hands the mullion the whole `1.000` — `+56%` of section at `63` — and the
  fourth row cuts the free run to `13.125`, a tip deflection of `0.24x`.
  **Filleting the window corners was tried first, on real prints, and is
  WORSE**: a fillet at a window's TOP corner turns a clean short bridge into a
  progressively worsening overhang, and the sides stop running vertical. The
  constraint this change respects, and the reason it is a width and a count
  and not a shape, is **sides vertical, top horizontal**. `spec/BOX.md` and
  `spec/HOLDER.md`, "A stouter lattice".

And `7.1d` adds a sixth, the only one that changes no geometry at all:

* **`both_lid_editions`** (`7.1d`) — a cascade that carries a NON-DEFAULT
  edition of its game's mark ships the default edition too, as a second Lid on
  a plate of its own (Allan, 2026-09-10: "I need to include two lids on
  separate plates: one with the Innovation Ultimate logo, and one with the
  plain Innovation logo"). That is Innovation's two single-set cascades and so
  four projects — `S3.15.10` and `XS5.15.10`, sleeved and unsleeved — each of
  which keeps the plain `Innovation` lid it already carried and gains an
  `Innovation Ultimate` one beside it, for its owner to choose between at the
  printer. The rule is stated once, as a rule and not a table
  (`tables.lid_editions`): the edition the cascade carries, then the game's
  default where the two differ. Nothing a lid IS changes — the alternate is
  the same lid with the other mark in its underside, fitted by the same rule —
  so this is a change to what a project CONTAINS, which `two_pushers` already
  was in its second half. The alternate takes the edition's word as a suffix
  (`Lid S3.15.10.20-Un Ultimate.3mf`, object `Lid 135U Ultimate`) and the two
  plates are named after their objects, because "Lid 1 of 2" would not say
  which mark is on it. `spec/LID.md`, "Both editions ship, on a plate each".

**The flags are separable and the tests keep them so.** Two of the four reach
the Lid, so comparing 7.0 with 7.1 shows 28 lids changing and says nothing about
which flag did what; `tests/test_revisions.py` turns one flag on at a time
against a 7.0 Derived to isolate them. `thick_floor` needs the same treatment
for a different reason: `two_pushers` restates 24 boxes wholesale, so only a
7.0 Derived carrying the floor flag ALONE — same three slots, same `CC 7.0` ink
— can show that the floor moved and nothing else did. `rear_thumbs_spread` is
isolated the same way, and for a third reason: at 7.0 the pocket is a slot
pitch narrower, so the row it lays down there is not the row it lays down at
7.1b, and only the flag alone can price a cutout. That technique is the
reason a `Rev` is a record of independent booleans rather than a version number
to compare against.

### 7.2a — opened 2026-09-11, frozen 2026-09-13

`cascades/` stays the 7.1 release until the 8.0 lock (made as `7.2`, and
renamed: see "8.0 — LOCKED 2026-09-14"). One flag:

* **`rear_holder`** (`7.2a`, 2026-09-13) — every cascade's rearmost holder is
  a **`RearHolder`**: the same holder without its rear lips. The lips hook
  the holder behind, and behind the rearmost there is only the box's back
  wall, 0.950 away; a shallow slant's lips reach past it (0.3–0.4 mm of
  interference on Dominion's 8- and 9-riser cascades, 0.65 on a deep holder
  at the back — measured by intersecting the placed holder with the box,
  `spec/HOLDER.md`, "The RearHolder"). It replaces one plain Holder in every
  project, and where the row puts the deep slot at the BACK it replaces the
  FirstHolder, keeping that holder's depth and slant under the RearHolder
  name (`holder.build(..., rear=True)`, `assembly.rear_of`,
  `assembly.holder_kinds`, `build.holder_file`). The plain and first holders
  are byte-identical to 7.1's. Allan: generalised from the Three Expansions
  print, where the rear holder was the first to be built without lips.

**Opened for a flag that was withdrawn.** `low_profile` (2026-09-11) made
`S3.15.10.32-Sl` a 100 box with a 35 lid and a 3 mm, 3.2-wide, 12.2-wide
flared lid socket, so the closed single-set cascade lost 5 mm. Allan printed it
and withdrew it on 2026-09-13: the Innovation game box is 76 mm inside and
holds its cards flat, so a standing cascade lifts its lid whatever its height,
and 5 mm of lift was not worth a lid and box that only fit each other. The
flag and everything it gated are gone from the tree; the analysis that went
with it is kept here in one paragraph, because it is easy to get wrong again:
the label holder is NOT what stops a box being shorter (the closed lid's rim
sits at 66.6 to cover the front cutout, which the front-pocket cards set, so a
lid shrinks with its box), and slider engagement is not either (the design's
floor is 18 mm of rib, `(BoxHeight - 18) / RisingSliders`); what is, is the
lid's pusher sockets hanging 5 mm from its floor dead over the first and last
card compartments, 4.2 mm above a standing sleeved card. A shorter box is a
shorter socket, and a 3 mm socket wants a 3.2 channel and a wider, flared
block. `cad.fit` keeps the two margins that came out of it: "socket underside
over the card top" and "over the tallest holder".

**What 7.2a carries instead** — none of it a flag, all of it a ROW:

* the `Three Expansions` row, `M8.16.10-16`: four columns, eight 10-card
  risers, a 16-card first riser and front pocket, so 36 slots for three
  Innovation expansions of twelve sets each; two of them lie on their backs in
  the game box (286.9 along the 288, two closed heights along the 263, 74.1
  deep as the height unsleeved; 99.6 sleeved, which lifts the lid 23.6). Its
  card sets are placed by `assembly.card_fill` and drawn by `cad.assemble
  --cards` (`spec/RENDER.md`);
* three row options in parts.csv, each a `Primary` field and a `derive`
  variable, read by parts on that row alone: **`Deep slot` = back** (the deep
  first-riser slot at the back: `box.slider_ribs`, `pusher.slider_drops`,
  `box.lip_slope`, `assembly.holder_rib`, and the holder itself —
  `holder.deep_at_back`: no rear lips, the plain slant with a taller rear,
  `spec/HOLDER.md`); **`Sleeved card width`** (64 on this row, so the sleeved
  twin is as wide as the unsleeved); **`Toppers` = none** (the row's toppers
  would share Onshape's cache name with `M5.10.10`'s at a different slant,
  `build.ships_toppers`).

A row option is not a release change: no existing part moves, so there is no
flag for it and nothing for `tests/test_revisions.py` to assert at two ends —
except the one thing the new row DID change about an existing case, the
`lid_socket_per_pusher` set, which now names six Innovation M lids.

### 7.2b — opened and frozen 2026-09-13

One flag:

* **`unmarked_lid`** (`7.2b`, 2026-09-13) — every cascade ships a SECOND lid
  on a plate of its own, with **no mark in its underside** and **`(C)
  Mertner`** embossed where the game's name is on the lid the cascade carries
  (Allan: "a separate plate with a lid that has no logo on it, and where the
  game name embossed inside that lid is replaced"). Everything else on it is
  the cascade's own lid's — the capacity and model lines, the `Card Cascade`
  block with its version and staircase, the sockets, the grooves, the rounds
  — so it is one body in the second filament's absence, where the own lid is
  a body and its inlays. Like `both_lid_editions` a change to what a project
  CONTAINS: no existing lid moves, Innovation's two single-set cascades ship
  three lids, every other cascade two, and from here no project has a plate
  called just `Lid` (`layout.PLATE_SCHEME`'s `alt` names every lid plate
  after its object: `Lid 168U`, `Lid 168U Unmarked`).

  A lid is now one of three **variants** — `tables.LID_VARIANTS`: `LID_OWN`,
  `LID_ALTERNATE` (7.1d) and `LID_UNMARKED` — where it was a bool, and every
  name follows the alternate's suffix rule: `Lid S4.16.10.32-Un Unmarked.3mf`,
  object `Lid 168U Unmarked` (`tables.LID_UNMARKED_NAME`). `build.lid_variants_built`
  is the only place the two flags are asked; the part builds any variant at
  any release.

  **Why "(C) Mertner" and not "(C) Allan Mertner".** The full line was
  measured first: 45.6 wide at the game line's 3.5 cap, and right-aligned on
  the game line's edge it crosses a pusher socket on both XS lids (where the
  text block sits beside the sockets) and the staircase's top step on five
  3-slot S lids. Allan chose the short form everywhere rather than a per-lid
  fit (2026-09-13): 30.1 wide, and at least 12.4 clear of the logo block and
  every socket on all 52 lids at full size, which `tests/test_revisions.py`
  measures on the text solids. `(C)` is spelled out because Orbitron Bold
  has no `©`. `lid.CREDIT`, `spec/LID.md` "An unmarked lid, on a plate of
  its own".

### 7.2c — 2026-09-13

One flag:

* **`larger_lid_text`** (`7.2c`, 2026-09-13) — the Lid's three-line text
  block (capacity, game name or credit, model) is **scaled up where the lid
  has room** (Allan: "a bit larger when space permits ... easier to read and
  nicer on larger cascades. Do not simply expand to use all space as that
  would be too large sometimes"). Before the flag the block is the same
  3.5/3.5/3.0 cap, ~35 x 14 mm, on every lid, while the room beside it runs
  from ~10 mm on an S lid to ~140 on an L. From it, ONE factor per cascade
  scales every cap and gap — `lid.text_scale`, anchored at the block's cap
  top and right edge (`text_anchor`, which do not move), growing left and
  down until the ink is `LINE_GAP` from what is to its left (the Card Cascade
  block's right edge; on an XS lid, where the block sits beside the sockets,
  the left socket) or keeps at the front wall what it keeps at the back
  (`FootDistanceFromWall + 2`), and **never past `TEXT_SCALE_MAX` = 1.5**
  (Allan's, from 1.3 / 1.5 / 1.75: lines 5.25 cap, the model line 4.5).
  Measured: 26 of the 30 M and L lids reach 1.5, and the four that do not
  are the shallow ones, bound by depth — `L3.18.6.20-Un` (35.0 deep) stays
  at 1.0, `M5.6.6.20-Un` (39.8) comes to 1.27, `L5.7.7.20-Un` and
  `L3.18.6.20-Sl` (42.9) to 1.49 — the S lids come to 1.0-1.37 against the
  Card Cascade block (the
  two `S2.40.12-30` rows ~1.0, their model line being 44 mm), and XS to
  1.07-1.18. The width is the widest of all FOUR lines a cascade's lids can
  carry, so its own and unmarked lids share the scale. The Card Cascade
  block, its version and the staircase do not scale: they are already sized
  to the slot width (Allan, 2026-09-13). `spec/LID.md`, "The text block
  grows with the lid".

### 7.2d — 2026-09-13

One flag:

* **`plain_box_plate`** (`7.2d`, 2026-09-13) — a cascade whose parts.csv
  row sets **`Plain box`** ships a SECOND box on a plate of its own, at the
  END of the project: the same box built without its front and side label
  holders, for an owner who wants no label on the shelf (Allan: Compile's
  three rows, so six projects). The geometry is the `Label holders` option's
  (`isLabelHoldersOnBox = 0`, in the catalogue since 2026-09-05 and held to
  a reference STEP by `tests/test_box.py`); what is new is that a project
  CARRIES it, as `unmarked_lid` carries a second lid — no box moves, the
  ordinary one stays on plate 1 with its pushers, and the plain one is an
  alternative to it, printed instead of it. `build.plain_box_twin` is the
  cascade's own Derived re-derived with `LabelHolders` 0, so its file is
  `box_file`'s `Box <model> no label holders.3mf` and `build_box` needs no
  variant; `build.ships_plain_box` is the ONLY place the flag is asked, and
  the column is a row property the way `TokenHolder` and `Toppers` are. The
  object is a `PlainBox` — a role of its own, because `layout.role` matches
  a prefix and `Box ...` would seat it with the pushers — on the last
  `layout.PLATE_SCHEME` plate, `Box without label holders`. A row whose own
  box already has no holders is refused a twin. `spec/BOX.md`, "A plain box
  on a plate of its own".

### 7.2e — 2026-09-13

One flag:

* **`seated_lips`** (`7.2e`, 2026-09-13) — every lip seats in the rest of
  the part behind it when the cascade is open, and reaches no further
  (Allan, off flat cascades whose lips were "a bit too long": they should
  overlap the holder behind, fit into the indent there, and no more). The
  review found three unrelated formulas doing that job — the lip's reach
  (`2.100` ALONG the slant, `0.38` to `1.81` in Y), the rest's start
  (`2 * calSlotDepth` along the slant, leaving 333 Sl a `0.332` notch and
  246 Sl none) and the slant itself (`(inc-1)/(sd-1.2)`, which puts a lip
  `0.4` to `5.5` above the notch it should sit in) — and measured the
  result on the placed B-reps: 246 Sl's holder lands on the one behind by
  134 mm³, 333 Sl's by 46, M8.16 Sl's by 35, and the Box's lip, `1.250`
  from its holder, reaches only six front holders and meets the wall under
  the notch on each. One rule replaces them: the slant is the cascade's own
  diagonal, `calHeightIncrement / sliderDistance` (`derive.cascade_slope`,
  so the Box's lip angle and the Topper's slant follow), a lip reaches the
  gap plus one wall in Y (`1.200` for a holder's, `2.050` for the box's),
  and the rest is notched through the whole front wall, the lip's base plus
  `REST_CLEARANCE` (`0.200`) a side and `rest_depth` deep — the lip band plus
  the clearance, or deeper where the box lip, fixed at `85.500`, needs it
  (`assembly.box_lip_seat`). The deep holder at the back continues the plain
  diagonal exactly. Slopes move a few degrees on steep rows and hardly at all
  on flat ones. `cad.fit` builds and intersects every holder from here, and
  `lip_margins` reports each lip's seat. `spec/HOLDER.md`, "Lips that seat".

### 7.2f — 2026-09-14, a PROTOTYPE

Two flags, opened to PRINT a test of them
before the catalogue moves (`cad.testkit`), so they may be revised or
withdrawn as 7.2a's `low_profile` was:

* **`ribs_forward`** (`7.2f`, 2026-09-14) — Allan, on the 7.2e box lip: it
  should not have further to go than a holder's. The studio's `#BoxDepth`
  leaves 1.800 of unused space between the last card slot and the divider
  panel, so the box lip crossed 1.250 where a holder's lips cross 0.400.
  Every slider rib — and so every holder — moves FORWARD by `box.rib_shift`
  (derived, 0.850 on every row) so the front holder is `CardHolderGap` from
  the panel. The box lip becomes a FLAT block that BITES that wall by
  0.150 (`box.lip_reach`, 0.550 proud) — inside the holder's 0.200 rib
  slack, so the holder still slides straight down its ribs past it, which
  7.2e's lip (0.800 into the wall) did not allow: a holder cannot pass a
  fixed lip on its way in, and `cad.fit` now sweeps the front holder onto
  its seat in the closed state to prove it — with its top on the holder's
  slant at the wall's face in play (`box.lip_z`, on a 0.800 post above the
  panel's bevel), so every rest is the plain 2.200 and every lip floats the
  same 0.200. The lid and pusher do not
  move: a holder now hangs 0.500 past the front edge of its tread instead of
  sitting 0.350 inside it (`cad.fit`'s tread margins), and the rearmost
  holder is 1.800 from the back wall instead of 0.950 — both taken up by
  `shorter_box`. Off Allan's kit A print the lip became a wedge: underside
  on the slant to a point `SLANT_STEP` under the holder's slant, front face
  straight back up to the post, flat top `LIP_SINK` 0.200 under the
  holder's slant at the wall's face. `spec/BOX.md`, "The ribs move forward",
  including what the test print is to show.
* **`shorter_box`** (`7.2f`, 2026-09-14) — Allan, off the kit A print: the
  box has a big gap at the back now; make it shallower. The box and the lid
  lose `calRearTrim` (derive.py; 1.400 on every row) so the rearmost holder
  sits CardHolderGap 0.400 from the back wall like every holder from the
  next. `box.rib_shift`, derived from the depth, comes out -0.550 so the
  ribs keep their 0.400 to the panel, and the lid's sockets follow the ribs
  (`lid.socket_back`, 8.300) so every holder is centred on its tread, 0.200
  each way. Every box and lid is 1.400 shallower, parts.csv's `D` columns
  with them; a 7.2f lid does not fit an earlier box. `spec/BOX.md`, "The
  box loses the room behind the last holder".

### 7.2g — 2026-09-14

Two flags, and neither changes a part the
catalogue already ships: both are ROW options, and one row takes them —
`Single Mini`, the only XS row, which Allan uses in PAIRS. They are gated
where `Deep slot` and `Sleeved card width` were not, and the reason is worth
stating: those arrived with `Three Expansions`, a NEW row with no corpus
behind it, whereas `Single Mini` has `individual/XS5.15.10.32-Un/` and
`spec/reference/Box Innovation 130U.step` as 7.0 ground truth. An ungated
column would restate what a 7.0 build produces, and a shipped release must
keep rebuilding to the byte.

* **`unsleeved_card_width`** (`7.2g`, 2026-09-14) — a row may state its
  UNSLEEVED cards' width outright (`Primary.UnsleevedCardWidth`, parts.csv's
  **`Unsleeved card width`**), exactly as it has been able to state its
  sleeved ones since 7.2a. `Single Mini` sets 66 — the SLEEVED width — so
  its unsleeved box grows 148.300 to 152.300 and its lid 152.900 to 156.900,
  the same as the sleeved cascade's. It reaches everything the card width
  does, through `calSlotwidth`: the slot, the box, the lid, the holders and
  the toppers. It reaches nothing else, and that is the point of doing it
  this way — `calCardThickness` stays the unsleeved 0.4, so the capacity,
  the depth and the rise do not move and the model code is still
  `XS5.15.10.32-Un`. Two things fall out: four unsleeved pushers now fit the
  back (145.600 of 149.100 inner, against 145.100 before, which is half a
  millimetre short), and the pair's two lids become interchangeable.
  `spec/BOX.md`, "The unsleeved XS box is as wide as its twin".
* **`back_pocket_variants`** (`7.2g`, 2026-09-14) — a row may ship back-pocket
  VARIANT boxes **IN PLACE OF** the ordinary one, off parts.csv's **`Back
  pocket`** column. That is where it differs from `plain_box_plate` and
  `unmarked_lid`, which ADD a plate: here the ordinary box is not shipped at
  all, because on this row it does neither of the two jobs wanted. A pair of
  `Single Mini` cascades divides the work between its halves — `open` has no
  dividers, no cavities and no rim cutouts, so the whole slot band is empty
  from the floor up and the pocket is the full inner width, 149.100, which
  takes Innovation's 128 mm player aids where the ordinary box's 71.500
  (Un) and 50.500 (Sl) do not; `notches` hangs the pair's pushers and has no
  thumb cutout, there being no pocket left to reach into. The count is
  DERIVED and never stated (`box.storage_slot_count`): as many as the width
  takes, which is 4 unsleeved and 3 sleeved, their pushers being 32.000 and
  44.500 deep. Four sleeved pushers need 178.000 of bare width before any
  clearance and fit no XS box at all; Allan's call is that the pair's fourth
  travels elsewhere. The Lid does NOT follow the variant: `calPusherSlots` is
  how many pushers the CASCADE ships and stays 2, so both boxes of the pair
  take the same lid — which is what `pusher_slot_count` and
  `storage_slot_count` are two functions for.
  `build.back_pocket_variants_built` is the ONLY place the column and the
  flag are asked and `build.back_pocket_twin` is `plain_box_twin`'s recipe on
  `BackPocket`; the first variant is the `Box` on plate 1 with the pushers,
  the second a `NotchedBox` on `layout.PLATE_SCHEME`'s `Box with pusher
  notches` — a role of its own for the reason `PlainBox` is one, and not a
  `PusherBox`, which the prefix match would seat with the pushers.
  `spec/BOX.md`, "Two back pockets, and no ordinary box".

### 8.0 — LOCKED 2026-09-14

`CURRENT`; `build/` and `cascades/` are 8.0, tagged `v8.0`. It carries no
flag of its own: it is `7.2g`'s geometry under a `CC 8.0` stamp, sitting at
the END of the line after the seven `7.2x` letters that made it, so it has
every change they introduced. Not one `since` moved, and the letters stay on
the line — `7.2a` still builds what `7.2a` built, which is what lets a part
stamped with one remain describable.

**Why the major number, and why `7.2` is not on the line.** The lock was
made as `7.2` earlier the same day and renamed to `8.0` before anything was
printed at it (Allan, 2026-09-14, at the printer): `7.2f`'s `shorter_box`
takes 1.400 of depth out of every box and lid in the catalogue, so a lid
from this release does not close a 7.1 box and a 7.1 lid does not close one
of these. A minor number claims those are interchangeable, and they are not.
Plain `7.2` names nothing that was ever built, so it is simply gone from
`RELEASES`, `lock.SAME_LOCK` and `verify.STAMP_SIGNATURES`; the letters
`7.2a`..`7.2g` stay, because parts WERE printed at them while the release
was being worked out, and the rule that binds is that a version you can hold
must remain describable and buildable. Renaming a version nothing wears
breaks nothing; renaming one a part wears would.

What changed since the 7.1 release, in the order the letters shipped it:
the rearmost holder became a `RearHolder` without rear lips (`7.2a`); every
cascade gained an unmarked lid on a plate of its own (`7.2b`); the lid's
three-line text block grew where the lid had room (`7.2c`); a row may ship a
plain box without label holders on a plate of its own (`7.2d`); every lip
seats in the rest behind it (`7.2e`); the slider ribs moved forward and the
box and lid lost the room behind the last holder, the box lip becoming a
wedge on a bevelled post (`7.2f`); and a row may state its unsleeved card
width and ship variant backs in place of the ordinary box (`7.2g`).

**An 8.0 lid does not fit a 7.1 box** — `shorter_box` took 1.400 of depth
out of both — and parts.csv's W/D columns are the 8.0 sizes. That
incompatibility is what the major number is for.

The next design change opens **`8.1a`**, not `8.0a`: `8.0` is on the line
now, so a change after it is a change after the release.

## What a release moves besides its flags

**The stamp.** Every part engraves `CC <version>`, so a 7.1 part differs from
a 7.0 one in ink even where no flag touched it — `1.44 mm3` on the Innovation M
lid, which is the `0` against the `1`. `tests/test_revisions.py` separates the
two deliberately: it prices the FLAG by building a 7.0 `Derived` carrying 7.1's
`Rev` (same ink, one socket fewer) and the STAMP as what is left. A tolerance
wide enough to swallow both would hide a second change.

**Two witnesses to the release, because one is not enough.** Reading the
engraved version back is not OCR: it is a signature over the COUNTERS of the
two digits either side of the period (`verify.STAMP_SIGNATURES`), and at 7.1
that stops being sufficient. `7` has no counter and neither has `1`, so 7.1
reads `("none", "none")` — and so would 7.2, 7.3, 7.5 and 7.7. The counters
cannot separate them and no better reader will: those glyphs differ in their
strokes, not in their holes.

So every component `cad.build` writes now STATES its release in the file as
well, as `CardCascade:Version` metadata under a declared namespace, beside a
human `Title` and `Description` Studio will show. The two witnesses answer
different questions and neither replaces the other:

| | the ENGRAVING | the METADATA |
|---|---|---|
| who can read it | anyone holding the printed part | anything reading the file |
| how exact | ambiguous from 7.1 on | exact |
| what it guards | a 7.x pusher going into a 6.6 lid | which release wrote this file |

`verify.check_stamp` holds both to the release AND to each other: a positive
mismatch from either is fatal, and so is the two disagreeing, which means the
file is not self-consistent whatever the cascade wanted. Only when NEITHER can
be read is it a warning. An Onshape export carries no metadata and is checked
by its glyph exactly as before.

`verify.py --stamps --tree build` is the release-time check: every component in
a cad tree must state one release, and the Box, Lid and Pusher must be engraved
with it too.

**The tree.** Filenames carry no version — a NAME is an identity
(`components.tracked_name`) — so two releases written to one tree overwrite
each other part for part. `cad.build --out` therefore follows `--version` by
default: `build/` for the current release, `build/v<version>/` for any other.
`cad.cascade --components` follows the same rule, and `cad.promote` reads the
LOCK GENERATION's tree, because what it stages goes into a shipped cascade
whose other parts are Onshape 7.0 exports.

## Defaults, and why the tests pin

`revisions.CURRENT` is the newest release on the line (**`8.0`** as of
2026-09-14, locked): a plain `cad.build` or `cad.cascade` builds the current release
(Allan, 2026-09-06). `cad.compare` and `tests/test_parallel.py`
are the exception that proves the rule: they pin **7.0**, because what they
regress against is the shipped tree, which the Onshape pipeline built at 7.0 —
and from 7.1 a twin is MEANT to print differently, two pushers against three. That makes the default a moving target by
design, so **every test that compares against a reference pins the release it
means** — `tests/reference.py`, `VERSION = "7.0"`, a literal and not
`revisions.CURRENT`. `tests/test_holder_corpus.py` had already been pricing its
engraving at an explicit `Version="6.6"` long before the default moved, which
is the same idea; this generalises it.

A test that does not pin is a test that re-baselines itself the next time the
default moves — the one failure a regression corpus must not have.

## An unreleased release is iterated by LETTER

`CURRENT` is not a finished thing. The way this repo is worked (Allan,
2026-09-06) is: **sit at a version for a while, accumulate changes in it, then
lock it and release it.** The letter is how those accumulating states are told
apart (Allan, 2026-09-08): **`7.1a`, `7.1b`, `7.1c`, `7.1d`, ... and then plain
`7.1` at the lock** — which happened on 2026-09-10, after four of them.

**The problem it solves is physical.** While 7.1 is being worked on its
geometry moved — five times over four letters — and every part printed that way
says `CC 7.1`. A shelf of them cannot say which is which, and the stamp is the
only thing a person holding the plastic can read. A letter makes each state
nameable on the part itself.

**A letter is a release like any other**, and that is the whole design: a full
member of `RELEASES`, with its own position on the line, its own
`lock.SAME_LOCK` entry and its own row in `verify.STAMP_SIGNATURES`. It is what
makes the letter MEAN something — a change lands as a flag whose `since` is the
NEW letter, so a build at `7.1a` keeps producing what `7.1a` always produced,
and the part stamped with it stays reproducible.

The alternative was considered and rejected: a letter as a mere build marker,
with the flags still keyed on `7.1`. It reads simpler and it is wrong — a
change would move the geometry under every earlier letter, so two different
shapes would wear the same stamp, which is the one thing the stamp exists to
prevent.

### Bumping, and locking

To bump: add the letter to `RELEASES` and to `lock.SAME_LOCK`, move `CURRENT`
onto it, give the new change's flag `since: "<the new letter>"`, and leave
every earlier flag alone — the line is monotonic, so they carry forward.
Nothing is rebuilt in place any more; the earlier letter is FROZEN, which is
what a version stamped on plastic has to be.

At the lock, plain `7.1` joins the END of the line and becomes `CURRENT`. The
letters STAY on it. Parts printed at `7.1b` exist, and the rule this repo
keeps everywhere is that a version you can hold must remain describable and
buildable; `7.1` sitting after them all carries every flag they introduced.

**`7.1` was not on the line until then**, deliberately: while the release was
unfinished, nothing could build it, stamp it or title a project with it, so
there was no way to put an unfinished `CC 7.1` on a part by accident. It went
on at the lock, on 2026-09-10, after four letters — and the same will hold for
`7.2`, which is not on the line while `7.2a` is being worked on.

**Prose in `spec/` says "from 7.1" and means the release**, not the letter —
the geometry sections were written about the release and stay true of every
letter in it. The flags' `since` is the exact answer and `cad/revisions.py` is
where to read it.

The reference corpus is the model for what a locked release looks like: 7.0 is
locked, `tests/reference.py` pins it, and a 7.0 build must reproduce
`individual/` forever.

## Adding the next release — or the next LETTER

The steps are the same for both, because a letter IS a release.

1. Add it to `RELEASES`, set `CURRENT` if it is the new default, and add it to
   `lock.SAME_LOCK` if it keeps the 7.0 lock. Leaving it out of `SAME_LOCK` is
   a loud failure (`pusher.build` refuses it) rather than a quiet wrong stamp.
2. For each change: a field in `revisions.Rev` with its `since` and `spec`, and
   an `if d.rev.<flag>` in the part.
3. A case in `tests/test_revisions.py`, asserting the old release still has the
   old behaviour. Its coverage check names any flag with no case.
4. A section here.
5. A stamp signature in `verify.STAMP_SIGNATURES`, and then
   `verify.py --stamps --tree build` before publishing. Adding the signature
   may not be enough on its own: see below.

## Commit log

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2026-07-08 cascades v6.0 (9 of 16): new boxes and lids, labels removed
    Rename cascades-5.1/ to cascades/ (the 5.1 release is preserved by the
    v5.1 tag). For 168S/U, 244S/U, 300S/U, 324S/U and 560S: replace the
    box and the two-colour lid with the new side-label-holder revisions
    (all parts matched at 0.000mm via CAD-origin fingerprints; colours,
    placements and print settings untouched), remove the label plates or,
    for 300U, the label objects sharing the lid plate, re-map remaining
    plates onto Bambu's smaller plate grid, and normalise plate names to
    '<Part> - <N> Card <Sleeving> (<full model>-<Sl|Un>)'. File names gain
    the side-label width per the v6 scheme. Remaining 7 models follow as
    their part exports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
    [CC 168U S4-16-10-32-Un.3mf, CC 168U S4.16.10.Un.3mf, CC 244S M4-21-10-45-Sl.3mf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]
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2026-07-08 cascades v6.0 (11 of 16): 246S new parts, 246U name fixes
    246S gets the new box and lid (0.000mm part matches); 246U already
    carried the v6 parts and needed only plate-name normalisation and the
    Unleeved typo fix. Both filenames drop the Windows-illegal colon and
    gain the width digit (S2-40-12-30-45-Sl / S2-40-12-30-32-Un).
    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
    [CC 246S S2-40-12-30-45-Sl.3mf, CC 246S S2-40:30-12-Sl.3mf, CC 246U S2-40-12-30-32-Un.3mf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]
2026-07-08 cascades v6.0 complete (16 of 16): 400S/U, 560U, 650S/U
    Final five models get the new boxes and lids (all parts matched at
    0.000mm), label plates removed, plates re-gridded and renamed to the
    v6 convention (also fixing 650U's Unleeved typo and the .Sl suffixes
    it carried on unsleeved plates). Token-holder fit on the 400-M front
    pocket verified against the new box geometry: identical to the
    published design (400S Full holder +0.8mm clearance).
    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
    [CC 400S M8-40-10-62-M-Sl.3mf, CC 400S M8-40-10-Sl-M.3mf, CC 400U M8-40-10-62-M-Un.3mf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]
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2026-07-11 Replace lids in 168U/168S/300U/300S with updated revisions
    All 7 lid parts per project matched by CAD-origin fingerprint at
    0.000mm centre and size delta; assembled lid external dimensions
    unchanged to the micron (207.9/213.9 x width x 40.0). Positions,
    rotations, plate names and two-colour part assignments preserved;
    only the lid meshes changed.
    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
    [CC 168U S4-16-10-32-Un.3mf, CC 300S S5-40-12-62-Sl.3mf, CC 300U S5-40-12-45-Un.3mf]
2026-07-11 Replace 246U/246S lids; loader handles Bambu re-exports
    Both lids swapped with all 7 parts matched at 0.000mm centre and size
    delta; assembled lid dimensions unchanged (207.9x50.06x40.0 and
    213.9x68.1x40.0), Lid Body stays on filament 2.
    replace_parts.py: load_replacement now also accepts Bambu Studio
    re-exports where the root model only references components in
    sub-model files - part meshes are centred and repositioned into the
    CAD frame via the upload's own source_offset values (the 246S lid
    came in this form; CAD exports keep working as before).
    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
    [CC 246S S2-40-12-30-45-Sl.3mf, CC 246U S2-40-12-30-32-Un.3mf]
2026-07-11 Replace 244U/244S and 324U/324S lids with updated revisions
    All lid parts matched at 0.000mm centre/size delta; assembled lid
    dimensions unchanged; positions, plates and colour assignments
    preserved (324U keeps its deliberate filament-3 lid body).
    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
    [CC 244S M4-21-10-45-Sl.3mf, CC 244U M4-21-10-32-Un.3mf, CC 324S M6-21-10-62-Sl.3mf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]
2026-07-11 Replace 400U/400S lids with updated revisions
    dimensions unchanged; positions, plates and colours preserved.
    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
    [CC 400S M8-40-10-62-M-Sl.3mf, CC 400U M8-40-10-62-M-Un.3mf]
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2026-07-11 Replace 650U/650S lids with updated revisions
    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
    [CC 650S L8-50-10-62-Sl.3mf, CC 650U L8-50-10-62-Un.3mf]
2026-07-11 Replace 560 lids (fixed exports); 560/650 down to 3 pushers
    - 560U/560S lids swapped: clean 7-body exports, all parts matched at
    0.000mm, assembled dimensions unchanged, colours preserved
    - One pusher removed from each of 560U/560S/650U/650S (4 -> 3): the
    updated lid design only needs 3. Shared pusher mesh retained;
    build items, assemble and plate instances kept consistent.
    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
    [CC 560S L6-40-12-62-Sl.3mf, CC 560U L6-40-12-45-Un.3mf, CC 650S L8-50-10-62-Sl.3mf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]
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2026-07-11 Auto-place wipe towers clear of plate objects
    replace_parts.py now verifies every plate's wipe tower against the
    plate's actual mesh footprints when writing a project. Detection flags
    only true body overlap (exact per-vertex test; Bambu accepts small
    gaps); a flagged tower moves to the nearest position with 5mm object
    clearance, staying on the bed and out of the P1 exclusion corner.
    Applied across the cascades: nine files had towers intruding 0.9-17mm
    into plate objects (the same defect that made MakerWorld reject 202U)
    - 202S, 244S, 324S, 400S/U, 560S/U, 650S/U now carry corrected
    positions on their box/lid/holder plates. 202U (fixed manually
    upstream) verifies clean and is untouched.
    Co-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
    [CC 244S M4-21-10-45-Sl.3mf, CC 324S M6-21-10-62-Sl.3mf, CC 400S M8-40-10-62-M-Sl.3mf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]
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2026-07-20 Add 472 Card Cascade projects (M2.60.18) and make_cascade.py
    New Bambu Studio projects for the 472-card Dominion Cascade, built from
    the CC6 component exports with the 560 Card projects as settings
    templates (H2C, same filaments and plate structure):
    - CC 472S M2-60-18-62-Sl.3mf (sleeved)
    - CC 472U M2-60-18-40-Un.3mf (unsleeved)
    Each has the usual four plates: Box + 2 Pushers, Lid (two-colour label
    parts preserved), 2x Holders, and Token Holder.
    make_cascade.py is the generator: unlike replace_parts.py (same-size
    revisions in place) it accepts components of any size, drops surplus
    duplicate instances, re-lays out every plate in centred rows clear of
    the wipe tower, and refuses on any ambi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
    [CC 472S M2-60-18-62-Sl.3mf, CC 472U M2-60-18-40-Un.3mf]
2026-07-20 472 Cascade: one 40-card + one 18-card holder, corrected model number
    The M2.60.18-40.62 model has two differently-sized holders (first for
    40 cards, second for 18), not two identical ones. Rebuild both projects
    with the Holder_2 exports and rename files/plates to the full model
    number, per-variant only in the -Sl/-Un suffix (matching the 246's
    S2.40.12-30.45 convention):
    - CC 472S M2-60-18-40-62-Sl.3mf (replaces CC 472S M2-60-18-62-Sl.3mf)
    - CC 472U M2-60-18-40-62-Un.3mf (replaces CC 472U M2-60-18-40-Un.3mf)
    make_cascade.py gains NAME#N=FILE for replacing a single instance,
    cloning the shared mesh file (fresh UUIDs) when instances diverge, and
    now drops the empty orphan sub-model files Ba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
    [CC 472S M2-60-18-40-62-Sl.3mf, CC 472S M2-60-18-62-Sl.3mf, CC 472U M2-60-18-40-62-Un.3mf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]
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2026-07-20 472U: rebuild as P1S/P1P project (fits standard 256mm printers)
    Repo convention puts standard-printer-capable models on P1S/P1P
    profiles; the 472 builds had inherited the 560's H2C profile. The
    unsleeved 472 fits a 256x256 bed with parts rotated 45 deg (box needs a
    233.8mm diagonal bounding box, lid 236.6mm, holders under 198mm), so
    rebuild it from the CC 400U P1P template: box/lid/holders placed
    diagonally like the 400U, pushers in the free corner, custom holder
    plate name kept. The sleeved 472 cannot fit even rotated (box 257.8mm,
    lid 260.6mm minimum square) and stays H2C-only, matching the 400S.
    make_cascade.py: objects too large for the bed now auto-rotate 45 deg
    and lay out as parallel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
    [CC 472U M2-60-18-40-62-Un.3mf]
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2026-08-03 Rename Innovation topper files to canonical names
    Normalise individual/Innovation/ topper filenames to the planner's scheme
    "Topper <Expansion> <Un|Sl>.3mf" (no size prefix — toppers are size-
    independent). Fixes inconsistent/noisy names: Art/Arti -> Artifacts,
    Fig -> Figures, unseen -> Unseen.
    [Topper Artifacts Sl.3mf, Topper Artifacts Un.3mf, Topper Blank Sl.3mf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]
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2026-08-04 Move automation pipeline + assembly scripts into automation/
    Declutter the repo root: the Onshape export automation (plan_exports.py,
    components.py, onshape_test.py, parts.csv, onshape_api_log.csv, PIPELINE.md)
    and the cascade-assembly scripts (make_cascade.py, replace_parts.py) now live
    under automation/. Data dirs individual/ and cascades/, plus the label tooling
    (labelmaker.py, figma_export.py, make_label_covers.py) and their configs,
    stay in root.
    plan_exports.py gains ROOT = HERE.parent and resolves individual/ against the
    repo root (it moved but the data dir did not); its parts.csv/manifest.json
    default to the automation/ dir alongside it. All scripts verified to run from
    the new loca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
    [onshape_api_log.csv, parts.csv]
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2026-08-04 Prove full topper export chain end-to-end; fix grouping + encode bugs
    Live-validated the whole pipeline on Topper Cities M-Un (a genuinely needed
    component): set Primary (360 Card Un) -> encode config Expansion=Cities ->
    export 3MF -> strip imports -> load_export -> store + provenance. Output matches
    the S-Un reference (Topper + 8 letter parts, colours preserved, no Holder).
    Two bugs found and fixed in the shared recipe:
    - configurationencodings is POST /api/elements/d/{did}/e/{eid}/... (NO /w/);
    the /w/ path 404s.
    - grouping must be TRUE to get one combined 3MF; grouping=false splits the
    export into one file per part (which broke consumption).
    mesh.py gains unwrap() for the (grouping=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
    [Innovation.csv, Topper Cities M-Un.3mf, onshape_api_log.csv]
2026-08-04 Wire export.py --execute; validate first structural export (Box M-Un)
    --execute performs the plan: per batch set Primary, then export each new
    component's whole part studio as one combined 3MF (grouping=true), strip
    imported parts, validate via load_export, write file + provenance. Adds
    --sleeving un|sl and --limit N to spend incrementally; toppers encode their
    config locally (parameterId=value), skipping configurationencodings.
    Validated live: Box M5.15.15.45-Un exported as a clean single-object 3MF
    (1 body, colour preserved). Ledger 32/2500. plan_exports carries the row for
    build_primary.
    [Box M5.15.15.45-Un.3mf, Innovation.csv, onshape_api_log.csv]
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2026-08-06 Fix: Innovation holders span box width (were reused S-holder in M box)
    Innovation holders span HorizontalSlots (3 wide=S, 4=M), like Compile's — not
    per-slot as previously modelled. So the M cascade needs its own wider holder,
    which the planner never exported (it thought the S holder covered it).
    - components.py: Innovation holder_spans=True.
    - Rename Holder 15-Un/Sl -> Holder 3x15-Un/Sl (the 3-wide S holders); update
    provenance.
    - Export Holder 4x15-Un (the M holder, 278mm vs 211mm) — 4 calls, ledger 55/2500.
    - Rebuild Innovation 360 Card Unsleeved with the correct holder.
    [Holder 3x15-Sl.3mf, Holder 3x15-Un.3mf, Holder 4x15-Un.3mf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]
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2026-08-07 make_cascade: drop excess parts + wipe-tower clearance
    - --part now accepts a component with FEWER parts than the template object
    (a simplified CAD, e.g. the rationalised Innovation lid): drop the excess
    parts, allowed only when they share one extruder so no colour changes.
    - Wipe towers relocate with 15mm clearance to the emptiest corner (furthest
    from the centred parts) instead of the nearest 5mm-gap spot.
    [Box M5.15.15.62-Sl.3mf, Holder 4x15-Sl.3mf, Innovation.csv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]
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2026-08-07 Toppers v6.4 (logo); teach make_cascade to add gained parts; rebuild 360-Sl
    The v6.4 topper upgrade adds a mini expansion logo to every topper except
    Blank. The logo is a new body that renumbered the letter bodies, so each
    non-Blank topper now has one more body than the v6.3 template slot count.
    - onshape_config: VERSIONS[Topper] 6.3 -> 6.4.
    - plan_exports: exempt the Blank topper (no logo) so it stays 6.3.
    - export: --name filter to target a single cascade by short name, so the
    360-Sl re-export doesn't also touch the stale 270-Sl set.
    - make_cascade: when a component GAINED bodies vs the template, append a part
    per surplus body at the object's default extruder (accent) instead of
    ref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
    [Innovation 360 Card Sleeved (M5.15.15.62-Sl).3mf, Innovation.csv, Topper Artifacts M-Sl.3mf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]
2026-08-07 Refresh 270-Un, 270-Sl, 360-Un to v6.4 (logo toppers + rationalised lids)
    Completes the v6.4 rollout across all Innovation cascades (360-Sl already done).
    - Re-exported 12 toppers (Cities/Echoes/Figures/Unseen in S-Un/S-Sl/M-Un) and
    the 3 rationalised lids (49 API calls, 150/2500). Artifacts variants were
    already refreshed; Blank stays 6.3 (no logo).
    - Rebuilt each cascade from its committed .3mf, swapping the 5 non-Blank toppers
    + lid via --auto-plates. The add-parts path handles each topper's new logo
    body; every topper is one base part (extruder 1) + letters/logo (extruder 2).
    - The 270-Un/270-Sl cascades move from their hand-packed 2-plate layout to the
    standard 4-plate scheme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
    [Innovation 270 Card Sleeved (S5.15.15.45-Sl).3mf, Innovation 270 Card Unsleeved (S5.15.15.45-Un).3mf, Innovation 360 Card Unsleeved (M5.15.15.45-Un).3mf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]
2026-08-07 Add assembly-export path: one API call per cascade for monochrome parts
    assembly_split.py splits ONE assembly 3MF export (onshape_config.ASSEMBLY) into
    the individual Box/Pusher/Holder(s)/TokenHolder component files the pipeline
    consumes, so a cascade's monochrome parts cost one translation call instead of
    one per component. The two Holder instances (first-riser vs default) are told
    apart by height <-> card capacity with a sanity gate. Lid and Toppers stay on
    the per-part-studio path (the lid can't be reconfigured per-game in the
    assembly; toppers are Innovation-only and would collide with lid lettering).
    - onshape.py: adaptive polling — a learned per-kind delay (starts 10s, backs off
    t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
    [Box L3.18.6.20-Un.3mf, Food Chain Magnate.csv, Holder 6-Un.3mf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]
2026-08-07 FCM 180 Card Un: refresh handcrafted cascade with pipeline components
    Swap the box/holders/pushers/lid in the handcrafted FCM Occ 2U cascade for the
    pipeline-exported components (assembly export + studio lid), keeping its
    hand-packed 3-plate H2C layout. Lid reconciled (11 bodies, Lid -> Lid Body).
    No API calls (local assembly).
    [FCM Occ 2U (180 Card L3-18-6-20-Un).3mf]
2026-08-08 FCM: export remaining components + refresh 264-Un and 180-Sl cascades
    Assembly-export path used for all three remaining FCM cascades' monochrome
    components (180-Sl, 264-Un, 264-Sl) + studio lids — 21 API calls. Refreshed the
    handcrafted 264-Un and 180-Sl cascades by swapping in the pipeline components
    (lid reconciled, 11 bodies), keeping their hand-packed 3-plate layouts.
    264-Sl deferred: its sleeved-M box + 3 pushers + 4 wide holders don't re-pack
    onto 3 P1 plates via make_cascade's rotate-to-fit packer the way the hand layout
    did (box alone is 277mm on a 256 bed). Needs a layout decision.
    [Box L3.18.6.32-Sl.3mf, Box M4.18.12.32-Un.3mf, Box M4.18.12.45-Sl.3mf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]
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2026-08-08 FCM: all 4 cascades refreshed at v6.4 with reverted card thickness
    Re-exported every FCM component (16, 28 API calls) after reverting the sleeved
    card-thickness change and bumping the embossed version to 6.4. Rebuilt all four
    cascades via make_cascade --keep-layout from the ORIGINAL hand-crafted templates
    (from git), so their hand-packed 3-plate layouts are preserved exactly (item
    transforms 100% identical) — this also supersedes the earlier re-packed 264-Un /
    180-Un / 180-Sl versions, and unblocks 264-Sl, which now fits again.
    Card-thickness bug confirmed sleeved-only, scaling with card count (180-Sl
    -1.80mm depth, 264-Sl +3.30mm); reverted.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
    [Box L3.18.6.20-Un.3mf, Box L3.18.6.32-Sl.3mf, Box M4.18.12.32-Un.3mf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]
2026-08-08 make_cascade keep-layout: re-rest objects on z=0
    --keep-layout kept the template's Z translation along with x/y, so a swapped
    mesh of a different height sat wrong — the FCM holders (taller than the old ones)
    punched ~7.8mm through the plate. Now keep x/y + rotation from the template but
    recompute each item (and assemble_item) Z so every object rests on z=0. Rebuilt
    all four FCM cascades; all objects now seat flush.
    [FCM Occ 1S (264 Card M4-18-12-45-Sl).3mf, FCM Occ 1U (264 Card M4-18-12-32-Un).3mf, FCM Occ 2S (180 Card L3-18-6-20-Sl).3mf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]
2026-08-09 Dominion 400-card cascades: regenerate at v6.4 via export pipeline
    Export M8.40.10.62 components (Un+Sl) from Onshape — Box, Lid, Holder,
    Pusher, TokenHolder — via the assembly+lid path (14 API calls). Extract
    the HalfTokenHolder from the assembly export and add both token-holder
    types to each cascade.
    Rebuild CC 400U/400S with make_cascade --keep-layout: Box/Lid refreshed
    to 6.4, new taller Holder, corrected Full/Half token holders; original
    plate layouts preserved. Track individual/Dominion components + provenance.
    [Box M8.40.10.62-Sl merged.3mf, Box M8.40.10.62-Un merged.3mf, CC 400S M8-40-10-62-M-Sl.3mf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]
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2026-08-09 Interactive end-to-end cascade refresh + standardized naming
    Add automation/refresh_cascades.py: a filtered, interactive refresh that
    chains PLAN -> EXPORT -> ASSEMBLE with confirmation prompts. Filter by
    --game/--size/--sleeving/--name (AND-combined); --auto skips the two offline
    prompts but the Onshape EXPORT step always confirms the API spend. ASSEMBLE
    uses make_cascade --keep-layout, mapping each component to its template slot
    by ROLE (templates suffix objects: Lid 400S, Topper Cities S-Un, TokenHolder
    Full/Half, bare Topper=Blank). It refuses rather than half-swapping when the
    mapping isn't a clean bijection, a component is off disk, or a first-riser
    Holder needs a per-instance override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
    [Dominion 168 Card Sleeved (S4.16.10.32-Sl).3mf, Dominion 168 Card Unsleeved (S4.16.10.32-Un).3mf, Dominion 202 Card (Mat) Sleeved (M4.21.10.45-Sl).3mf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]
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2026-08-09 Make Dominion token holders data-driven via parts.csv TokenHolder column
    Token holders belong only to sets whose expansions need them, so replace the
    blanket Dominion `extras: [TokenHolder]` + Mat-only `merged_extras` with a
    per-row `TokenHolder` column (none/full/full+half). The planner reads it:
    `full` adds a TokenHolder, `full+half` (the Mat boxes) also adds a
    HalfTokenHolder. Seeded from the templates — 246 (Bulky Base Cards) = none,
    202/290/400 (Mat) = full+half, other Dominion = full; 202 gains the half per
    Allan. No more spurious token holder planned for 246.
    [parts.csv]
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2026-08-09 Dominion 202+400 (Mat): promote rebuilt cascades on P1
    Replace 400-Un and both 202 (Mat) cascade projects with auto-plates rebuilds:
    - auto-bed selected P1 (P1P profile) for all three; box/lid rotated 45°,
    holders in a rotated band, pushers on their own plate
    - 202-Un/Sl now carry the HalfTokenHolder they were missing (Full + Half)
    - token holders named TokenHolder Full/Half, so all three are cleanly
    keep-layout-refreshable going forward
    [Dominion 202 Card (Mat) Sleeved (M4.21.10.45-Sl).3mf, Dominion 202 Card (Mat) Unsleeved (M4.21.10.32-Un).3mf, Dominion 400 Card (Mat) Unsleeved (M8.40.10.62-Un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]
2026-08-09 Innovation 270-Sl: rename to .62 side-label width (no rebuild needed)
    The cascade already contains the correct current sleeved box (Box
    S5.15.15.62-Sl, 82.6mm deep); it was just misnamed with the .45 unsleeved
    side-label width. The model-code suffix is the side-label width (sleeved boxes
    are deeper and take the 62mm label), not a box-body dimension — so a rename to
    S5.15.15.62-Sl is the fix, matching parts.csv. Resolves the refresh tool's
    name-mismatch skip for this cascade.
    [Innovation 270 Card Sleeved (S5.15.15.62-Sl).3mf]
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2026-08-09 Token holders: depth-gate the half instead of the Mat flag
    A half token holder is useless if the full holder's pocket is too shallow to
    split. Replace the manual full/full+half column with a has-token-holder flag
    (full/none) and derive the half: add it only when the exported full holder's
    shallowest dimension is >=10mm. M holders (14.4mm Un / 23.2mm Sl) qualify; S/L
    are decided once their component is exported. Fixes the intent for 168 (full
    only) and makes the rule geometry-driven.
    [parts.csv]
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2026-08-09 Dominion 168: rebuild both cascades on P1 with full token holder
    Export S4.16.10 box/lid/token-holder for both sleevings (14 API calls, YTD
    264/2500; Pusher 4x10 + Holder 10 reused from 202). Rebuild both 168 cascades
    via auto-plates on P1P: the loose "Part 1" token holder is renamed to a clean
    TokenHolder and placed on its own plate. Full holder only — the S holder's
    pocket is 5.3mm (Un) / 8.8mm (Sl), below the 10mm half-holder threshold. Fixed
    the Un lid body, which was mis-assigned to a stray red filament, back to white.
    Records the S4.16.10 components, provenance and the API ledger.
    [Box S4.16.10.32-Sl.3mf, Box S4.16.10.32-Un.3mf, Dominion 168 Card Sleeved (S4.16.10.32-Sl).3mf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]
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2026-08-09 Token holders: key by (capacity, merged, sleeved); rename to true identity
    The token holder fits the box's front pocket, so it varies by front capacity,
    Mat-ness and sleeving — not just size. Re-key both full and half accordingly
    (file: "TokenHolder <cap>-<slv>[ merged]"). The old (size, sleeved) key had
    collapsed every M box onto one file, so rename the on-disk components to what
    they actually are, by origin export: TokenHolder M -> 40 merged (400's),
    HalfTokenHolder M -> 21 merged (202's, which had overwritten 400's), TokenHolder
    S -> 16 (168's). The plan now correctly shows 202/400-half/472 and the
    unexported boxes as needing recovery.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
    [Assembly M2.60.18-40.45-Un.3mf, Assembly M2.60.18-40.62-Sl.3mf, Dominion.csv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]
2026-08-09 Dominion 472: recover cap-60 token holder from cached assembly (0 API calls)
    The 472 raw assemblies (downloaded manually into _raw/) are re-split locally via
    assembly_split — no Onshape calls, no credentials — to write the correct cap-60
    non-Mat TokenHolder 60-{Un,Sl} (narrower + deeper than the Mat one it had wrongly
    shared). Also commits the raw assemblies as the recovery cache.
    [Dominion.csv, TokenHolder 60-Sl.3mf, TokenHolder 60-Un.3mf]
2026-08-09 Dominion 246 + 472: promote first-riser rebuilds on P1/H2C
    Replace the four first-riser cascades with auto-plates rebuilds: the first-riser
    holder is a distinct FirstHolder object, and 472 carries its correct cap-60
    non-Mat token holder and 3 pushers. 246 on P1; 472-Un on P1, 472-Sl on H2C.
    [Dominion 246 Card Sleeved (S2.40.12-30.45-Sl).3mf, Dominion 246 Card Unsleeved (S2.40.12-30.32-Un).3mf, Dominion 472 Card Sleeved (M2.60.18-40.62-Sl).3mf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]
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2026-08-09 Dominion 400: recover its own cap-40 half token holder from cached assembly
    Re-split the 400 raw assemblies (downloaded into _raw/) locally — 0 API calls —
    to write HalfTokenHolder 40-{Un,Sl} merged (400's own half, 9.4/13.8mm deep,
    matching what's already baked into the 400 cascade) and refresh TokenHolder 40.
    The on-disk half had been 202's cap-21 one; 400's component set is now correct
    and self-consistent (the printed 400 cascade was already right, so no rebuild).
    [Assembly M8.40.10.62-Sl merged.3mf, Assembly M8.40.10.62-Un merged.3mf, Dominion.csv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]
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
